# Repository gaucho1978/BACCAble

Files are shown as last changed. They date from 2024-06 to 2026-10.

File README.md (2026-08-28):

## BACCAble 

Website with full info: https://www.tr3ma.com/baccable

Direct contact: https://t.me/gaucholivido

Telegram group for BACCABLE: https://t.me/baccable 

Please donate, with Paypal or Crypto (Bitcoin)

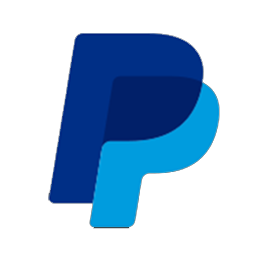
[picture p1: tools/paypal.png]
PayPal (https://www.paypal.me/tr3ma1)

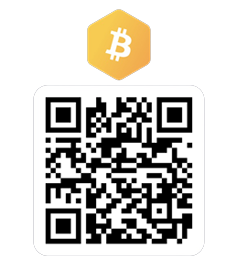
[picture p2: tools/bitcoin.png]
Bitcoin


## CREDITS

*"None of us got where we are solely by pulling ourselves up by our bootstraps. We got here because somebody — a parent, a teacher, an Ivy League crony or a few nuns — bent down and helped us pick up our boots"* Cit. Thurgood Marshall.

Thanks Sniz https://alfatuning.app/

Thanks Alexey, Alfaobd developer https://www.alfaobd.com/

Thanks normaldotcom https://github.com/normaldotcom/canable-fw

Thanks Danardi https://github.com/danardi78/Alfaromeo-Giulia-Stelvio-PIDs/

Thanks Alessandro https://github.com/anegrin

Thanks Ambrotek, Arfa, Tim, Gev, and all the Baccable Community

## DISCLAIMER

BACCABLE is a project developed exclusively for educational and research purposes. The use of this tool on vehicles operating on public roads or in any context that may cause harm to people, property, or violate applicable regulations is strictly prohibited.

The author of this project assumes no responsibility for any damages, malfunctions, or consequences resulting from the use of BACCABLE. The end user bears full civil, criminal, and legal responsibility for its use.

It is strongly recommended not to use this project in real-world vehicle applications.

## DISCLAIMER (ITALIAN VERSION)
BACCABLE è un progetto sviluppato esclusivamente a scopo didattico e di studio. È severamente vietato utilizzare questo strumento su veicoli in circolazione su strade pubbliche o in qualsiasi contesto che possa causare danni a persone, cose o violare normative vigenti.

L'autore del progetto non si assume alcuna responsabilità per eventuali danni, malfunzionamenti o conseguenze derivanti dall'uso di BACCABLE. L'utilizzo di questo strumento è interamente a rischio dell'utente finale, che si assume ogni responsabilità civile, penale e legale.

Si raccomanda di non impiegare questo progetto in applicazioni reali su veicoli.

## Scope
Baccable is able to communicate over can bus on Giulia and Stelvio veichles to implement many functions.
It is available with custom COMPACT board, or, just for partial testing, can be made with canable or ucan boards with some limits. The custom board integrates, on a single board, 3 ST chips, one for each CAN bus, along with efficient power consumption and optimized electromagnetic interference management for the vehicle. It includes additional expansions ports for valves remote control, or any other remote control (in example automatic driveway  gate), dedicated connector for external pedal booster (schizzaForte is the Baccable pedal booster, installed on the accelerator, allows automatic map set according to the selected drive style).
All functions and manuals are available on https://www.tr3ma.com/baccable 
Baccable can be supplied already programmed, ready to plug in diagnostic port.
If you want a ready made Baccable, required info are on https://www.tr3ma.com/baccable

Following info are only for those using canable or ucan boards

## Developers info
I started the development from the famous SLCAN firmware (https://github.com/normaldotcom/canable-fw), by porting it inside stm32Cube environment (I updated usb interface), then I added all the functions described in the manuals.

## Folders content
- Subfolder firmware contains the firmware
- Subfolder hardware/canable contains canable board layout and pcb wiring diagram. It comes from https://github.com/makerbase-mks/CANable-MKS. There are different designs of canable, but theay are all similar.
- Subfolder hardware/box contains the 3d model of the cases to accomodate required components.
- Subfolder hardware/system interconnection contains interconnection diagram to connect required components
- Subfolder tools contains the famous savvyCan sniffer tool for windows (portable) and excel sheet used to calculate pwm and clocks settings.
- Subfolder hardware/newBaccableDedicatedPcb contains the new pcb for Baccable
- Subfolder Manuals contains the manuals

## DASHBOARD MENU functionality Notes

For communication between ucan or canable, you will need to connect canable boards as shown in the following reference image:

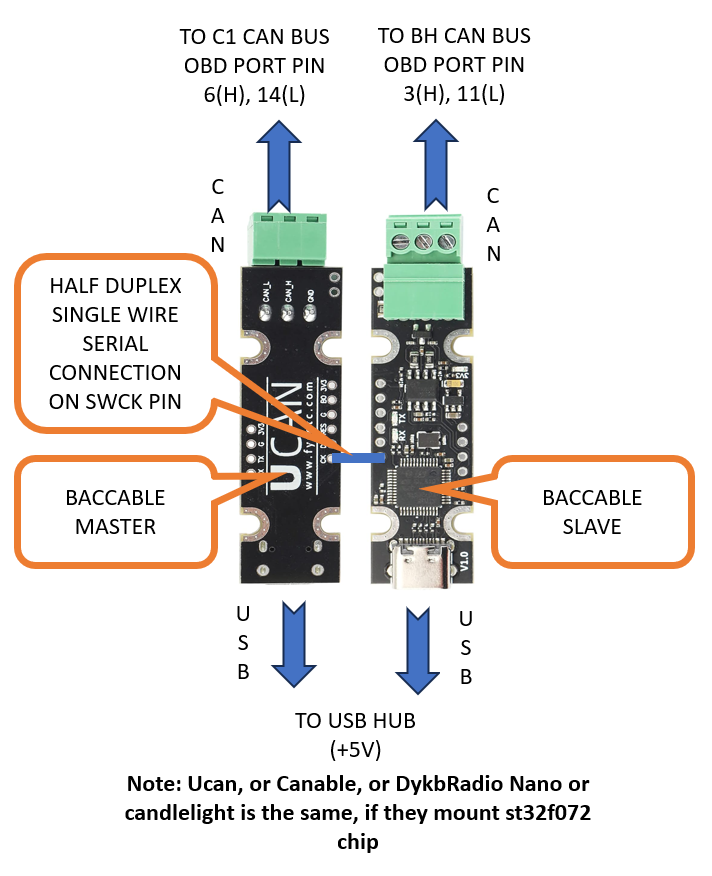
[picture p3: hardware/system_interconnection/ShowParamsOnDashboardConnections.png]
DashboardFunctionInterconnections


## Firmware notes

Note1: The parameters array is customizable

This is the structure of each element:
 
- name[15]:						It is the name of the parameter. shall be short otherwise the string will be cutted and not entirely shown in dashoard 
- reqId:						It is the msg id to request in UDS command. It Typically starts with 18DA....
- reqLen:						It is the total length of the can message to send
- reqData:						It is the entire can message to send. It follows the following UDS syntax:
								First byte is the length of the following bytes, 
								Second byte is the requested service (tipically 0x22, request parameter by ID),
								Third and fourth byte are the DID (the requested parameter).
- replyId:						It is the message ID of the received reply. Tipically if the reqID is 18DAAABB the replyID shall be 18DABBAA
- replyLen:						It is the number of bytes of the parameter that we want to extract from the received message
- replyOffset:					It defines where is located the parameter. 0 means that it is the first byte of the expected field of UDS message, 1 means that we shall start from second byte, and so on.
- replyValOffset: 				Once the parameter is decoded as unsigned integer, the first calculation on the value will be + replyValOffset 
- replyScale:					Once the parameter has been summed with replyValOffset, the result will be multiplied by replyScale
- replyScaleOffset:				Once the parameter has been multiplied by replyScale, the result will be summed to replyScaleOffset
- replyMeasurementUnit[7]:		It is a string appended at the end of the parameter string to define measurement unit. Too long strings will have measurement unit cutted and not shown on the dashboard.
- replyDecimalDigits:			The parameter, after previous calculations, will be converted to string, and rounded to the specified number of decimal digits. 

## BACCABLE Compile Instructions

We introduced automatic compilation on github. Stable releases are downloadable from "Releases" section:  

If you want to compile it on your PC, the easiest way is to use stm32CubeIde software.
Once the project has been opened, select the desired compile option, and the related elf file will be generated under firmware\ledsStripController, in a subfolder named according to the selected compile option. Inside that folder you will find generated elf file.

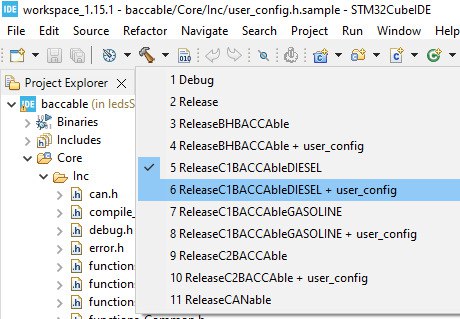
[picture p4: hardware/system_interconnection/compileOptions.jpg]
Compilation Options


select C1, C2, BH release options, depending on the board for which you are compiling it.

Default options are enough for anyone, but if any customization is required, it can be done following instructions contained in file firmware\ledsStripController\Core\Inc\user_config.h.sample

## BACCABLE Flash Instructions

See Manual, paragraph 1.11

## The hardware using CANABLE

I found these compatible devices (It is important that the chip is a stm32F072):

    - Original MKS Canable
    - Canable DykbRadio Nano
    - Fysect ucan
	- candlelight small board ( [https://github.com/linux-automation/candleLightFD](https://github.com/linux-automation/candleLight/) )
		
## Compatible leds strip

Leds Strip ws2811 ip65:  

https://www.ebay.it/itm/325563557492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

https://amzn.to/3W3TifJ

## Usage when configured to act as Canable (Sniffer)
The new function SNIFFER inside Main Setup Menu no more requires to flash dedicated firmware for flashing. See manual.
This section is left for reference.
Old method to flash requires to flash the baccable with another firmware named CANABLE or ACT_AS_CANABLE that you can find in the compiled files.

When flashed with CANABLE firmware, it acts as the classic SLCAN firmware. it means that you can use it with a pc equipped with savvycan tool, in order to sniff packets in the canbus. 
With such configuration the device is seen by the pc as a virtual serial port implementing the following serial commands:

- O - Open channel
- C - Close channel
- S0 - Set bitrate to 10k
- S1 - Set bitrate to 20k
- S2 - Set bitrate to 50k
- S3 - Set bitrate to 100k
- S4 - Set bitrate to 125k
- S5 - Set bitrate to 250k
- S6 - Set bitrate to 500k
- S7 - Set bitrate to 750k
- S8 - Set bitrate to 1M
- M0 - Set mode to normal mode (default)
- M1 - Set mode to silent mode
- A0 - Disable automatic retransmission
- A1 - Enable automatic retransmission (default)
- TIIIIIIIILDD... - Transmit data frame (Extended ID) [ID, length, data]
- tIIILDD... - Transmit data frame (Standard ID) [ID, length, data]
- RIIIIIIIIL - Transmit remote frame (Extended ID) [ID, length]
- rIIIL - Transmit remote frame (Standard ID) [ID, length]
- V - Returns firmware version and remote path as a string
Note: Channel configuration commands must be sent before opening the channel. The channel must be opened before transmitting frames.

This firmware currently does not provide any ACK/NACK feedback for serial commands.

## Understanding LED protocol

The approach used to control WS281x leds strip controller was derived from this: https://github.com/MaJerle/stm32-ws2811-ws2812-ws2812b-ws281x-tim-pwm-dma-timer where it is used a timer to start a pwm, then DMA allows a fast change of the duty cycle of the pwm.

Summarizing, the ws281x uses a control signal where each bit is transmitted as 1 or 0 with a pwm signal (with 2 different duty cycle for 0 and for 1 logic levels).
The ws281x protocol expects a 24 bits sequence (3x8) for each led, where each 8 bits defines a color (red, green and blue). 
First led will get the first 24 bits, then it sends the rest to the next led. each led does the same.
A pause in the transmission determines the end of the frame, then a new frame can be sent.
The protocol and the timings are described in the ws281x datasheet

WS2811 and WS2812 protocol is specific one and has defined values:

- Transfer rate is `800 kHz`, or `1.25us` pulse length for each bit
- Transfer length is `24` pulses for each led, that's `30us` for one LED
- Each logical bit (`1` or `0`) consists of high and low part, with different length
- Reset pulse is needed prior updating led strip, to synchronize sequence

WS2811 & WS2812 & WS2812B LED protocol

> Minimum reset pulse length depends on WS281x device. Check datasheet for your particular unit. WS2812B says `> 50us`, while WS2811 says `> 280us`.

## STM32 DMA

DMA controllers in STM32s support various operations, one of them being super handy for our WS LED driver, called *circular operation mode*.
*Circular mode* will continuously transmit data from memory to peripheral (or, in general, can also go opposite direction) and periodically send *transfer-complete* or *half-transfer-complete* interrupts to the application.

STM32 DMA circular mode

We will use *HT* and *TC* events extensively, as they will be use to *prepare data* for next operations to transfer all bits for all leds.

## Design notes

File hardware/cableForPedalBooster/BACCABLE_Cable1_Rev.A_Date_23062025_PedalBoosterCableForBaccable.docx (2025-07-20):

PEDAL BOOSTER CABLE FOR BACCABLE

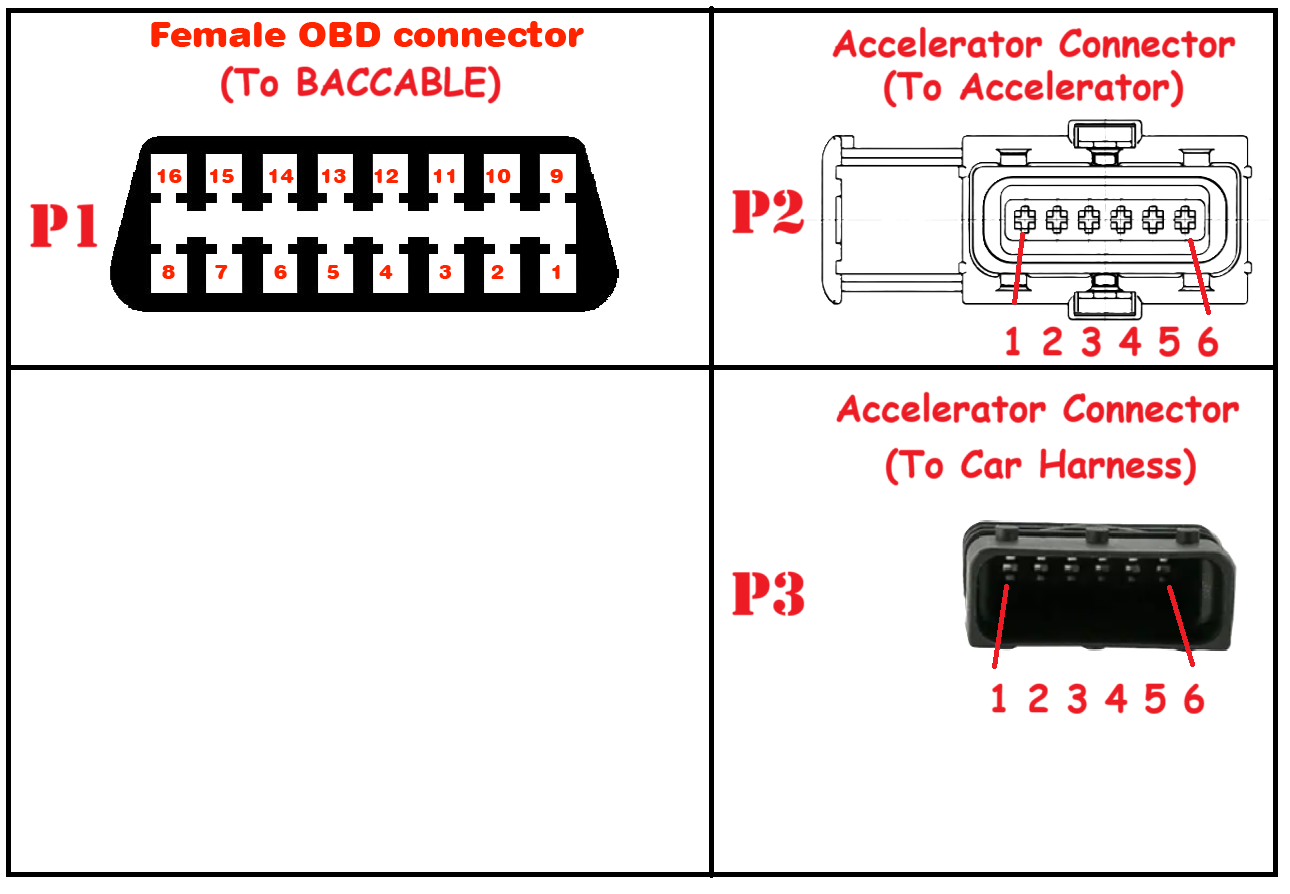
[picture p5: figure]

From Connector | | R101 (200k ohm) R102 (200k ohm) | To Connector
OBD (P1) | 16 (+12V) | | +12V | Car OBD or Car Harness before SGW
| 4 (GND) | | GND
| 6 (C1H) | | Can Bus C1 H
| 14 (C1L) | | Can Bus C1 L
| 12 (C2H) | | Can Bus C2 H
| 13 (C2L) | | Can Bus C2 L
| 3 (BH H) | | Can Bus BH H
| 11 (BH L) | | Can Bus BH L
| | | 1 (V2+) | Accelerator (P2)
| | | 2 (V1+)
| 10 (STS2) | | 3 (Acc1)
| | | 4 (V1-)
| | | 5 (V2-)
| 7 (STS3) | | 6(Acc2)
| | | 2 (V1+) | Accelerator Harness (P3)
| 15 (CMD2) | | 3 (Acc1)
| 4 (GND) | | 4 (V1-)
| 4 (GND) | | 5 (V2-)
| | | 1 (V2+)
| 2 (CMD3) | | 6(Acc2)

BACCABLE_Cable1 Rev.B – Date: 26/06/2025

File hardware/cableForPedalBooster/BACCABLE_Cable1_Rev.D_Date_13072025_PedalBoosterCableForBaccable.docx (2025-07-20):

PEDAL BOOSTER CABLE FOR BACCABLE


From Connector | | | To Connector
OBD (P1) | 16 (+12V) | | 16 (+12V) | Car OBD or Car Harness before SGW
| 4 (GND) | | 4 (GND)
| 6 (C1H) | | 6 (Can Bus C1 H)
| 14 (C1L) | | 14 (Can Bus C1 L)
| 12 (C2H) | | 12 (Can Bus C2 H)
| 13 (C2L) | | 13 (Can Bus C2 L)
| 3 (BH H) | | 3 (Can Bus BH H)
| 11 (BH L) | | 11 (Can Bus BH L)
| | | 1 (V2+) | Accelerator (P2)
| | | 2 (V1+)
| 10 (STS2) | | 3 (Acc1)
| | | 4 (V1-)
| | | 5 (V2-)
| 7 (STS3) | | 6(Acc2)
| 15 Vref2 | | 2 (V1+) | Accelerator Harness (P3)
| 1 (CMD2) | | 3 (Acc1)
| 4 (GND) | | 4 (V1-)
| | | 5 (V2-)
| 2 Vref3 | | 1 (V2+)
| 9 (CMD3) | | 6(Acc2)

BACCABLE_Cable1 Rev.D – Date: 13/07/2025

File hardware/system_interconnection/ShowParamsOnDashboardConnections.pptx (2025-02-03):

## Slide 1

BACCABLE MASTER

HALF DUPLEX SINGLE WIRE SERIAL CONNECTION ON SWCK PIN

USB

CAN

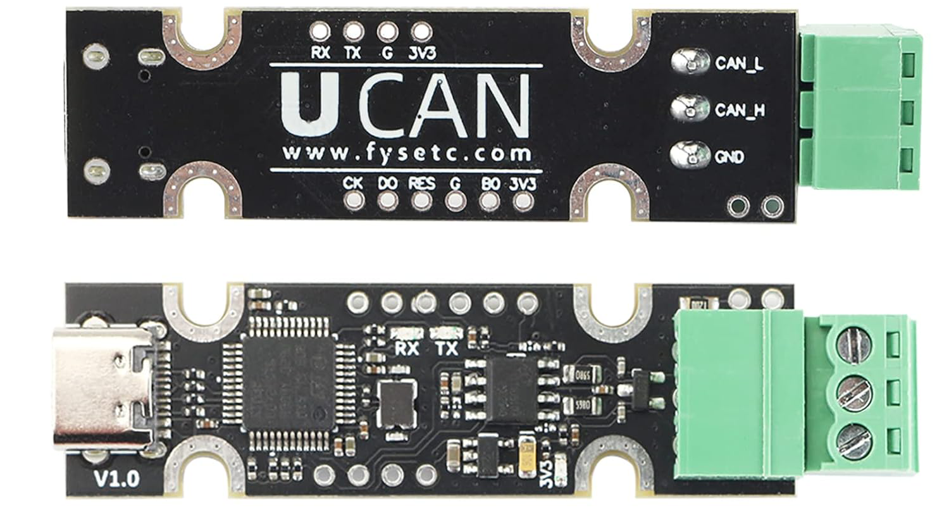
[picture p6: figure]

TO C1 CAN BUS
OBD PORT PIN 6(H), 14(L)

Note: Ucan, or Canable, or DykbRadio Nano or candlelight is the same, if they mount st32f072 chip

TO USB HUB (+5V)

USB

TO BH CAN BUS
OBD PORT PIN 3(H), 11(L)

CAN

BACCABLE SLAVE

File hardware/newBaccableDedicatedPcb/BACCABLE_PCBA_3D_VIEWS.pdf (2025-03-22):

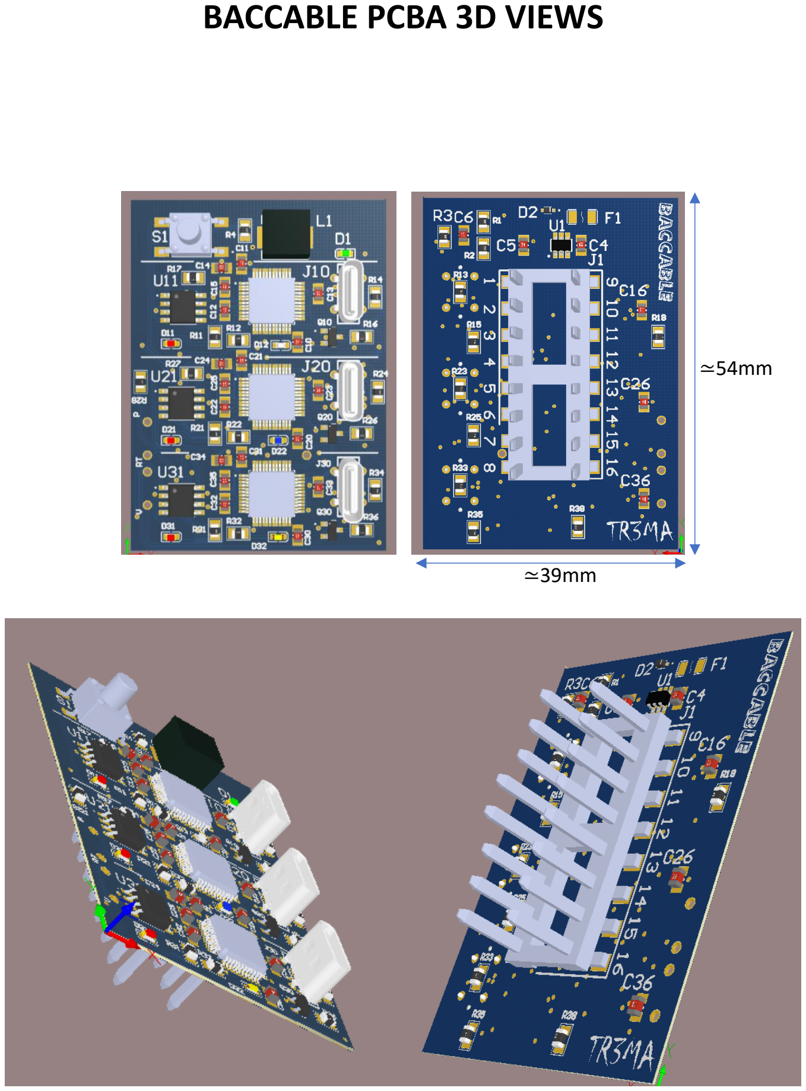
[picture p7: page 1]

BACCABLE PCBA 3D VIEWS

≃39mm

≃54mm

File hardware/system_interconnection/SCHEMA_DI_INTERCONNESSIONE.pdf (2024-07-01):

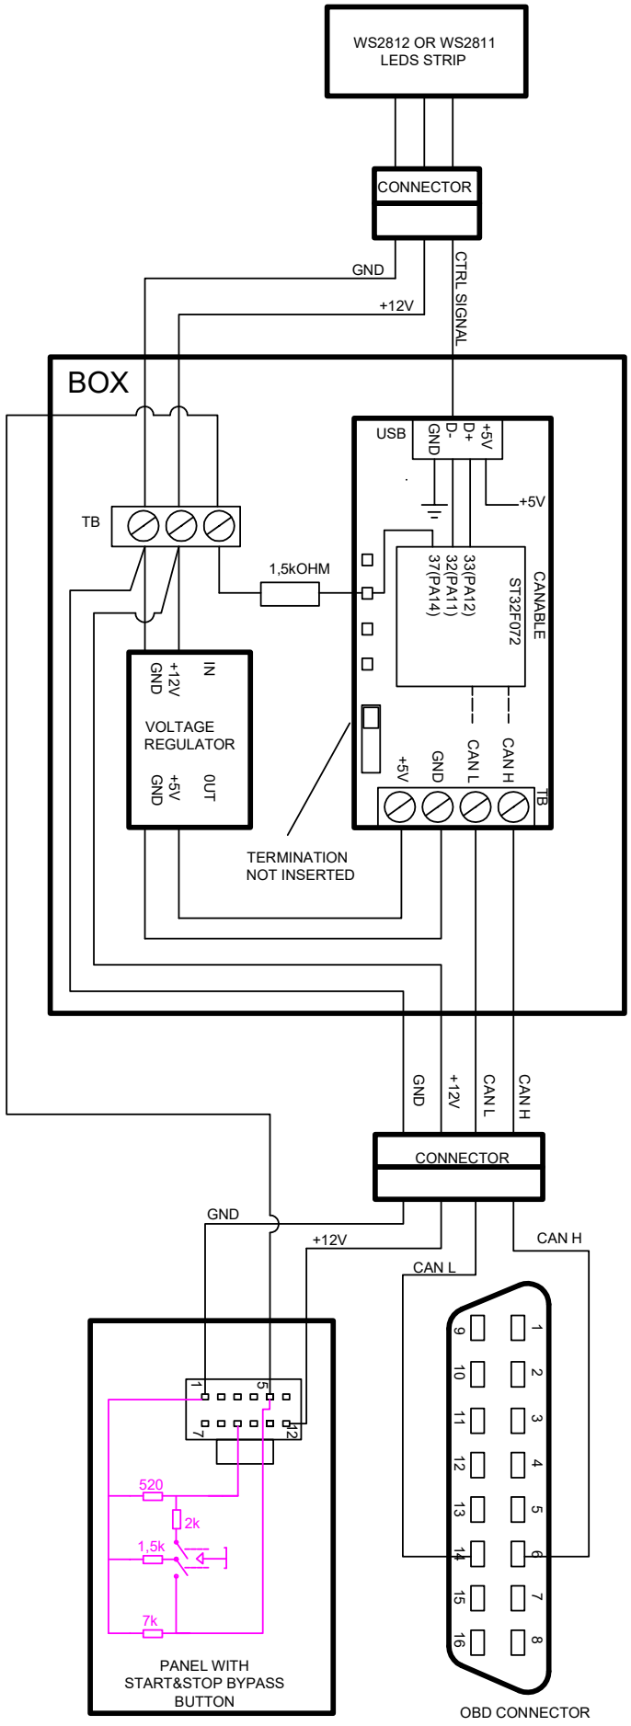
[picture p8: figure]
USB; GND D- D++5V; +5VTB; TERMINATION; NOT INSERTED; CAN L; CAN H GND ⁺⁵V; CANABLE; VOLTAGE; REGULATOR GND ⁺¹²V; IN GND ⁺⁵V; 1,5kOHM; BOX; CTRL SIGNAL +12V; GND; LEDS STRIP GND; CAN H; CONNECTOR; PANEL WITH START&STOP BYPASS BUTTON; CAN L 12; 5 OBD CONNECTOR

1 9 10 11 12 13 14 15 16 1 2 3 4 5 6 7 8

## Note: impedance inside ECU before pin 5= 910ohm impedance inside ECU before pin 9= 99ohm Note2: by using 470 ohm resistor in place of 1,5k you will disable parking acoustic signal (the other button on the panel)

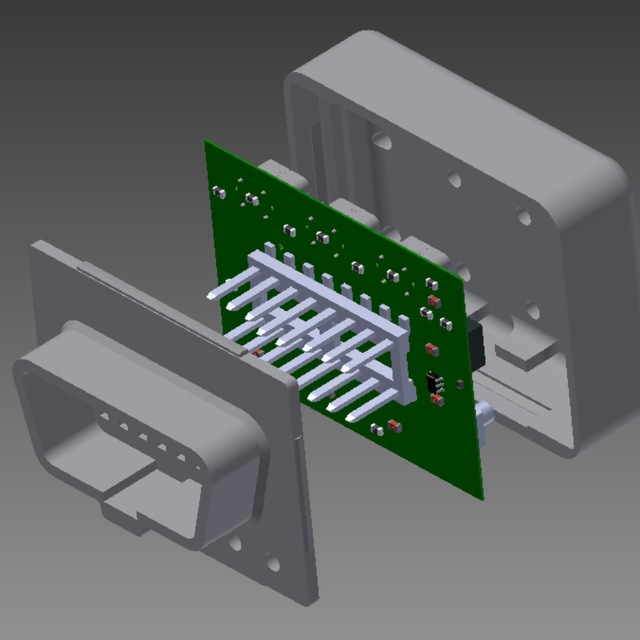
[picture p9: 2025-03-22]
hardware/box/baccable_lastest_case_for_new_PCB/preview.jpg

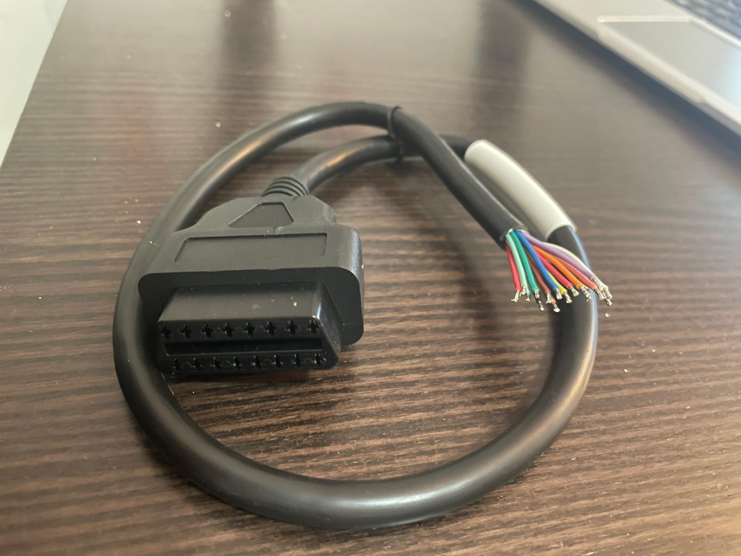
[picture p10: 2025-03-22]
hardware/newBaccableDedicatedPcb/cable.jpg

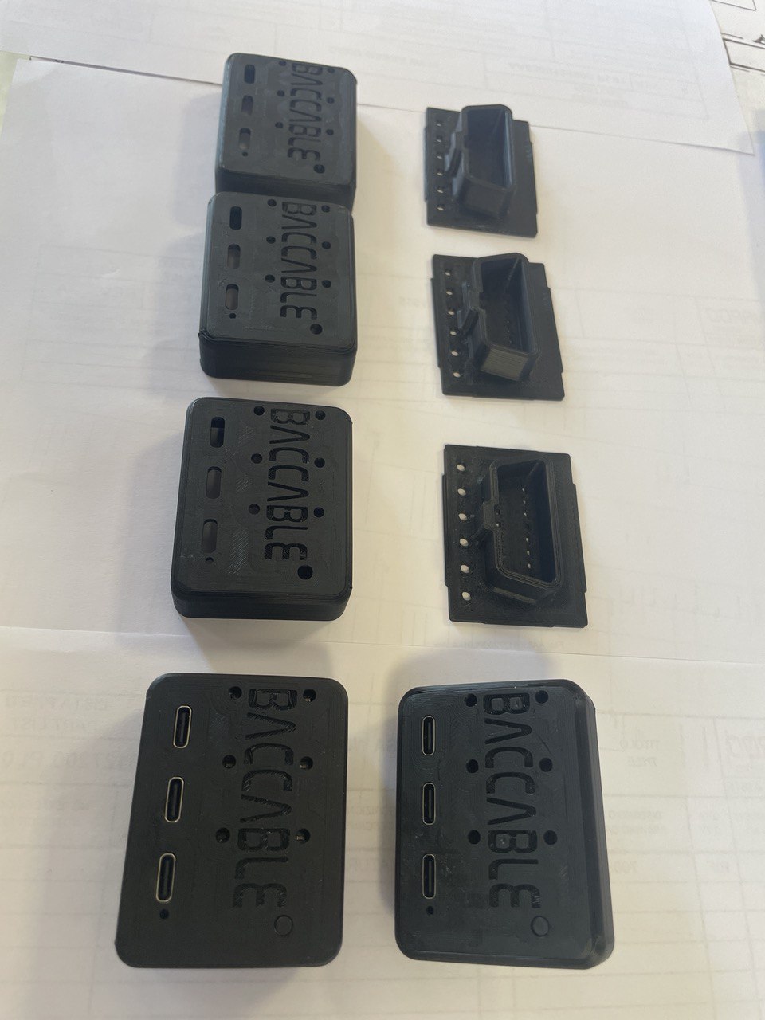
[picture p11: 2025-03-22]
hardware/box/baccable_lastest_case_for_new_PCB/preview4.jpg

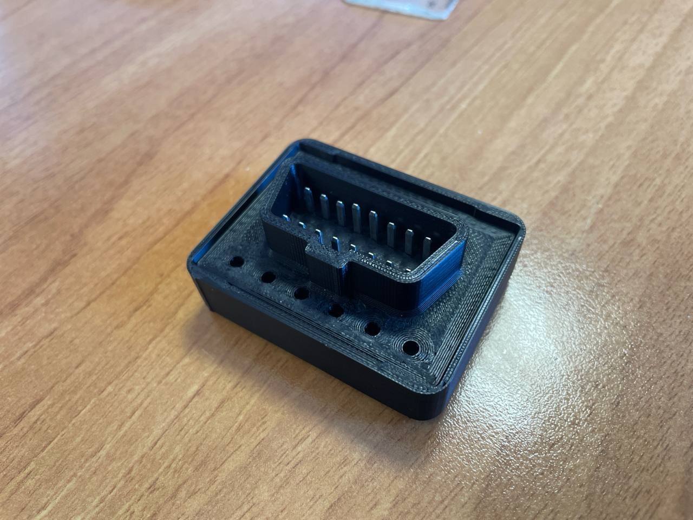
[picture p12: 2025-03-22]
hardware/box/baccable_lastest_case_for_new_PCB/preview3.jpg

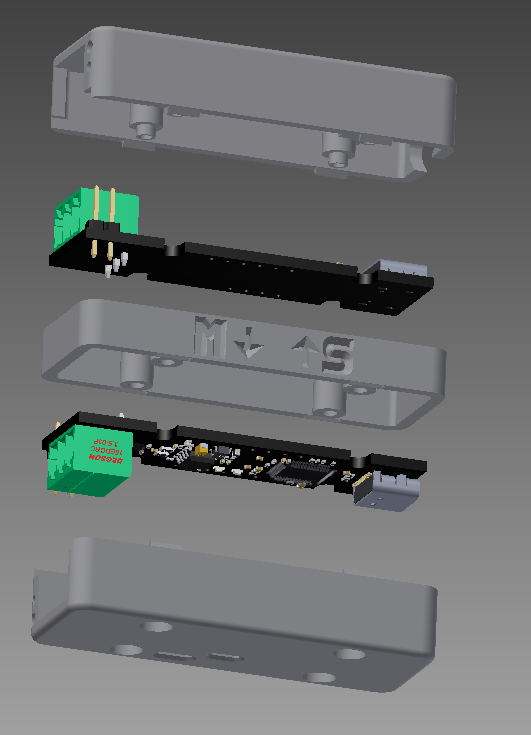
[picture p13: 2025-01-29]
hardware/box/dual_fysect_ucan/preview.png

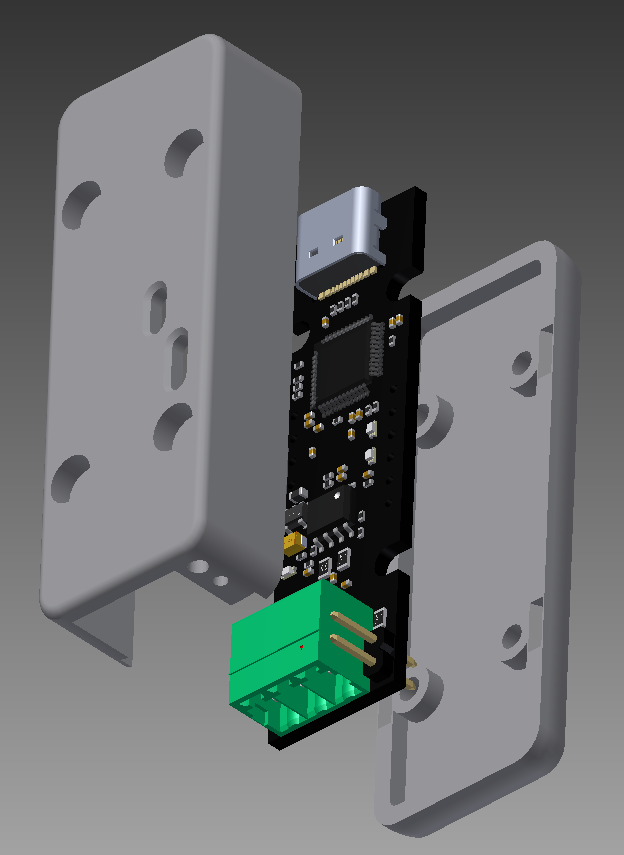
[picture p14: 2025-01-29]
hardware/box/single_fysect_ucan/preview.png

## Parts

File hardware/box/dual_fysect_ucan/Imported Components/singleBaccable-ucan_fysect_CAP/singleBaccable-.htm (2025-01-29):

Autodesk Inventor Translation Report | giovedì 23 gennaio 2025 (19:19)
Source File: | E:\Dati\Documenti_Emanuele\Linguaggi_di_Programmazione\ST MCU\baccable\canable\CANableAndLedsStripController\hardware\box\dual fysect ucan\singleBaccable-ucan_fysect_CAP.stl
Translator Type: | STL | Sending System:
Author: |  | Translation Time: | 00:00:00
Options
Import Type: | N/A
Entity Types to Import: | Meshes
Import into Repair Environment: | N/A
Import Assembly as Single Part: | N/A
Create Surfaces As: | N/A
Check Parts during Load: | N/A
Auto Stitch: | N/A
Enable Advanced Healing: | N/A
Color Red/Green/Blue Order: | RGB
+/- | Name | Inventor File | Status
[ ] | singleBaccable-.ipt | E:\Dati\Documenti_Emanuele\Linguaggi_di_Programmazione\ST MCU\baccable\canable\CANableAndLedsStripController\hardware\box\dual fysect ucan\Imported Components\singleBaccable-ucan_fysect_CAP\singleBaccable-.ipt | Successful

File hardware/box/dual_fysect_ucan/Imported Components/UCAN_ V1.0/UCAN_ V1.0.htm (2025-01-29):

Autodesk Inventor Translation Report | giovedì 23 gennaio 2025 (19:20)
Source File: | E:\Dati\Documenti_Emanuele\Linguaggi_di_Programmazione\ST MCU\baccable\canable\CANableAndLedsStripController\hardware\box\dual fysect ucan\UCAN_ V1.0.step
Translator Type: | STEP | Sending System: | Open CASCADE 7.5
Author: | Author | Translation Time: | 00:00:12
Options
Import Type: | N/A
Entity Types to Import: | Solids, Surfaces, Wires, Points
Import into Repair Environment: | Yes
Import Assembly as Single Part: | No
Create Surfaces As: | Single Composite Feature
Check Parts during Load: | No
Auto Stitch: | No
Enable Advanced Healing: | N/A
+/- | Name | Inventor File | Status
[ ] | UCAN_ V1.0.iam | E:\Dati\Documenti_Emanuele\Linguaggi_di_Programmazione\ST MCU\baccable\canable\CANableAndLedsStripController\hardware\box\dual fysect ucan\Imported Components\UCAN_ V1.0\UCAN_ V1.0.iam | Successful
[ ] | Open CASCADE STEP translator 7.5 1.ipt | E:\Dati\Documenti_Emanuele\Linguaggi_di_Programmazione\ST MCU\baccable\canable\CANableAndLedsStripController\hardware\box\dual fysect ucan\Imported Components\UCAN_ V1.0\Open CASCADE STEP translator 7.5 1.ipt | Successful
[ ] | Open CASCADE STEP translator 7.5 2.ipt | E:\Dati\Documenti_Emanuele\Linguaggi_di_Programmazione\ST MCU\baccable\canable\CANableAndLedsStripController\hardware\box\dual fysect ucan\Imported Components\UCAN_ V1.0\Open CASCADE STEP translator 7.5 2.ipt | Successful
[ ] | Open CASCADE STEP translator 7.5 3.ipt | E:\Dati\Documenti_Emanuele\Linguaggi_di_Programmazione\ST MCU\baccable\canable\CANableAndLedsStripController\hardware\box\dual fysect ucan\Imported Components\UCAN_ V1.0\Open CASCADE STEP translator 7.5 3.ipt | Successful
[ ] | Open CASCADE STEP translator 7.5 4.ipt | E:\Dati\Documenti_Emanuele\Linguaggi_di_Programmazione\ST MCU\baccable\canable\CANableAndLedsStripController\hardware\box\dual fysect ucan\Imported Components\UCAN_ V1.0\Open CASCADE STEP translator 7.5 4.ipt | Successful
[ ] | Open CASCADE STEP translator 7.5 5.ipt | E:\Dati\Documenti_Emanuele\Linguaggi_di_Programmazione\ST MCU\baccable\canable\CANableAndLedsStripController\hardware\box\dual fysect ucan\Imported Components\UCAN_ V1.0\Open CASCADE STEP translator 7.5 5.ipt | Successful
[ ] | Open CASCADE STEP translator 7.5 6.ipt | E:\Dati\Documenti_Emanuele\Linguaggi_di_Programmazione\ST MCU\baccable\canable\CANableAndLedsStripController\hardware\box\dual fysect ucan\Imported Components\UCAN_ V1.0\Open CASCADE STEP translator 7.5 6.ipt | Successful
[ ] | Open CASCADE STEP translator 7.5 7.ipt | E:\Dati\Documenti_Emanuele\Linguaggi_di_Programmazione\ST MCU\baccable\canable\CANableAndLedsStripController\hardware\box\dual fysect ucan\Imported Components\UCAN_ V1.0\Open CASCADE STEP translator 7.5 7.ipt | Successful
[ ] | Open CASCADE STEP translator 7.5 8.ipt | E:\Dati\Documenti_Emanuele\Linguaggi_di_Programmazione\ST MCU\baccable\canable\CANableAndLedsStripController\hardware\box\dual fysect ucan\Imported Components\UCAN_ V1.0\Open CASCADE STEP translator 7.5 8.ipt | Successful
[ ] | Open CASCADE STEP translator 7.5 9.ipt | E:\Dati\Documenti_Emanuele\Linguaggi_di_Programmazione\ST MCU\baccable\canable\CANableAndLedsStripController\hardware\box\dual fysect ucan\Imported Components\UCAN_ V1.0\Open CASCADE STEP translator 7.5 9.ipt | Successful
[ ] | Open CASCADE STEP translator 7.5 10.ipt | E:\Dati\Documenti_Emanuele\Linguaggi_di_Programmazione\ST MCU\baccable\canable\CANableAndLedsStripController\hardware\box\dual fysect ucan\Imported Components\UCAN_ V1.0\Open CASCADE STEP translator 7.5 10.ipt | Successful
[ ] | Open CASCADE STEP translator 7.5 11.ipt | E:\Dati\Documenti_Emanuele\Linguaggi_di_Programmazione\ST MCU\baccable\canable\CANableAndLedsStripController\hardware\box\dual fysect ucan\Imported Components\UCAN_ V1.0\Open CASCADE STEP translator 7.5 11.ipt | Successful
[ ] | Open CASCADE STEP translator 7.5 12.ipt | E:\Dati\Documenti_Emanuele\Linguaggi_di_Programmazione\ST MCU\baccable\canable\CANableAndLedsStripController\hardware\box\dual fysect ucan\Imported Components\UCAN_ V1.0\Open CASCADE STEP translator 7.5 12.ipt | Successful
[ ] | Open CASCADE STEP translator 7.5 13.ipt | E:\Dati\Documenti_Emanuele\Linguaggi_di_Programmazione\ST MCU\baccable\canable\CANableAndLedsStripController\hardware\box\dual fysect ucan\Imported Components\UCAN_ V1.0\Open CASCADE STEP translator 7.5 13.ipt | Successful
[ ] | Open CASCADE STEP translator 7.5 14.ipt | E:\Dati\Documenti_Emanuele\Linguaggi_di_Programmazione\ST MCU\baccable\canable\CANableAndLedsStripController\hardware\box\dual fysect ucan\Imported Components\UCAN_ V1.0\Open CASCADE STEP translator 7.5 14.ipt | Successful
[ ] | Open CASCADE STEP translator 7.5 15.ipt | E:\Dati\Documenti_Emanuele\Linguaggi_di_Programmazione\ST MCU\baccable\canable\CANableAndLedsStripController\hardware\box\dual fysect ucan\Imported Components\UCAN_ V1.0\Open CASCADE STEP translator 7.5 15.ipt | Successful
[ ] | Open CASCADE STEP translator 7.5 16.ipt | E:\Dati\Documenti_Emanuele\Linguaggi_di_Programmazione\ST MCU\baccable\canable\CANableAndLedsStripController\hardware\box\dual fysect ucan\Imported Components\UCAN_ V1.0\Open CASCADE STEP translator 7.5 16.ipt | Successful
[ ] | Open CASCADE STEP translator 7.5 17.ipt | E:\Dati\Documenti_Emanuele\Linguaggi_di_Programmazione\ST MCU\baccable\canable\CANableAndLedsStripController\hardware\box\dual fysect ucan\Imported Components\UCAN_ V1.0\Open CASCADE STEP translator 7.5 17.ipt | Successful
[ ] | Open CASCADE STEP translator 7.5 18.ipt | E:\Dati\Documenti_Emanuele\Linguaggi_di_Programmazione\ST MCU\baccable\canable\CANableAndLedsStripController\hardware\box\dual fysect ucan\Imported Components\UCAN_ V1.0\Open CASCADE STEP translator 7.5 18.ipt | Successful
[ ] | Open CASCADE STEP translator 7.5 19.ipt | E:\Dati\Documenti_Emanuele\Linguaggi_di_Programmazione\ST MCU\baccable\canable\CANableAndLedsStripController\hardware\box\dual fysect ucan\Imported Components\UCAN_ V1.0\Open CASCADE STEP translator 7.5 19.ipt | Successful
[ ] | Open CASCADE STEP translator 7.5 20.ipt | E:\Dati\Documenti_Emanuele\Linguaggi_di_Programmazione\ST MCU\baccable\canable\CANableAndLedsStripController\hardware\box\dual fysect ucan\Imported Components\UCAN_ V1.0\Open CASCADE STEP translator 7.5 20.ipt | Successful
[ ] | Open CASCADE STEP translator 7.5 21.ipt | E:\Dati\Documenti_Emanuele\Linguaggi_di_Programmazione\ST MCU\baccable\canable\CANableAndLedsStripController\hardware\box\dual fysect ucan\Imported Components\UCAN_ V1.0\Open CASCADE STEP translator 7.5 21.ipt | Successful
[ ] | Open CASCADE STEP translator 7.5 22.ipt | E:\Dati\Documenti_Emanuele\Linguaggi_di_Programmazione\ST MCU\baccable\canable\CANableAndLedsStripController\hardware\box\dual fysect ucan\Imported Components\UCAN_ V1.0\Open CASCADE STEP translator 7.5 22.ipt | Successful
[ ] | Open CASCADE STEP translator 7.5 23.ipt | E:\Dati\Documenti_Emanuele\Linguaggi_di_Programmazione\ST MCU\baccable\canable\CANableAndLedsStripController\hardware\box\dual fysect ucan\Imported Components\UCAN_ V1.0\Open CASCADE STEP translator 7.5 23.ipt | Successful
[ ] | Open CASCADE STEP translator 7.5 24.ipt | E:\Dati\Documenti_Emanuele\Linguaggi_di_Programmazione\ST MCU\baccable\canable\CANableAndLedsStripController\hardware\box\dual fysect ucan\Imported Components\UCAN_ V1.0\Open CASCADE STEP translator 7.5 24.ipt | Successful
[ ] | Open CASCADE STEP translator 7.5 25.ipt | E:\Dati\Documenti_Emanuele\Linguaggi_di_Programmazione\ST MCU\baccable\canable\CANableAndLedsStripController\hardware\box\dual fysect ucan\Imported Components\UCAN_ V1.0\Open CASCADE STEP translator 7.5 25.ipt | Successful
[ ] | Open CASCADE STEP translator 7.5 26.ipt | E:\Dati\Documenti_Emanuele\Linguaggi_di_Programmazione\ST MCU\baccable\canable\CANableAndLedsStripController\hardware\box\dual fysect ucan\Imported Components\UCAN_ V1.0\Open CASCADE STEP translator 7.5 26.ipt | Successful
[ ] | Open CASCADE STEP translator 7.5 27.ipt | E:\Dati\Documenti_Emanuele\Linguaggi_di_Programmazione\ST MCU\baccable\canable\CANableAndLedsStripController\hardware\box\dual fysect ucan\Imported Components\UCAN_ V1.0\Open CASCADE STEP translator 7.5 27.ipt | Successful
[ ] | Open CASCADE STEP translator 7.5 28.ipt | E:\Dati\Documenti_Emanuele\Linguaggi_di_Programmazione\ST MCU\baccable\canable\CANableAndLedsStripController\hardware\box\dual fysect ucan\Imported Components\UCAN_ V1.0\Open CASCADE STEP translator 7.5 28.ipt | Successful
[ ] | Open CASCADE STEP translator 7.5 29.ipt | E:\Dati\Documenti_Emanuele\Linguaggi_di_Programmazione\ST MCU\baccable\canable\CANableAndLedsStripController\hardware\box\dual fysect ucan\Imported Components\UCAN_ V1.0\Open CASCADE STEP translator 7.5 29.ipt | Successful
[ ] | Open CASCADE STEP translator 7.5 30.ipt | E:\Dati\Documenti_Emanuele\Linguaggi_di_Programmazione\ST MCU\baccable\canable\CANableAndLedsStripController\hardware\box\dual fysect ucan\Imported Components\UCAN_ V1.0\Open CASCADE STEP translator 7.5 30.ipt | Successful
[ ] | Open CASCADE STEP translator 7.5 31.ipt | E:\Dati\Documenti_Emanuele\Linguaggi_di_Programmazione\ST MCU\baccable\canable\CANableAndLedsStripController\hardware\box\dual fysect ucan\Imported Components\UCAN_ V1.0\Open CASCADE STEP translator 7.5 31.ipt | Successful
[ ] | Open CASCADE STEP translator 7.5 32.ipt | E:\Dati\Documenti_Emanuele\Linguaggi_di_Programmazione\ST MCU\baccable\canable\CANableAndLedsStripController\hardware\box\dual fysect ucan\Imported Components\UCAN_ V1.0\Open CASCADE STEP translator 7.5 32.ipt | Successful
[ ] | Open CASCADE STEP translator 7.5 33.ipt | E:\Dati\Documenti_Emanuele\Linguaggi_di_Programmazione\ST MCU\baccable\canable\CANableAndLedsStripController\hardware\box\dual fysect ucan\Imported Components\UCAN_ V1.0\Open CASCADE STEP translator 7.5 33.ipt | Successful
[ ] | Open CASCADE STEP translator 7.5 34.ipt | E:\Dati\Documenti_Emanuele\Linguaggi_di_Programmazione\ST MCU\baccable\canable\CANableAndLedsStripController\hardware\box\dual fysect ucan\Imported Components\UCAN_ V1.0\Open CASCADE STEP translator 7.5 34.ipt | Successful
[ ] | Open CASCADE STEP translator 7.5 35.ipt | E:\Dati\Documenti_Emanuele\Linguaggi_di_Programmazione\ST MCU\baccable\canable\CANableAndLedsStripController\hardware\box\dual fysect ucan\Imported Components\UCAN_ V1.0\Open CASCADE STEP translator 7.5 35.ipt | Successful
[ ] | Open CASCADE STEP translator 7.5 36.ipt | E:\Dati\Documenti_Emanuele\Linguaggi_di_Programmazione\ST MCU\baccable\canable\CANableAndLedsStripController\hardware\box\dual fysect ucan\Imported Components\UCAN_ V1.0\Open CASCADE STEP translator 7.5 36.ipt | Successful
[ ] | Open CASCADE STEP translator 7.5 37.ipt | E:\Dati\Documenti_Emanuele\Linguaggi_di_Programmazione\ST MCU\baccable\canable\CANableAndLedsStripController\hardware\box\dual fysect ucan\Imported Components\UCAN_ V1.0\Open CASCADE STEP translator 7.5 37.ipt | Successful
[ ] | Open CASCADE STEP translator 7.5 38.ipt | E:\Dati\Documenti_Emanuele\Linguaggi_di_Programmazione\ST MCU\baccable\canable\CANableAndLedsStripController\hardware\box\dual fysect ucan\Imported Components\UCAN_ V1.0\Open CASCADE STEP translator 7.5 38.ipt | Successful
[ ] | Open CASCADE STEP translator 7.5 39.ipt | E:\Dati\Documenti_Emanuele\Linguaggi_di_Programmazione\ST MCU\baccable\canable\CANableAndLedsStripController\hardware\box\dual fysect ucan\Imported Components\UCAN_ V1.0\Open CASCADE STEP translator 7.5 39.ipt | Successful
[ ] | Open CASCADE STEP translator 7.5 40.ipt | E:\Dati\Documenti_Emanuele\Linguaggi_di_Programmazione\ST MCU\baccable\canable\CANableAndLedsStripController\hardware\box\dual fysect ucan\Imported Components\UCAN_ V1.0\Open CASCADE STEP translator 7.5 40.ipt | Successful
[ ] | Open CASCADE STEP translator 7.5 41.ipt | E:\Dati\Documenti_Emanuele\Linguaggi_di_Programmazione\ST MCU\baccable\canable\CANableAndLedsStripController\hardware\box\dual fysect ucan\Imported Components\UCAN_ V1.0\Open CASCADE STEP translator 7.5 41.ipt | Successful
[ ] | Open CASCADE STEP translator 7.5 42.ipt | E:\Dati\Documenti_Emanuele\Linguaggi_di_Programmazione\ST MCU\baccable\canable\CANableAndLedsStripController\hardware\box\dual fysect ucan\Imported Components\UCAN_ V1.0\Open CASCADE STEP translator 7.5 42.ipt | Successful
[ ] | Open CASCADE STEP translator 7.5 43.ipt | E:\Dati\Documenti_Emanuele\Linguaggi_di_Programmazione\ST MCU\baccable\canable\CANableAndLedsStripController\hardware\box\dual fysect ucan\Imported Components\UCAN_ V1.0\Open CASCADE STEP translator 7.5 43.ipt | Successful
[ ] | Open CASCADE STEP translator 7.5 44.ipt | E:\Dati\Documenti_Emanuele\Linguaggi_di_Programmazione\ST MCU\baccable\canable\CANableAndLedsStripController\hardware\box\dual fysect ucan\Imported Components\UCAN_ V1.0\Open CASCADE STEP translator 7.5 44.ipt | Successful
[ ] | Open CASCADE STEP translator 7.5 45.ipt | E:\Dati\Documenti_Emanuele\Linguaggi_di_Programmazione\ST MCU\baccable\canable\CANableAndLedsStripController\hardware\box\dual fysect ucan\Imported Components\UCAN_ V1.0\Open CASCADE STEP translator 7.5 45.ipt | Successful
[ ] | Open CASCADE STEP translator 7.5 46.ipt | E:\Dati\Documenti_Emanuele\Linguaggi_di_Programmazione\ST MCU\baccable\canable\CANableAndLedsStripController\hardware\box\dual fysect ucan\Imported Components\UCAN_ V1.0\Open CASCADE STEP translator 7.5 46.ipt | Successful
[ ] | Open CASCADE STEP translator 7.5 47.ipt | E:\Dati\Documenti_Emanuele\Linguaggi_di_Programmazione\ST MCU\baccable\canable\CANableAndLedsStripController\hardware\box\dual fysect ucan\Imported Components\UCAN_ V1.0\Open CASCADE STEP translator 7.5 47.ipt | Successful
[ ] | Open CASCADE STEP translator 7.5 48.ipt | E:\Dati\Documenti_Emanuele\Linguaggi_di_Programmazione\ST MCU\baccable\canable\CANableAndLedsStripController\hardware\box\dual fysect ucan\Imported Components\UCAN_ V1.0\Open CASCADE STEP translator 7.5 48.ipt | Successful
[ ] | Open CASCADE STEP translator 7.5 49.ipt | E:\Dati\Documenti_Emanuele\Linguaggi_di_Programmazione\ST MCU\baccable\canable\CANableAndLedsStripController\hardware\box\dual fysect ucan\Imported Components\UCAN_ V1.0\Open CASCADE STEP translator 7.5 49.ipt | Successful
[ ] | Open CASCADE STEP translator 7.5 50.ipt | E:\Dati\Documenti_Emanuele\Linguaggi_di_Programmazione\ST MCU\baccable\canable\CANableAndLedsStripController\hardware\box\dual fysect ucan\Imported Components\UCAN_ V1.0\Open CASCADE STEP translator 7.5 50.ipt | Successful
[ ] | Open CASCADE STEP translator 7.5 51.ipt | E:\Dati\Documenti_Emanuele\Linguaggi_di_Programmazione\ST MCU\baccable\canable\CANableAndLedsStripController\hardware\box\dual fysect ucan\Imported Components\UCAN_ V1.0\Open CASCADE STEP translator 7.5 51.ipt | Successful
[ ] | Open CASCADE STEP translator 7.5 52.ipt | E:\Dati\Documenti_Emanuele\Linguaggi_di_Programmazione\ST MCU\baccable\canable\CANableAndLedsStripController\hardware\box\dual fysect ucan\Imported Components\UCAN_ V1.0\Open CASCADE STEP translator 7.5 52.ipt | Successful
[ ] | Open CASCADE STEP translator 7.5 53.ipt | E:\Dati\Documenti_Emanuele\Linguaggi_di_Programmazione\ST MCU\baccable\canable\CANableAndLedsStripController\hardware\box\dual fysect ucan\Imported Components\UCAN_ V1.0\Open CASCADE STEP translator 7.5 53.ipt | Successful
[ ] | Open CASCADE STEP translator 7.5 54.ipt | E:\Dati\Documenti_Emanuele\Linguaggi_di_Programmazione\ST MCU\baccable\canable\CANableAndLedsStripController\hardware\box\dual fysect ucan\Imported Components\UCAN_ V1.0\Open CASCADE STEP translator 7.5 54.ipt | Successful
[ ] | Open CASCADE STEP translator 7.5 55.ipt | E:\Dati\Documenti_Emanuele\Linguaggi_di_Programmazione\ST MCU\baccable\canable\CANableAndLedsStripController\hardware\box\dual fysect ucan\Imported Components\UCAN_ V1.0\Open CASCADE STEP translator 7.5 55.ipt | Successful
[ ] | Open CASCADE STEP translator 7.5 56.ipt | E:\Dati\Documenti_Emanuele\Linguaggi_di_Programmazione\ST MCU\baccable\canable\CANableAndLedsStripController\hardware\box\dual fysect ucan\Imported Components\UCAN_ V1.0\Open CASCADE STEP translator 7.5 56.ipt | Successful
[ ] | Open CASCADE STEP translator 7.5 57.ipt | E:\Dati\Documenti_Emanuele\Linguaggi_di_Programmazione\ST MCU\baccable\canable\CANableAndLedsStripController\hardware\box\dual fysect ucan\Imported Components\UCAN_ V1.0\Open CASCADE STEP translator 7.5 57.ipt | Successful
[ ] | Open CASCADE STEP translator 7.5 58.ipt | E:\Dati\Documenti_Emanuele\Linguaggi_di_Programmazione\ST MCU\baccable\canable\CANableAndLedsStripController\hardware\box\dual fysect ucan\Imported Components\UCAN_ V1.0\Open CASCADE STEP translator 7.5 58.ipt | Successful
[ ] | Open CASCADE STEP translator 7.5 59.ipt | E:\Dati\Documenti_Emanuele\Linguaggi_di_Programmazione\ST MCU\baccable\canable\CANableAndLedsStripController\hardware\box\dual fysect ucan\Imported Components\UCAN_ V1.0\Open CASCADE STEP translator 7.5 59.ipt | Successful
[ ] | Open CASCADE STEP translator 7.5 60.ipt | E:\Dati\Documenti_Emanuele\Linguaggi_di_Programmazione\ST MCU\baccable\canable\CANableAndLedsStripController\hardware\box\dual fysect ucan\Imported Components\UCAN_ V1.0\Open CASCADE STEP translator 7.5 60.ipt | Successful
[ ] | Open CASCADE STEP translator 7.5 61.ipt | E:\Dati\Documenti_Emanuele\Linguaggi_di_Programmazione\ST MCU\baccable\canable\CANableAndLedsStripController\hardware\box\dual fysect ucan\Imported Components\UCAN_ V1.0\Open CASCADE STEP translator 7.5 61.ipt | Successful
[ ] | Open CASCADE STEP translator 7.5 62.ipt | E:\Dati\Documenti_Emanuele\Linguaggi_di_Programmazione\ST MCU\baccable\canable\CANableAndLedsStripController\hardware\box\dual fysect ucan\Imported Components\UCAN_ V1.0\Open CASCADE STEP translator 7.5 62.ipt | Successful
[ ] | Open CASCADE STEP translator 7.5 63.ipt | E:\Dati\Documenti_Emanuele\Linguaggi_di_Programmazione\ST MCU\baccable\canable\CANableAndLedsStripController\hardware\box\dual fysect ucan\Imported Components\UCAN_ V1.0\Open CASCADE STEP translator 7.5 63.ipt | Successful
[ ] | Open CASCADE STEP translator 7.5 64.ipt | E:\Dati\Documenti_Emanuele\Linguaggi_di_Programmazione\ST MCU\baccable\canable\CANableAndLedsStripController\hardware\box\dual fysect ucan\Imported Components\UCAN_ V1.0\Open CASCADE STEP translator 7.5 64.ipt | Successful
[ ] | Open CASCADE STEP translator 7.5 65.ipt | E:\Dati\Documenti_Emanuele\Linguaggi_di_Programmazione\ST MCU\baccable\canable\CANableAndLedsStripController\hardware\box\dual fysect ucan\Imported Components\UCAN_ V1.0\Open CASCADE STEP translator 7.5 65.ipt | Successful
[ ] | Open CASCADE STEP translator 7.5 66.ipt | E:\Dati\Documenti_Emanuele\Linguaggi_di_Programmazione\ST MCU\baccable\canable\CANableAndLedsStripController\hardware\box\dual fysect ucan\Imported Components\UCAN_ V1.0\Open CASCADE STEP translator 7.5 66.ipt | Successful
[ ] | Open CASCADE STEP translator 7.5 67.ipt | E:\Dati\Documenti_Emanuele\Linguaggi_di_Programmazione\ST MCU\baccable\canable\CANableAndLedsStripController\hardware\box\dual fysect ucan\Imported Components\UCAN_ V1.0\Open CASCADE STEP translator 7.5 67.ipt | Successful
[ ] | Open CASCADE STEP translator 7.5 68.ipt | E:\Dati\Documenti_Emanuele\Linguaggi_di_Programmazione\ST MCU\baccable\canable\CANableAndLedsStripController\hardware\box\dual fysect ucan\Imported Components\UCAN_ V1.0\Open CASCADE STEP translator 7.5 68.ipt | Successful
[ ] | Open CASCADE STEP translator 7.5 69.ipt | E:\Dati\Documenti_Emanuele\Linguaggi_di_Programmazione\ST MCU\baccable\canable\CANableAndLedsStripController\hardware\box\dual fysect ucan\Imported Components\UCAN_ V1.0\Open CASCADE STEP translator 7.5 69.ipt | Successful
[ ] | Open CASCADE STEP translator 7.5 70.ipt | E:\Dati\Documenti_Emanuele\Linguaggi_di_Programmazione\ST MCU\baccable\canable\CANableAndLedsStripController\hardware\box\dual fysect ucan\Imported Components\UCAN_ V1.0\Open CASCADE STEP translator 7.5 70.ipt | Successful
[ ] | Open CASCADE STEP translator 7.5 71.ipt | E:\Dati\Documenti_Emanuele\Linguaggi_di_Programmazione\ST MCU\baccable\canable\CANableAndLedsStripController\hardware\box\dual fysect ucan\Imported Components\UCAN_ V1.0\Open CASCADE STEP translator 7.5 71.ipt | Successful
[ ] | Open CASCADE STEP translator 7.5 72.ipt | E:\Dati\Documenti_Emanuele\Linguaggi_di_Programmazione\ST MCU\baccable\canable\CANableAndLedsStripController\hardware\box\dual fysect ucan\Imported Components\UCAN_ V1.0\Open CASCADE STEP translator 7.5 72.ipt | Successful
[ ] | Open CASCADE STEP translator 7.5 73.ipt | E:\Dati\Documenti_Emanuele\Linguaggi_di_Programmazione\ST MCU\baccable\canable\CANableAndLedsStripController\hardware\box\dual fysect ucan\Imported Components\UCAN_ V1.0\Open CASCADE STEP translator 7.5 73.ipt | Successful
[ ] | Open CASCADE STEP translator 7.5 74.ipt | E:\Dati\Documenti_Emanuele\Linguaggi_di_Programmazione\ST MCU\baccable\canable\CANableAndLedsStripController\hardware\box\dual fysect ucan\Imported Components\UCAN_ V1.0\Open CASCADE STEP translator 7.5 74.ipt | Successful
[ ] | Open CASCADE STEP translator 7.5 75.ipt | E:\Dati\Documenti_Emanuele\Linguaggi_di_Programmazione\ST MCU\baccable\canable\CANableAndLedsStripController\hardware\box\dual fysect ucan\Imported Components\UCAN_ V1.0\Open CASCADE STEP translator 7.5 75.ipt | Successful
[ ] | Open CASCADE STEP translator 7.5 76.ipt | E:\Dati\Documenti_Emanuele\Linguaggi_di_Programmazione\ST MCU\baccable\canable\CANableAndLedsStripController\hardware\box\dual fysect ucan\Imported Components\UCAN_ V1.0\Open CASCADE STEP translator 7.5 76.ipt | Successful
[ ] | Open CASCADE STEP translator 7.5 77.ipt | E:\Dati\Documenti_Emanuele\Linguaggi_di_Programmazione\ST MCU\baccable\canable\CANableAndLedsStripController\hardware\box\dual fysect ucan\Imported Components\UCAN_ V1.0\Open CASCADE STEP translator 7.5 77.ipt | Successful
[ ] | Open CASCADE STEP translator 7.5 78.ipt | E:\Dati\Documenti_Emanuele\Linguaggi_di_Programmazione\ST MCU\baccable\canable\CANableAndLedsStripController\hardware\box\dual fysect ucan\Imported Components\UCAN_ V1.0\Open CASCADE STEP translator 7.5 78.ipt | Successful
[ ] | Open CASCADE STEP translator 7.5 79.ipt | E:\Dati\Documenti_Emanuele\Linguaggi_di_Programmazione\ST MCU\baccable\canable\CANableAndLedsStripController\hardware\box\dual fysect ucan\Imported Components\UCAN_ V1.0\Open CASCADE STEP translator 7.5 79.ipt | Successful
[ ] | Open CASCADE STEP translator 7.5 80.ipt | E:\Dati\Documenti_Emanuele\Linguaggi_di_Programmazione\ST MCU\baccable\canable\CANableAndLedsStripController\hardware\box\dual fysect ucan\Imported Components\UCAN_ V1.0\Open CASCADE STEP translator 7.5 80.ipt | Successful
[ ] | Open CASCADE STEP translator 7.5 81.ipt | E:\Dati\Documenti_Emanuele\Linguaggi_di_Programmazione\ST MCU\baccable\canable\CANableAndLedsStripController\hardware\box\dual fysect ucan\Imported Components\UCAN_ V1.0\Open CASCADE STEP translator 7.5 81.ipt | Successful
[ ] | Open CASCADE STEP translator 7.5 82.ipt | E:\Dati\Documenti_Emanuele\Linguaggi_di_Programmazione\ST MCU\baccable\canable\CANableAndLedsStripController\hardware\box\dual fysect ucan\Imported Components\UCAN_ V1.0\Open CASCADE STEP translator 7.5 82.ipt | Successful
[ ] | Open CASCADE STEP translator 7.5 83.ipt | E:\Dati\Documenti_Emanuele\Linguaggi_di_Programmazione\ST MCU\baccable\canable\CANableAndLedsStripController\hardware\box\dual fysect ucan\Imported Components\UCAN_ V1.0\Open CASCADE STEP translator 7.5 83.ipt | Successful
[ ] | Open CASCADE STEP translator 7.5 84.ipt | E:\Dati\Documenti_Emanuele\Linguaggi_di_Programmazione\ST MCU\baccable\canable\CANableAndLedsStripController\hardware\box\dual fysect ucan\Imported Components\UCAN_ V1.0\Open CASCADE STEP translator 7.5 84.ipt | Successful
[ ] | Open CASCADE STEP translator 7.5 85.ipt | E:\Dati\Documenti_Emanuele\Linguaggi_di_Programmazione\ST MCU\baccable\canable\CANableAndLedsStripController\hardware\box\dual fysect ucan\Imported Components\UCAN_ V1.0\Open CASCADE STEP translator 7.5 85.ipt | Successful
[ ] | Open CASCADE STEP translator 7.5 86.ipt | E:\Dati\Documenti_Emanuele\Linguaggi_di_Programmazione\ST MCU\baccable\canable\CANableAndLedsStripController\hardware\box\dual fysect ucan\Imported Components\UCAN_ V1.0\Open CASCADE STEP translator 7.5 86.ipt | Successful
[ ] | Open CASCADE STEP translator 7.5 87.ipt | E:\Dati\Documenti_Emanuele\Linguaggi_di_Programmazione\ST MCU\baccable\canable\CANableAndLedsStripController\hardware\box\dual fysect ucan\Imported Components\UCAN_ V1.0\Open CASCADE STEP translator 7.5 87.ipt | Successful
[ ] | Open CASCADE STEP translator 7.5 88.ipt | E:\Dati\Documenti_Emanuele\Linguaggi_di_Programmazione\ST MCU\baccable\canable\CANableAndLedsStripController\hardware\box\dual fysect ucan\Imported Components\UCAN_ V1.0\Open CASCADE STEP translator 7.5 88.ipt | Successful
[ ] | Open CASCADE STEP translator 7.5 89.ipt | E:\Dati\Documenti_Emanuele\Linguaggi_di_Programmazione\ST MCU\baccable\canable\CANableAndLedsStripController\hardware\box\dual fysect ucan\Imported Components\UCAN_ V1.0\Open CASCADE STEP translator 7.5 89.ipt | Successful
[ ] | Open CASCADE STEP translator 7.5 90.ipt | E:\Dati\Documenti_Emanuele\Linguaggi_di_Programmazione\ST MCU\baccable\canable\CANableAndLedsStripController\hardware\box\dual fysect ucan\Imported Components\UCAN_ V1.0\Open CASCADE STEP translator 7.5 90.ipt | Successful
[ ] | Open CASCADE STEP translator 7.5 91.ipt | E:\Dati\Documenti_Emanuele\Linguaggi_di_Programmazione\ST MCU\baccable\canable\CANableAndLedsStripController\hardware\box\dual fysect ucan\Imported Components\UCAN_ V1.0\Open CASCADE STEP translator 7.5 91.ipt | Successful
[ ] | Open CASCADE STEP translator 7.5 92.ipt | E:\Dati\Documenti_Emanuele\Linguaggi_di_Programmazione\ST MCU\baccable\canable\CANableAndLedsStripController\hardware\box\dual fysect ucan\Imported Components\UCAN_ V1.0\Open CASCADE STEP translator 7.5 92.ipt | Successful
[ ] | Open CASCADE STEP translator 7.5 93.ipt | E:\Dati\Documenti_Emanuele\Linguaggi_di_Programmazione\ST MCU\baccable\canable\CANableAndLedsStripController\hardware\box\dual fysect ucan\Imported Components\UCAN_ V1.0\Open CASCADE STEP translator 7.5 93.ipt | Successful
[ ] | Open CASCADE STEP translator 7.5 94.ipt | E:\Dati\Documenti_Emanuele\Linguaggi_di_Programmazione\ST MCU\baccable\canable\CANableAndLedsStripController\hardware\box\dual fysect ucan\Imported Components\UCAN_ V1.0\Open CASCADE STEP translator 7.5 94.ipt | Successful
[ ] | Open CASCADE STEP translator 7.5 95.ipt | E:\Dati\Documenti_Emanuele\Linguaggi_di_Programmazione\ST MCU\baccable\canable\CANableAndLedsStripController\hardware\box\dual fysect ucan\Imported Components\UCAN_ V1.0\Open CASCADE STEP translator 7.5 95.ipt | Successful
[ ] | Open CASCADE STEP translator 7.5 96.ipt | E:\Dati\Documenti_Emanuele\Linguaggi_di_Programmazione\ST MCU\baccable\canable\CANableAndLedsStripController\hardware\box\dual fysect ucan\Imported Components\UCAN_ V1.0\Open CASCADE STEP translator 7.5 96.ipt | Successful
[+] [-] | Open CASCADE STEP translator 7.5 97.ipt | E:\Dati\Documenti_Emanuele\Linguaggi_di_Programmazione\ST MCU\baccable\canable\CANableAndLedsStripController\hardware\box\dual fysect ucan\Imported Components\UCAN_ V1.0\Open CASCADE STEP translator 7.5 97.ipt | Warning
Severity | Entity Id | Message
Warning | 49430 | Some Surfaces have been simplified
[ ] | Open CASCADE STEP translator 7.5 98.ipt | E:\Dati\Documenti_Emanuele\Linguaggi_di_Programmazione\ST MCU\baccable\canable\CANableAndLedsStripController\hardware\box\dual fysect ucan\Imported Components\UCAN_ V1.0\Open CASCADE STEP translator 7.5 98.ipt | Successful
[ ] | Open CASCADE STEP translator 7.5 99.ipt | E:\Dati\Documenti_Emanuele\Linguaggi_di_Programmazione\ST MCU\baccable\canable\CANableAndLedsStripController\hardware\box\dual fysect ucan\Imported Components\UCAN_ V1.0\Open CASCADE STEP translator 7.5 99.ipt | Successful
[ ] | Open CASCADE STEP translator 7.5 100.ipt | E:\Dati\Documenti_Emanuele\Linguaggi_di_Programmazione\ST MCU\baccable\canable\CANableAndLedsStripController\hardware\box\dual fysect ucan\Imported Components\UCAN_ V1.0\Open CASCADE STEP translator 7.5 100.ipt | Successful
[ ] | Open CASCADE STEP translator 7.5 101.ipt | E:\Dati\Documenti_Emanuele\Linguaggi_di_Programmazione\ST MCU\baccable\canable\CANableAndLedsStripController\hardware\box\dual fysect ucan\Imported Components\UCAN_ V1.0\Open CASCADE STEP translator 7.5 101.ipt | Successful
[ ] | Open CASCADE STEP translator 7.5 102.ipt | E:\Dati\Documenti_Emanuele\Linguaggi_di_Programmazione\ST MCU\baccable\canable\CANableAndLedsStripController\hardware\box\dual fysect ucan\Imported Components\UCAN_ V1.0\Open CASCADE STEP translator 7.5 102.ipt | Successful
[ ] | Open CASCADE STEP translator 7.5 103.ipt | E:\Dati\Documenti_Emanuele\Linguaggi_di_Programmazione\ST MCU\baccable\canable\CANableAndLedsStripController\hardware\box\dual fysect ucan\Imported Components\UCAN_ V1.0\Open CASCADE STEP translator 7.5 103.ipt | Successful
[ ] | Open CASCADE STEP translator 7.5 104.ipt | E:\Dati\Documenti_Emanuele\Linguaggi_di_Programmazione\ST MCU\baccable\canable\CANableAndLedsStripController\hardware\box\dual fysect ucan\Imported Components\UCAN_ V1.0\Open CASCADE STEP translator 7.5 104.ipt | Successful
[ ] | Open CASCADE STEP translator 7.5 105.ipt | E:\Dati\Documenti_Emanuele\Linguaggi_di_Programmazione\ST MCU\baccable\canable\CANableAndLedsStripController\hardware\box\dual fysect ucan\Imported Components\UCAN_ V1.0\Open CASCADE STEP translator 7.5 105.ipt | Successful
[ ] | Open CASCADE STEP translator 7.5 106.ipt | E:\Dati\Documenti_Emanuele\Linguaggi_di_Programmazione\ST MCU\baccable\canable\CANableAndLedsStripController\hardware\box\dual fysect ucan\Imported Components\UCAN_ V1.0\Open CASCADE STEP translator 7.5 106.ipt | Successful
[ ] | Open CASCADE STEP translator 7.5 107.ipt | E:\Dati\Documenti_Emanuele\Linguaggi_di_Programmazione\ST MCU\baccable\canable\CANableAndLedsStripController\hardware\box\dual fysect ucan\Imported Components\UCAN_ V1.0\Open CASCADE STEP translator 7.5 107.ipt | Successful
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

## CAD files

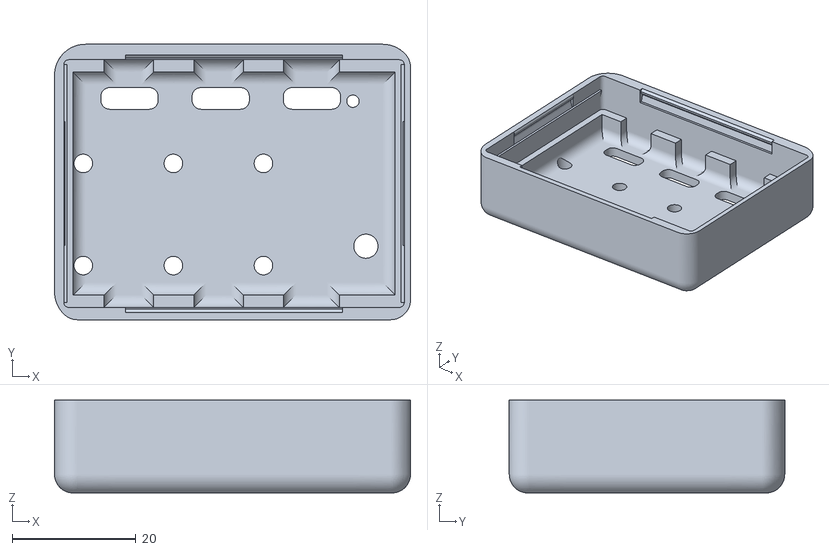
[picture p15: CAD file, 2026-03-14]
hardware/box/baccable_lastest_case_for_new_PCB/cover_withoutBaccableText.stl
57.5 x 44.5 x 15.0

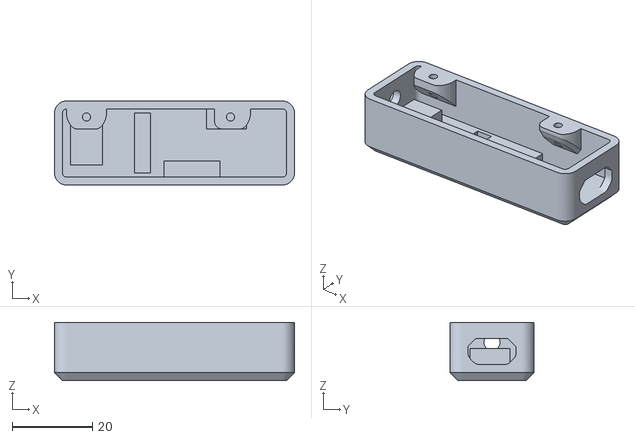
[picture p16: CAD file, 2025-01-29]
hardware/box/canableDykbRadioNanoOnly/canableDykbRadiooNanoBoxOnly3.stl
60.0 x 21.0 x 14.5

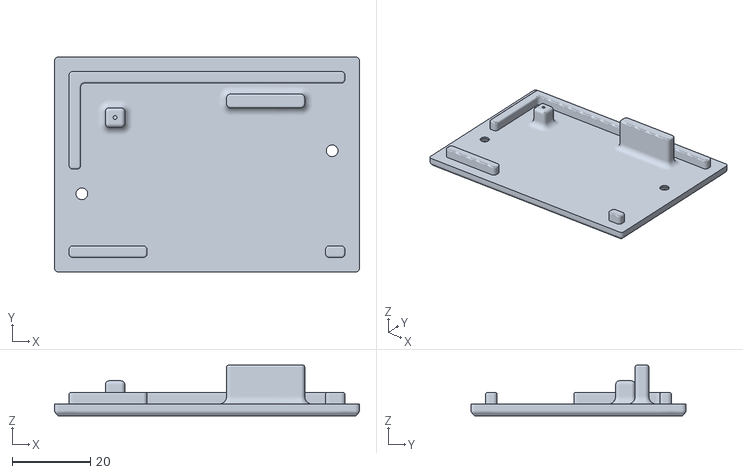
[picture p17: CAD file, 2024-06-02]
hardware/box/canableWithDcDcAndTB/cap.stl
78.0 x 55.0 x 13.0

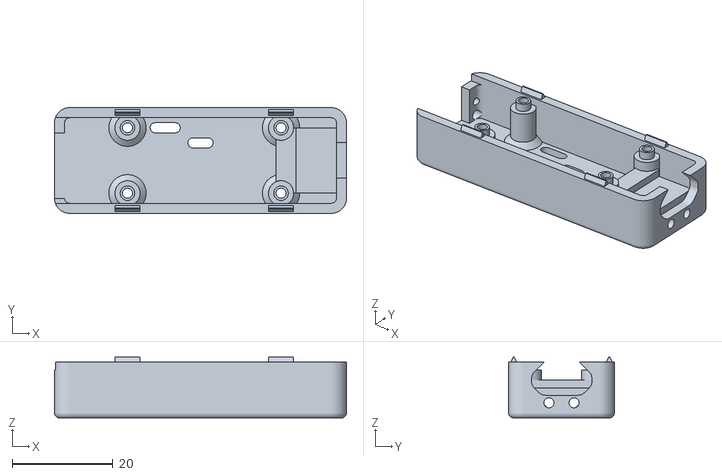
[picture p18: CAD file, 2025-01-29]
hardware/box/dual_fysect_ucan/dualBaccable-ucan_fysect.stl
58.0 x 21.0 x 12.1

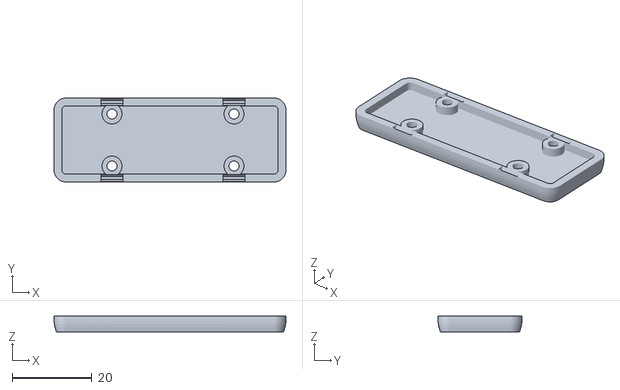
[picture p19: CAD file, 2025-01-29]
hardware/box/single_fysect_ucan/singleBaccable-ucan_fysect_CAP.stl
58.0 x 21.0 x 4.00

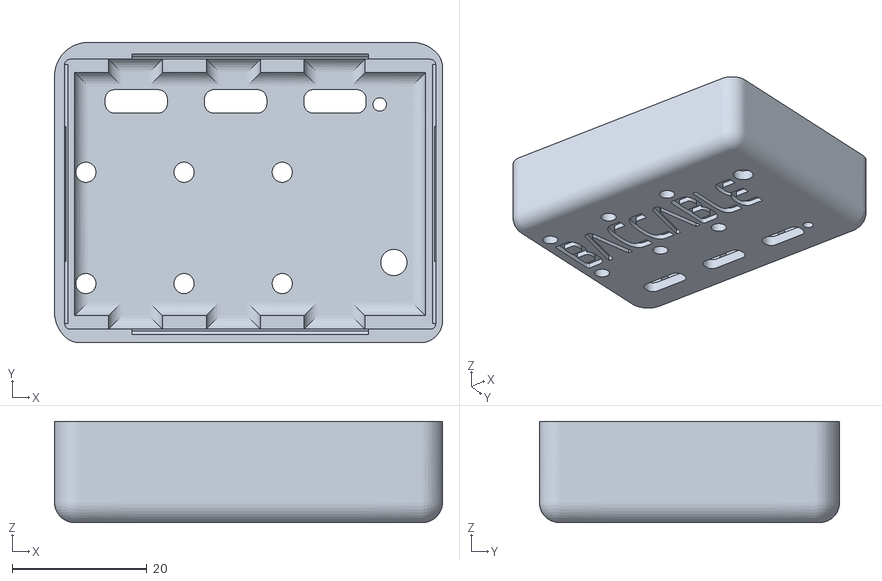
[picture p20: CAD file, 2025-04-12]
hardware/box/baccable_lastest_case_for_new_PCB/cover.stl
57.5 x 44.5 x 15.0

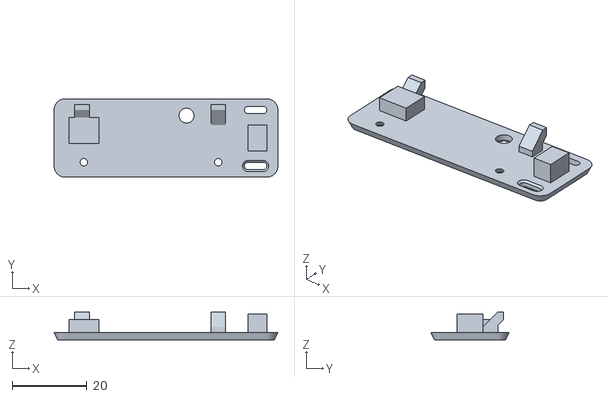
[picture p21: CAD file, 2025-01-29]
hardware/box/canableDykbRadioNanoOnly/canableDykbRadiooNanoCap3.stl
60.0 x 21.0 x 7.50

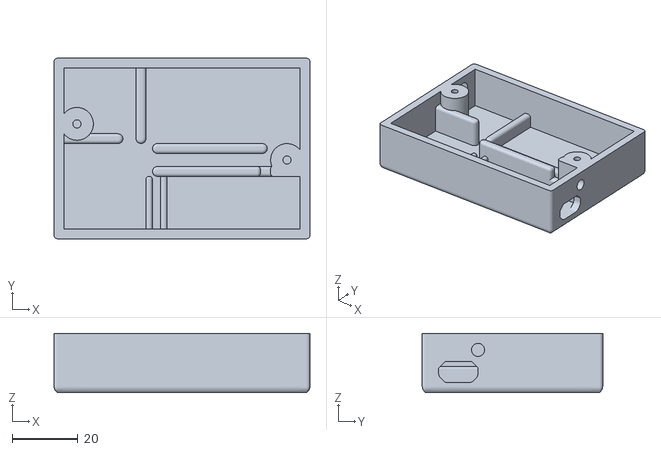
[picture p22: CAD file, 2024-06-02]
hardware/box/canableWithDcDcAndTB/box.stl
78.0 x 55.0 x 18.0

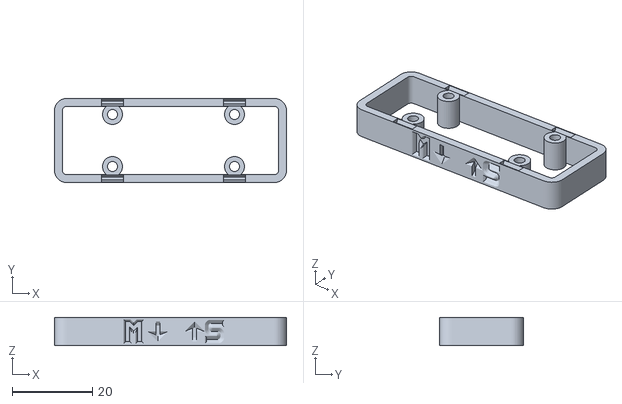
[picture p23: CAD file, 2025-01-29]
hardware/box/dual_fysect_ucan/dualBaccable-ucan_fysect_middle.stl
58.0 x 21.0 x 7.00

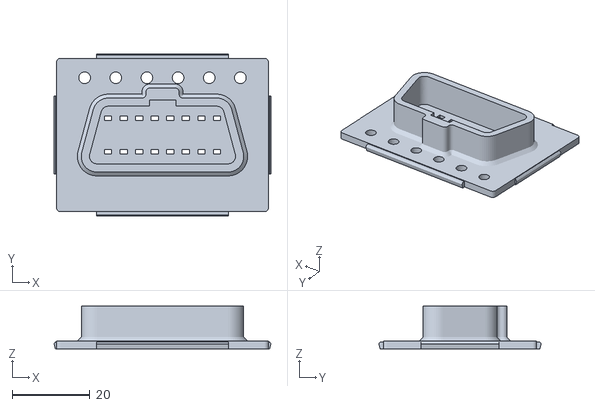
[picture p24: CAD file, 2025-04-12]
hardware/box/baccable_lastest_case_for_new_PCB/obdBase.stl
55.7 x 41.7 x 11.0

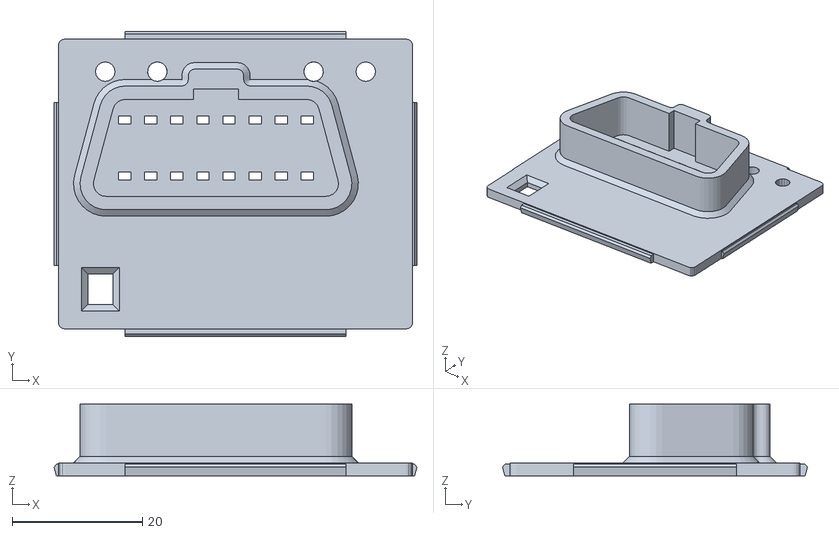
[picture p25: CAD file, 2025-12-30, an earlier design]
hardware/box/baccable_lastest_case_for_new_PCB_V2/obdBase.stl
55.7 x 46.8 x 11.0

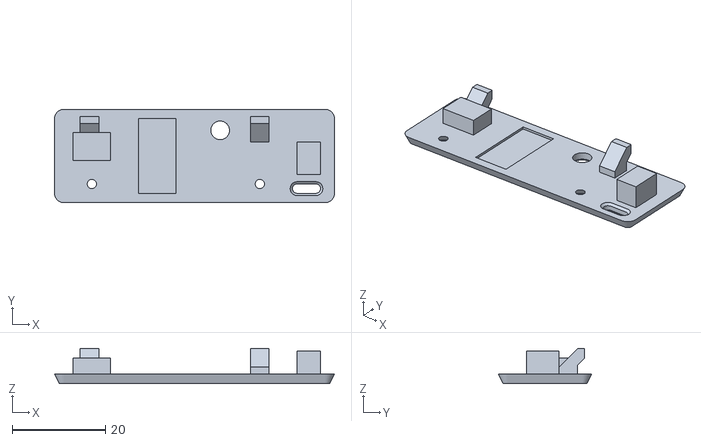
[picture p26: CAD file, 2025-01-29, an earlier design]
hardware/box/canableDykbRadioNanoOnly/old/canableDykbRadiooNanoCap2.stl
60.0 x 20.0 x 7.50

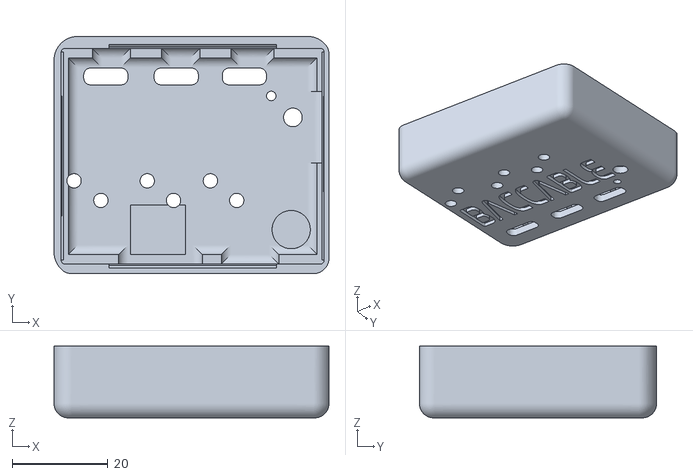
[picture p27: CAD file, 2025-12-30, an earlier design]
hardware/box/baccable_lastest_case_for_new_PCB_V2/cover.stl
57.5 x 49.6 x 15.0

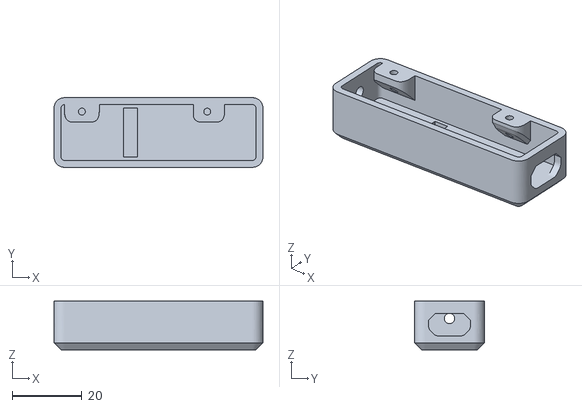
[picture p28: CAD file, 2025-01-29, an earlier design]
hardware/box/canableDykbRadioNanoOnly/old/old canableDykbRadiooNanoBoxOnly2.stl
60.0 x 20.0 x 14.0

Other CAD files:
hardware/system_interconnection/SCHEMA_DI_INTERCONNESSIONE.dwg
hardware/box/canableDykbRadioNanoOnly/old/canableDykbRadiooNanoBoxOnly3.stl
hardware/box/canableDykbRadioNanoOnly/old/canableDykbRadiooNanoCap3.stl
hardware/box/canableDykbRadioNanoOnly/old/old canableDykbRadiooNanoCap2.stl
hardware/box/baccable_lastest_case_for_new_PCB/FullCaseWithBaccable.iam
hardware/box/baccable_lastest_case_for_new_PCB/OldVersions/FullCaseWithBaccable.0015.iam
hardware/box/baccable_lastest_case_for_new_PCB/OldVersions/cover.0030.ipt
hardware/box/baccable_lastest_case_for_new_PCB/OldVersions/obdBase.0021.ipt
hardware/box/baccable_lastest_case_for_new_PCB/cover.ipt
hardware/box/baccable_lastest_case_for_new_PCB/cover_withoutBaccableText.ipt
hardware/box/baccable_lastest_case_for_new_PCB/obdBase.ipt
hardware/box/baccable_lastest_case_for_new_PCB_V2/0510210200.stp
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

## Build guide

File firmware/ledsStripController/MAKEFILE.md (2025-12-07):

# BACCAble Makefile

Base makefile to build and flash without STM32 IDE so you can use your favorite IDE

## Building

Firmware builds with GCC. Specifically, you will need gcc-arm-none-eabi, which
is packaged for Windows, OS X, and Linux on
[Launchpad](https://launchpad.net/gcc-arm-embedded/+download). Download for your
system and add the `bin` folder to your PATH.

Your Linux distribution may also have a prebuilt package for `arm-none-eabi-gcc`, check your distro's repositories to see if a build exists.

Just you can compile using `make`. If succesfull you'll get a summary of the build.

## Building default flavors

For BH bus
```
$ CFLAGS="-DRELEASE_FLAVOR=BH_FLAVOR -DBH_FLAVOR=1" make clean all
```

For C1 bus
```
$ CFLAGS="-DRELEASE_FLAVOR=C1_FLAVOR -DC1_FLAVOR=1" make clean all
```

For C2 bus
```
$ CFLAGS="-DRELEASE_FLAVOR=C2_FLAVOR -DC2_FLAVOR=1" make clean all
```

```
$ CFLAGS="-DRELEASE_FLAVOR=CAN_FLAVOR -DCAN_FLAVOR=1" make clean all
```

## Flashing with the Bootloader

Simply plug in your CANable with the BOOT jumper enabled (or depress the boot button on the CANable Pro while plugging in). Next, type `make flash` and your CANable will be updated to the latest firwmare. Unplug/replug the device after moving the boot jumper back, and your CANable will be up and running.

Please note that the flashed binary will be `./build/baccable-$(GIT_VERSION).bin`

## Contributors

- [Ethan Zonca](https://github.com/normaldotcom) - This makefile is just an adaption of the one crafted by Ethan for his SLCAN firmware (https://github.com/normaldotcom/canable-fw)

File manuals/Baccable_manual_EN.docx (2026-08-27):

OBD BACCABLE

MANUAL

DISCLAIMER: BACCABLE is a project developed exclusively for educational and research purposes. The use of this tool on vehicles operating on public roads or in any context that may cause harm to people, property, or violate applicable regulations is strictly prohibited.

The author of this project assumes no responsibility for any damages, malfunctions, or consequences resulting from the use of BACCABLE. The end user bears full civil, criminal, and legal responsibility for its use.

It is strongly recommended not to use this project in real-world vehicle applications.

The installation in hidden location, requires specific technical skills in automotive electrical and electronic systems to avoid errors that could expose to safety risks.

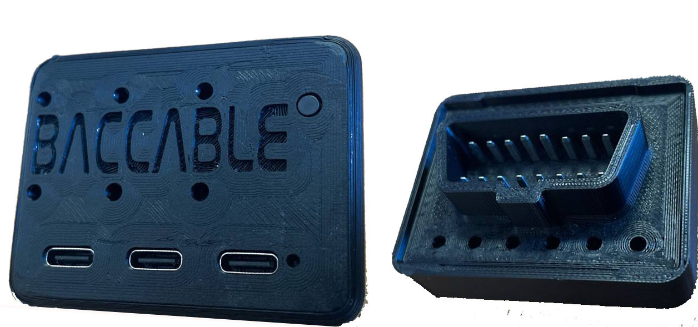
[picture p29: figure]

INDEX

# 1. INSTALL

## 1.1 Composition

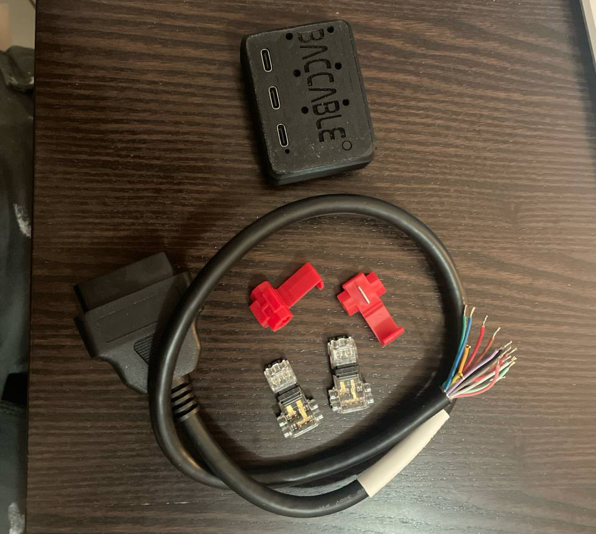
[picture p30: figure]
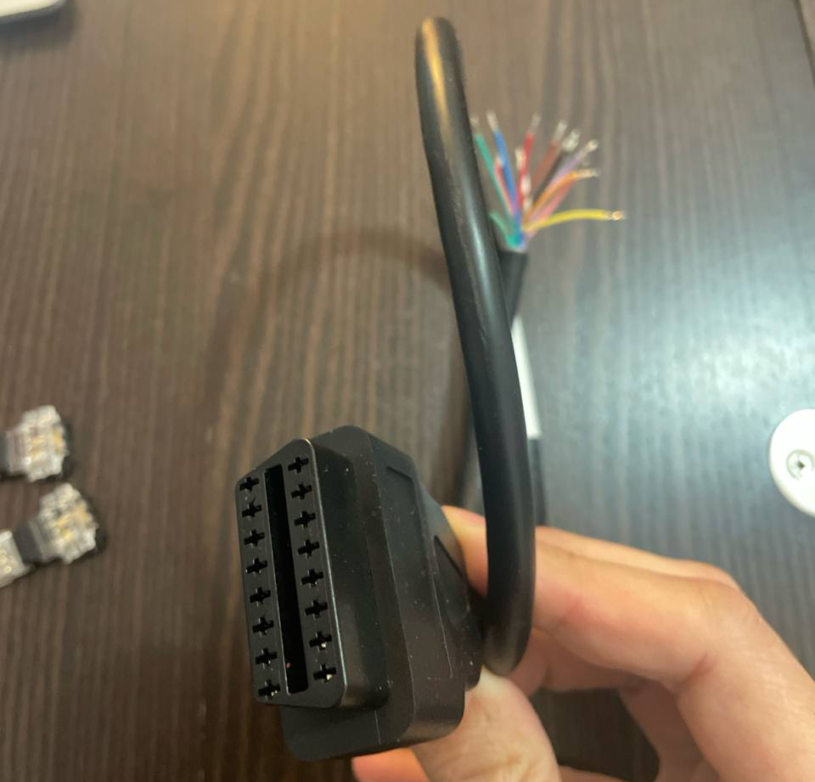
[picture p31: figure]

Composition

The cable and the "wire taps" (quick connectors or IDC) shown in the previous photo are optionals. The Baccable can be used by connecting it directly to the OBD if the vehicle is not equipped with an SGW or if it has an SGW bypass (SGW = Secure Gateway). Therefore, using the included cable and quick connectors is not mandatory.

## 1.2 Pinout

The Baccable OBD V.3 is equipped with an OBD connector with the following pinout:

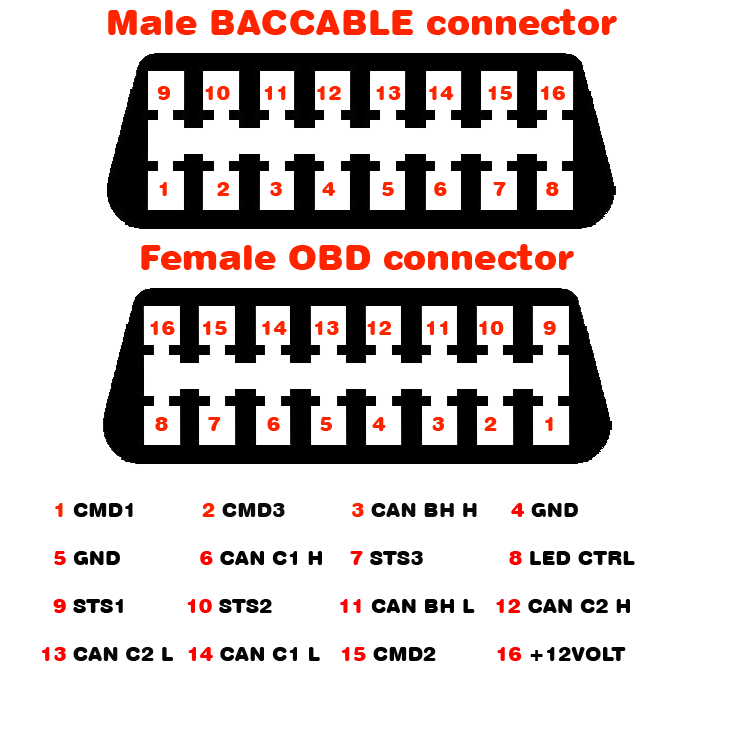
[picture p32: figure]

BACCABLE Pinout and OBD cable pinout

Pin 16 corresponds to the 12V power supply of the vehicle's OBD port but can also be connected to a 5V supply if needed, as the BACCABLE supports a wide range of input voltages.

## 1.3 Install instructions (to OBD port)

1) When inserting the BACCABLE into the vehicle's OBD port, be careful not to press the PROGRAMMING button. If this happens, remove the BACCABLE and reinsert it.

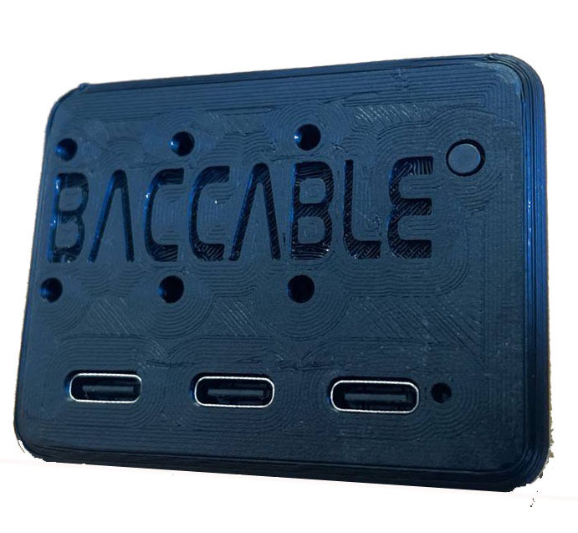
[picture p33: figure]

PROGRAMMING

PROGRAMMING button

2) When removing the BACCABLE from the vehicle's OBD port, do not pull on the casing. Instead, push by inserting your fingertips on the OBD connector side towards yourself to avoid stressing the latch that holds together the case (the part with the "BACCABLE" label) and the part where the OBD connector is located.

If the joint is accidentally disengaged, proceed by completely removing the parts (PCB and case) from the OBD connector. Then, reinsert the PCB (printed circuit board) into the case with the "BACCABLE" label, aligning the parts as shown in the previous image. Next, insert the side with the OBD connector until it touches the case.

WARNING: The OBD connector must have the two longer pins aligned with the long side. If inserted incorrectly, remove the OBD connector side, rotate it, and reinsert it.

Once the OBD connector side is in contact with the case, hold the BACCABLE firmly and press firmly on all four corners, ensuring that the cover gradually snaps into place from all sides until fully secured.

## 1.4 OBD Cable install instructions (optional)

1) In addition to the cable, IDCs (also known as "current taps") are provided. These are quick connectors that allow you to tap the desired signal without interrupting the vehicle's wiring. The dual quick connectors are designed for the H and L pins, while the single ones can be used for power supply or H and L pins.
2) The quick connector is capable of crimping a wide range of wire sizes; however, this versatility makes the dual quick connector more complex to use. To secure the wires of the double quick connector on the CAN bus, it is not enough to insert the wires into the slot and close the cover. First, it is necessary, using a small flat-head screwdriver, to push the wire into the guillotine to make it penetrate properly. If this preliminary operation is performed correctly, closing the connector cover firmly should engage the locking clips, ensuring the connector is tightly closed with no gaps between the transparent cover and the black base. The red single quick connector, on the other hand, can be tightened with pliers, so it does not require any preliminary steps. Always check the solidity of the connection after tightening.

The following image shows pins on the OBD diagnostic connector (the connector in the image is viewed from the external pin side, not the wire side). Pins 4 and 5 are the ground (GND), and pin 16 is the 12 Volt.

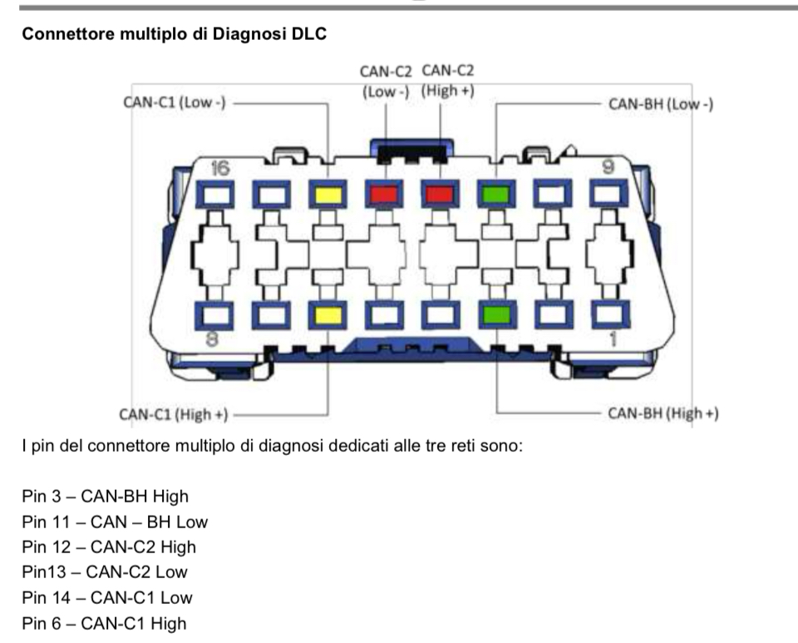
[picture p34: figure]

## 1.5 First Startup (with additional wiring)

During the first startup, perform the following preliminary checks:

1. Verify that all connections have been made according to the diagram and the requirements defined in this document.
2. With the ignition on, check that the green LED inside the BACCABLE enclosure is illuminated, confirming correct power supply reception.
3. If the dashboard does not turn on or random errors appear, check that the H and L pins have not been reversed or that neither has been mistakenly connected to another wire.
4. Check that the internal blue LED flashes twice at startup, indicating correct activation of the default-enabled Immobilizer function (note: without perfect alignment between the eye and the LED, it may not be visible—multiple startups may be needed for this check).
5. As soon as the BACCABLE is inserted, if the vehicle dashboard is already on, the instrument cluster should flash once to indicate that the immobilizer is active (enabled by default). If this does not happen, check the connections to the CAN bus.

## 1.6 First Startup (insertion into standard OBD port)

At first use, you must define which functions you wish to use on your vehicle by accessing the SETUP menu.

Instructions for accessing the SETUP menu, scrolling through the list of available functions, enabling/disabling features, and permanently saving the settings are provided in paragraph 2.1.

## 1.7 Notes on Connections to 5V (optional)

If the BACCABLE is powered by the 5V supply, you can connect to, for example, the USB HUB located in the glove compartment of the center console, next to the handbrake. This voltage is active as soon as you enter the vehicle, but also when connecting to the RF HUB as a thief. To access this voltage, follow these instructions:

1. Remove and disconnect the USB HUB from the vehicle.
2. Widen the 4 tabs on the back cover using small screwdrivers and tweezers, then remove the printed circuit board.
3. Drill a hole in the back plastic in the area not occupied by connectors to allow the wire, as shown in the figure, to pass through (make sure to drill a precise hole to prevent the wire from sliding too loosely; if needed, apply a drop of silicone inside at the end to provide resistance in case the wire is pulled).
4. Solder the wire to the USB HUB printed circuit board, at the +5V pin of the USB connector. You can use the reference images below to identify the correct pin to use.

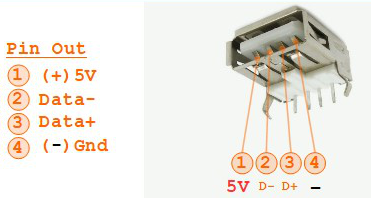
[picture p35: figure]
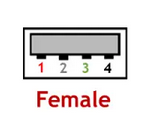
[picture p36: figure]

## 1.8 Notes about connections toward can bus

If the vehicle is equipped with an SGW (Secure Gateway), the pins on the OBD port cannot be used to connect the BACCABLE. Instead, it will be necessary to use an SGW bypass wiring that can be purchased online, which will provide an OBD port for the BACCABLE connection. Alternatively, you can intercept the wires of the desired CAN bus at other points in the vehicle, upstream of the SGW.

## 1.9 Connection Examples

Example 1 of a point upstream of the SGW where the C1 bus can be detected:

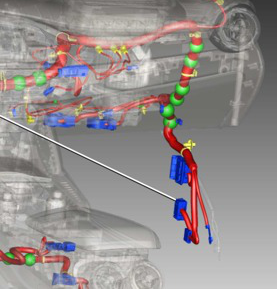
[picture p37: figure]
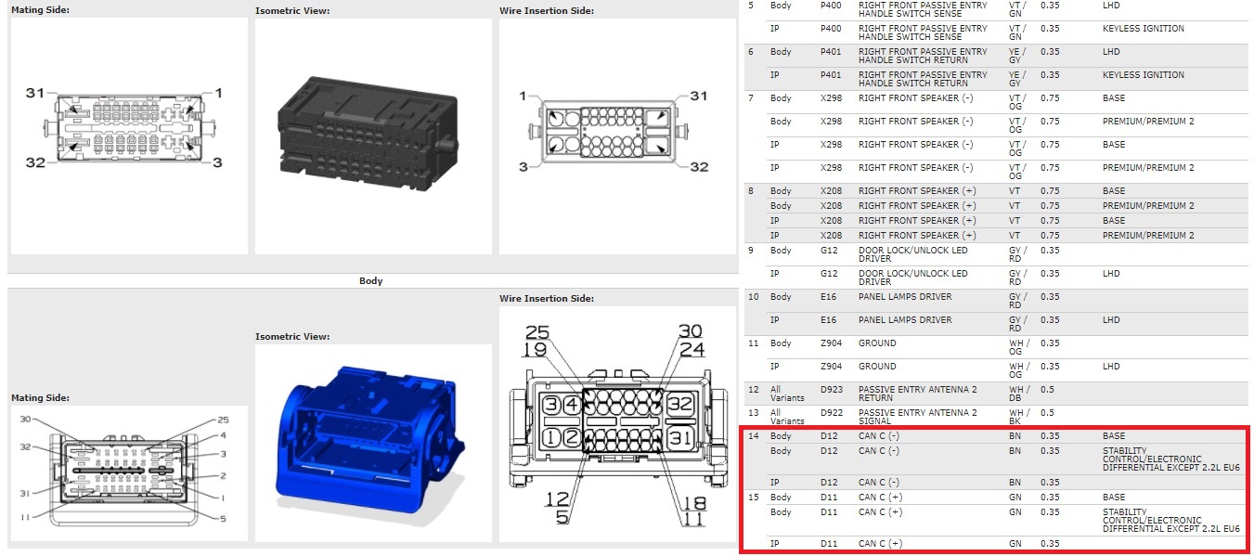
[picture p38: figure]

Example 2 of a point upstream of the SGW where the C1 bus can be detected:

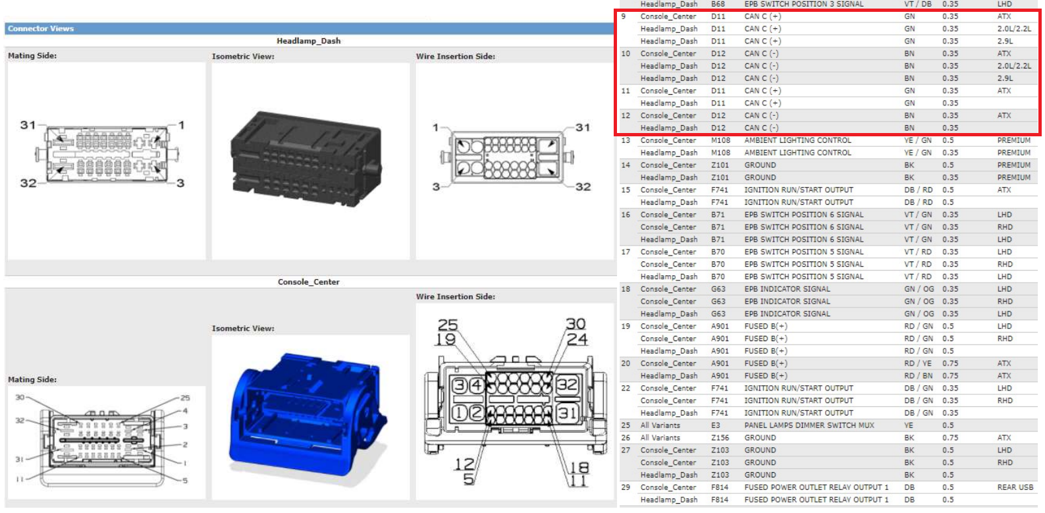
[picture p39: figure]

Example 3 of a point upstream of the SGW:

In the case of an automatic transmission, the following excerpt from the manual can be used, along with the pinout of the transmission connector:

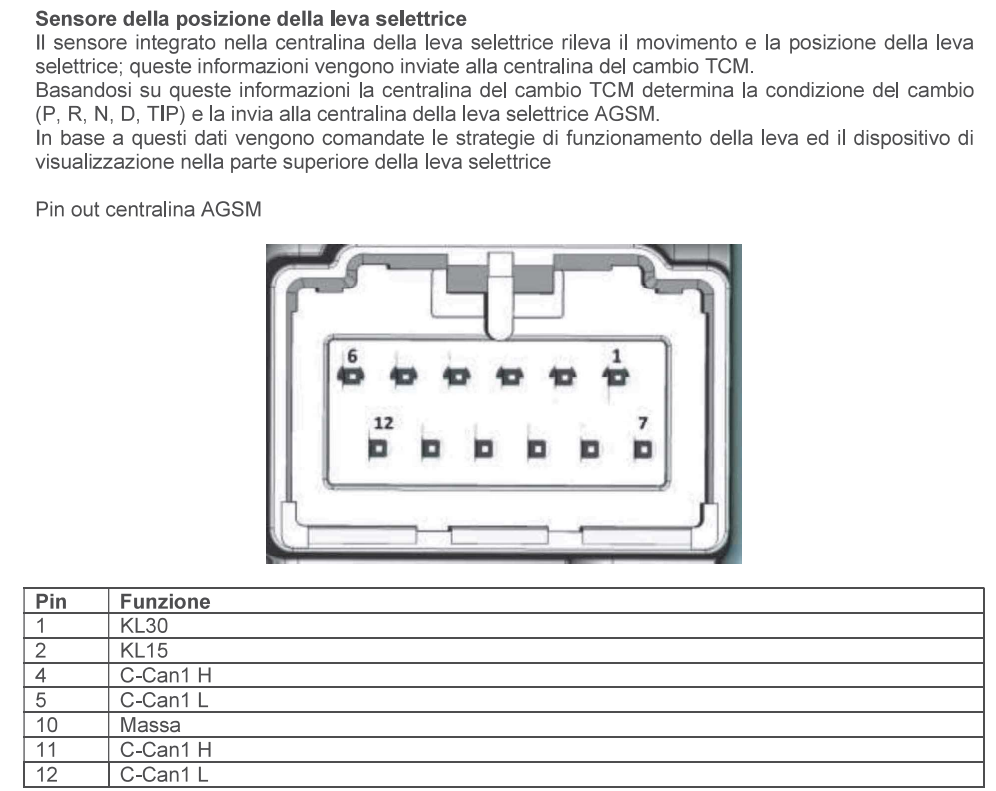
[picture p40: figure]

Example 4 of a point upstream of the SGW:

On the Body, located at the passenger footwell, there are all the bus lines and the power supply.

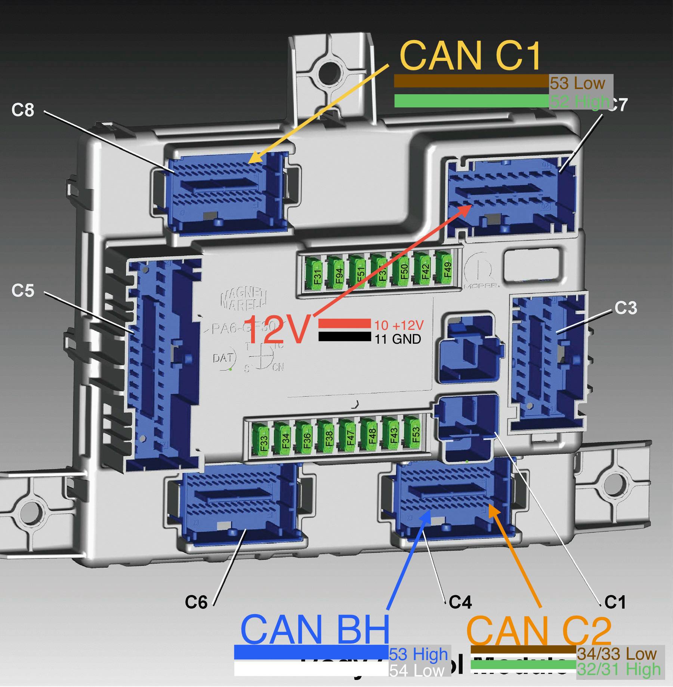
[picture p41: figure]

Can Bus and power supply on the Body Computer

The following image shows the Body Connectors Layout:

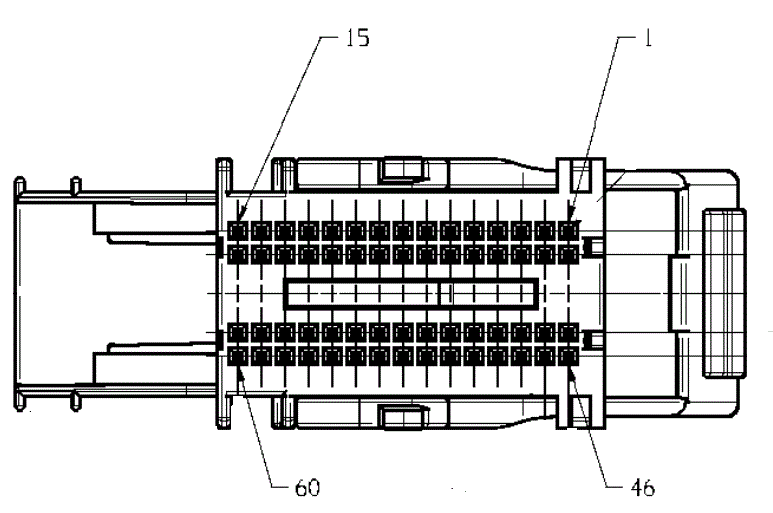
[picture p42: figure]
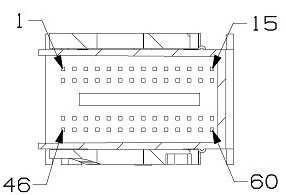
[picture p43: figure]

Body C4 connector Body C8 connector

## 1.10 TECHNICAL CHARACTERISTICS

Dimensions: 57.5mm (width) x 44.5mm (height) x 22mm (depth)

Weight: less than 50 grams

Power supply voltage: 4.5V - 35V (DC)

Current consumption @12V: approximately 11mA with vehicle off in sleep mode. Less than 30mA during operation with vehicle on.

## 1.11 FIRMWARE UPGRADE

The BACCABLE is delivered pre-programmed with the latest available firmware release; however, it is possible to benefit from future firmware updates via the Firmware Update procedure.

To get started, visit the BACCAble GitHub releases page, from a PC or from an Android smartphone: https://github.com/gaucho1978/BACCAble/releases/ and download the latest STABLE version available for the BACCABLE.

Programming Button

USB Bus C1 Connector

USB Bus C2 Connector

USB Bus BH Connector

Programming connectors and button, used during programming phase

The files to use are:

- baccableBH_stable.elf (to upload connected to USB BH connector)
- baccableC1diesel_stable.elf (to upload connected to USB C1 connector)
- baccableC2_stable.elf (to upload connected to USB C2 connector)

Perform the firmware loading procedure on all three USB connectors by uploading the corresponding firmware to each USB port as follows:

- baccableC1diesel_stable.elf to USB C1

- baccableC2_stable.elf to USB C2

- baccableBH_stable.elf to USB BH

Two procedures are described below: one for uploading the firmware via a Windows PC, and the other for uploading the firmware via an Android smartphone.

## 1.11.1 Procedure for firmware programming trough PC

To carry out this procedure you will need:

- a PC running Microsoft Windows with a USB port
- the STM Cube Programmer software for Windows PC, which can be downloaded from the ST website after free registration, using the following link: https://www.st.com/en/development-tools/stm32cubeprog.html
- a USB cable to connect the PC to the BACCABLE
1) Press and hold the programming button on the board
2) Connect the USB port (C1, C2, BH) to the PC - The board will be recognized by the PC as a serial device named "STM32 Bootloader"
3) Only when the green LED is lit, the programming button can be released

Note1: If the green LED on the BACCABLE flickers or emits a weak light, use a shorter USB cable, or replace the USB cable

Note2: If the board is not detected by the PC, make sure the programming button was pressed correctly before connecting the USB cable, and keep it pressed until the USB connector is fully inserted on both sides. If the problem persists, rotate the USB-C connector on the BACCABLE side by 180 degrees and try again

4) Open the STM32CubeProgrammer software, select USB from the dropdown menu (on the right side of the window), then press the CONNECT button

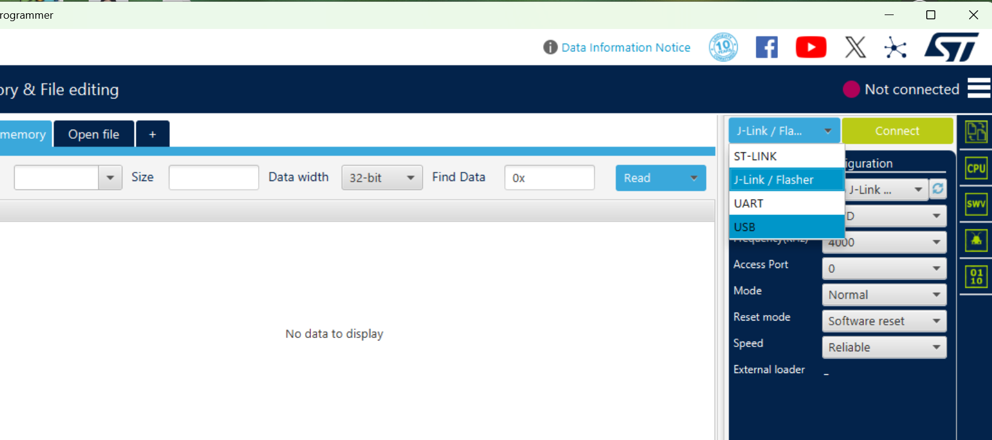
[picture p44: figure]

5) If the PORT field shows NO DFU as in the figure below, it means the device was not detected, and you need to restart this procedure or press the UPDATE button shown in the following figure.

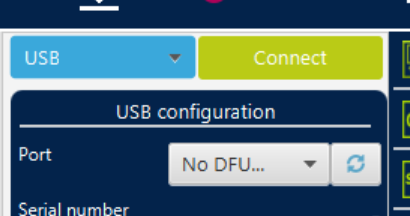
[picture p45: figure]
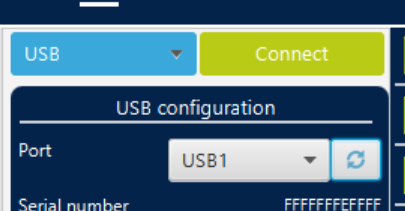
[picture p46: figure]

Device not detected Device correctly detected

6) If, upon pressing the CONNECT button, the error “device is under read out protection” appears—as shown in the figure below—it’s likely due to an incompatibility between the USB port chipset of the PC and the chip used in the Baccable. To overcome this error, you can try the procedure again using other USB ports on the PC, use a different PC, or connect a USB hub (preferably a slow one, not a new-generation model) between the Baccable and the PC. The latter method is ideal for newer PCs.

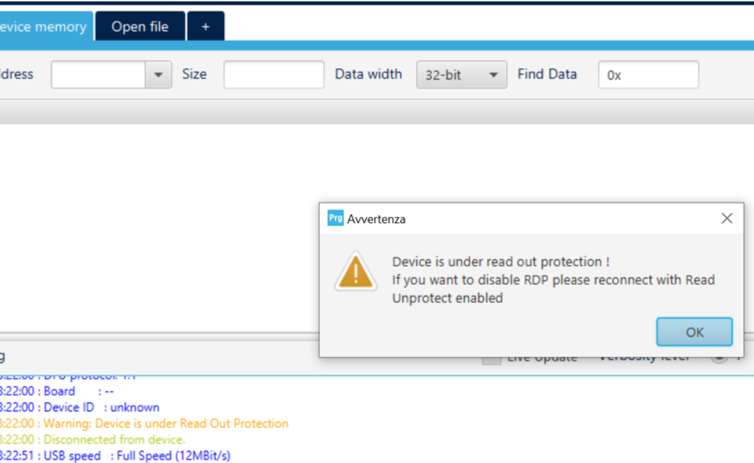
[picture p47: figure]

7) If the connection was successful, navigate to the "Erasing and Programming" section, then press the BROWSE button.

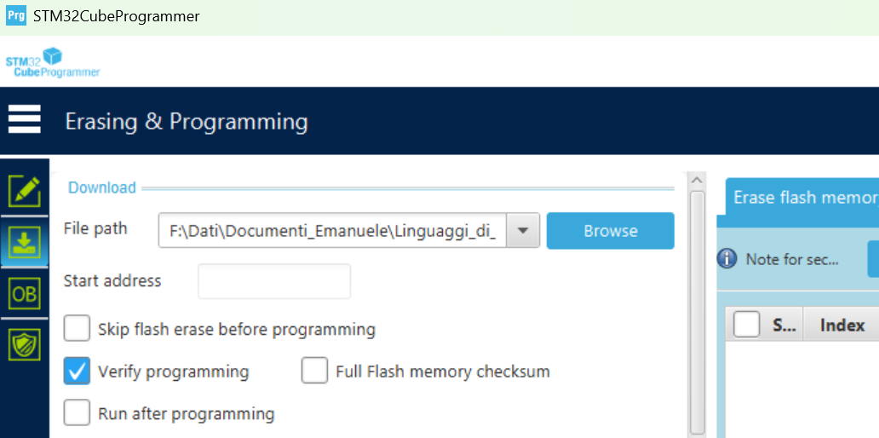
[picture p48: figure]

8) Select the .elf file you want to upload, based on the connector to which you are connected (as indicated in paragraph 1.11).
9) Select the "Verify Programming" option and press the START PROGRAMMING button.

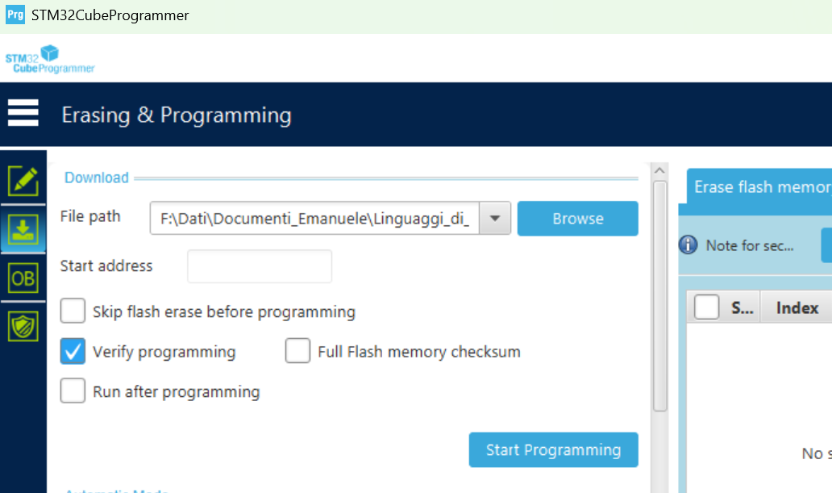
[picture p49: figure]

10) At the end of the programming process, press OK on the two confirmation popups regarding successful programming, then press DISCONNECT.

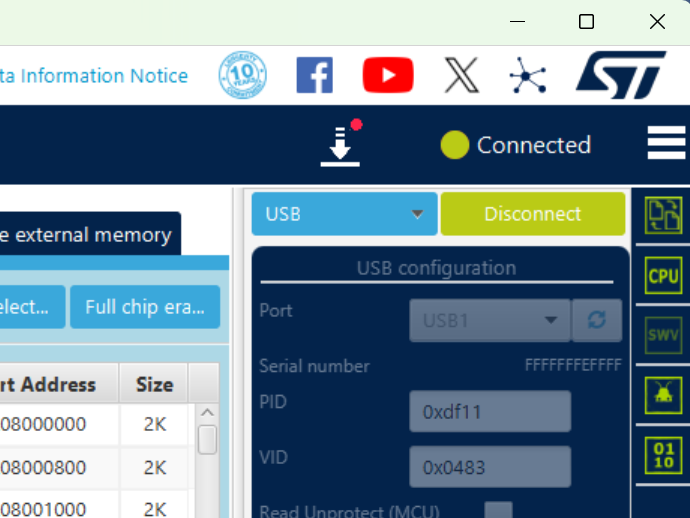
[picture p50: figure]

## 1.11.2 Procedure for firmware programming through smartphone

To carry out this procedure you will need:

- an Android smartphone
- the stmdfuusb app, downloadable from the following link or from the Play Store: https://play.google.com/store/apps/details?id=com.yatrim.stmdfuusb&pcampaignid=web_share or an equivalent one (once the 25-write limit is reached, simply clear the app data to continue using it)
- a USB cable between the smartphone and the BACCABLE
1) Press and hold the programming button on the board.
2) Connect the USB OTG cable to the smartphone, then connect the BACCABLE USB port (C1, C2 or BH) to the OTG cable.
3) Only when the green LED on the BACCABLE is lit, the programming button can be released.
4) Open the app on the smartphone: on first connection, Android will request permission to access the USB device, which must be granted to continue.
5) Select, within the app, the .elf file you want to upload, based on the USB port you are connected to (as indicated in paragraph 1.11).
6) Start the firmware write from the app.
7) Wait for the confirmation message that the write has completed, then disconnect the USB OTG cable.

Note1: the procedure is also shown in the following video: https://www.youtube.com/watch?v=NHiYqMTKCWE

Note2: as soon as the BACCABLE is connected to the smartphone, the app will show a green CONNECTED indication, confirming that the BACCABLE has been detected in programming mode. If this does not happen, disconnect the cable and restart the procedure.

# 2. USAGE

## 2.1 First Startup

When using the BACCABLE for the first time, you need to set up the functions you wish to activate on your vehicle, from among those available, by following the instructions below:

1. Insert the BACCABLE into the OBD connector.
2. Start the engine.
3. With cruise control disabled, press the RES button (or the DISTANCE button) on the steering wheel for about 2 seconds. The display where the radio station name is usually shown will display the text BACCABLE along with the installed version identifier.
4. Navigate the circular scrolling menu using the up and down buttons until you reach the item SETUP MENU.
5. Press and immediately release the RES button (or the DISTANCE button) to enter the SETUP menu. The text SAVE & EXIT will be displayed.
6. Navigate through the circular scrolling menu using the up and down buttons to scroll through the list of available functions. The symbol O to the left indicates that the function is deselected, while the symbol Ø indicates that the function is selected. The functions are described in this chapter and its subchapters.

Note 1: An exception is the engine RPM threshold for the shift function, which is detailed in paragraph 2.6, and the DIESEL/GASOLINE selection, which is detailed in paragraph 2.7.

7. Press and immediately release the RES button (or the DISTANCE button) to select or deselect the displayed function.
8. After scrolling through the entire list of functions and enabling all desired features, you will return to the SAVE & EXIT item. Press and immediately release the RES button (or the DISTANCE button) on the steering wheel to permanently save the selected settings and return to the main menu.

Note 2: The items shown in the main menu depend on the settings made within the SETUP MENU, which you can access at any time.

9. About 40 seconds after turning off the engine, the menu will automatically be disabled. To display it again, press the RES button (or the DISTANCE button) for about 2 seconds.
10. In case the vehicle is restarted, the menu will be shown again on the last displayed page before shutdown.

WARNING: The SETUP menu includes two features currently under development which should not be enabled: REMOTE START, READ FAULTS and PEDAL BOOSTER

## 2.2 Sniffer

Brief description: Act as a sniffer, connected to a Personal Computer or an Android smartphone, i.e. it allows you to record the CAN bus messages.

The baccable can be used to sniff in two different ways:

- with a dedicated firmware that lets you use it with SavvyCan on a Windows PC
- by enabling the SNIFFER function from the BACCABLE MAIN SETUP MENU, to sniff using the BACCABLE LOGGER app from a smartphone (or from a Windows PC), with a quick button to share the sniffed log online (in this case, once the USB cable is disconnected, the baccable goes back to doing its normal job)

## 2.2.1 Sniffer with dedicated SLCAN Firmware

Brief description: Act as a sniffer, connected to a Personal Computer, i.e. it allows you to record the CAN bus messages.

Note: The use of this function requires reprogramming the BACCABLE. It is not a function that can be enabled or disabled from the SETUP MENU.

1. Each USB corresponds to a specific can Bus. Reading the BACCABLE name on the case, from left to right you have BH, C2 and C1 bus.
2. Plug usb cable from desired USB bus to the PC (with windows operative System).
3. Open SavvyCan (link to the Savvycan opensource project is available in Baccable Repository in Github)
4. From top menu “Connection”, select “Open Connection Window”
5. From window “Connection Settings” press button “Add new Device Connection”
6. From “New connection” window, select option “LAWICEL/SLCAN”
7. From “New connection” window, select from drop down menu serial the com port where the Baccable was found (you can check device manager to see which virtual COM serial port is associated to BACCABLE , revealed as ST device)
8. From “New connection” window, Leave Serial port speed as default (115000bps)
9. From “New connection” window, Set Can bus speed according to the speed of the desired bus (500000bps for C1 and C2, or 125000bps for BH bus)
10. From “New connection” window, press button “create new connection”
11. Close “connection settings” window
12. If ECUs vehicle are communicating, you will see related messages in the main window of Savvycan.
13. On the right side of the window it is possible to stop and clear capture, on the bottom right side of the window it is possible to filter shown messages
14. From top menu file, you can select Save Log File or Load Log File to save current recording or to open previously recorded messages.
15. From bottom central part of the main window you can send messages to the can bus (detailed instrucions in Savvycan repository
16. From menu RE TOOLS you can select sniffer to reach a window where you can analyze changing bytes upon specific events.

## 2.2.2 Sniffer with original Firmware and proprietary app

Brief description: Act as a sniffer, connected to a Personal Computer or an Android smartphone, i.e. it is possible to record the messages present on the CAN bus

To sniff, it is necessary to:

1) connect a USB cable between the baccable and the PC, or to an Android smartphone (the USB connector to connect to must be chosen based on the bus you want to sniff from: C1 right connector, C2 central connector, BH left connector).
2) access the BACCABLE MAIN SETUP MENU, with the vehicle on, and select the SNIFFER function
3) select SAVE&EXIT to save the setting

Right away the baccable will turn into a sniffer, sending packets to the PC (or smartphone).

On the smartphone or PC, the BACCABLE LOGGER application must be installed, downloaded from the website www.tr3ma.com/baccable

Note1: 10 seconds after disconnecting the USB cable, the baccable will go back to being just a baccable. If you want to sniff again, you will need to disconnect the baccable from the OBD port and then reconnect the USB cable followed by the OBD connector.

Note2: if you are not using the sniffer, remember to disable it from the main setup menu, in order to reduce the effect of possible interference between the sniffer function and the immobilizer function during the first few seconds of operation.

The "BACCABLE LOGGER" application is very intuitive to use:

- When connected, the app will open automatically (grant the requested permissions)
- a connection button is also present at the top, although it is typically not needed.
- a button is present at the top to apply a filter to the packets
- a button is present at the top to view the event log (connection errors or packet loss)
- a button is present to share, via Telegram, WhatsApp, email, etc., the just-recorded file (CSV format) and the log file (TXT format). In the Windows version, this button gives access to the folder where all the files are recorded.

In case of packet loss, a red indication at the top of the window will show PACKET LOSS.

Every time the connection button is pressed, a new recording.CSV file and log.TXT file will be created.

## 2.3 Start&Stop disabler

Brief description: Disable start&stop, if engine rotates and if start & stop is not disabled. This is a function that can be enabled and disabled from the SETUP MENU described in paragraph 2.1.

No additional instruction is required

## 2.4 Immobilizer

Brief description: Act as immobilizer. If a connection to the RFHUB is detected, it resets the connection, preventing the addition of a key, disables the ignition, and triggers the panic alarm (if activated on the proxy). The immobilizer can be permanently deactivated and reactivated by pressing the cruise control button upwards for 30 seconds with the engine running and the cruise control deactivated. The dashboard will flash 5-6 times if the immobilizer was successfully deactivated, and 3 times if it was successfully reactivated.

The functionality IMMOBILIZER performs the following:

1. Detects if the thief is trying to connect to to RFHUB (they do it to add a key to the car)
2. Starts the Panic Alarm after one second
3. Continuously Resets the RFHUB in order to reset the thief connection, with this message for 10 seconds
4. after 10 seconds stops to send messages and stops alarm, and return listening for thief messages

Panic alarm will start only if you previously enabled panic alarm in your ECU, with the MES proxy alignment procedure.

The Immobilizer functionality will not detect the thief if you power the BACCAble with a voltage available only when the panel is switched on. Therefore, if you use immobilizer function, plug it to OBD port 12V, or directly plug the canable to the 5V usb voltage taken from the connector of the USB interface in the central area, close to cigarette lighter socket. In fact, usb voltage is switched on as soon as the thief wakes up the rfhub.

Once we start to send the rfhub reset message, neither the injition button will work. the car will appear as dead.

Immobilizer at the beginning is enabled by default. To permanently toggle the status you shall be with motor on, cruise control disabled, neutral gear, press cruise control gentle speed up for around 30 seconds. If the immo becomes disabled, it will be blink the dashboard brightness for 5-6 times. If immo becomes activates, the dashboard will blink 3 times. The change is persistent after a power loss. The current status of the Immobilizer is also displayed in the main menu of the BACCABLE with the text “IMMOBILIZER ON” or “IMMOBILIZER OFF”.

When you plug the power to BACCABLE (or if you plug baccable), if immobilizer is enabled, the blue led on BACCABLE will blink twice and the dashboard will blink once. This is useful to understand how the immobilizer is set.

To verify the correct functionality of the immobilizer, it is possible to simulate a theft attempt by connecting to the RF HUB using an ELM327 and the AlfaOBD smartphone app or the Multiecuscan application on a PC. Upon attempting to connect to the RF HUB, the ignition will no longer be possible, and the PANIC ALARM will activate, producing a periodic sound from the horn.

DON’T PANIC: simply disconnect the ELM327, wait 30 seconds, and BACCABLE will stop the panic alarm. In general, remember that by starting the vehicle, engaging gear, and driving, even at very low speeds, the panic alarm is automatically stopped by the vehicle's ECU.

## 2.5 Led Strip Controller

Brief description: Controls a WS281x LED strip according to the accelerator pedal position (requires connecting pin 8 to the LED strip (optional), while the power supply for the LED strip must be sourced from a voltage that is absent when the vehicle is off). Each gear is associated with a specific color pattern of the strip. Leds are lighted like a vumeter according to accelerator pedal press. With accelerator released, only central leds are lighted. The strip led is controlled assuming that central tunnel of the car is rounded by leds. Therefore central part of the leds strip is on the rear part of the central tunnel.

Note: This is a function that can be enabled and disabled from the SETUP MENU described in paragraph 2.1.

1. Connect pin 8 to control pin of the leds strip
2. Connect the + and – of the led strip to the desired voltage (5V or 12V of the car) ensuring it is a voltage cutted when the car goes to sleep in order to avoid battery drain. The number of leds in the strip shall correspond to the configured leds number in the firmware.

Example of voltage available only when car is on, therefore suitable for leds strip, is pin 12 (+12V) and 1 (GND) of the connector related to Start&Stop and lights panel.

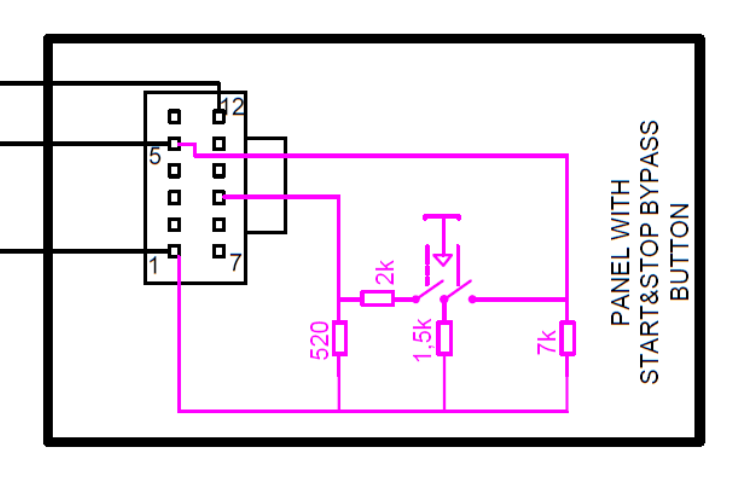
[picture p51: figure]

Connector related to Start&Stop and lights panel

## 2.6 Shift

Brief description: Shows, in race mode, the shift indicator in the dashboard (request to switch gear), when the defined engine RPM speed threshold is overcomed. The threshold is stored in the BACCABLE firmware.

Note: This is a function that can be enabled and disabled via the SETUP MENU described in paragraph 2.1. The engine RPM threshold can be modified by accessing the SETUP menu as indicated in paragraph 2.1, SHIFT RPM menu item. Each time the RES button (or DISTANCE button) is pressed, the threshold changes in a rotating menu.

No further instructions are required.

See also the following paragraph (in case of my23 or newer) and paragraph 2.10 and its connections (related to race enabling).

## 2.7 My23 IPC

Brief description: Allows, on MY23 dashboards and later versions, the correct display of the SHIFT function described in the previous paragraph.

Note: This is a function that can be enabled and disabled via the SETUP MENU described in paragraph 2.1

## 2.8 Params On Dashboard

Brief description: Shows additional parameters on the dashboard. It can be enabled with the Cruise Control RES button (or DISTANCE button), if the engine is on and the cruise control is deactivated. Navigate through the menu using the Cruise Control UP and Cruise Control DOWN buttons, and disable the controls when cruise control is activated

Note: From the SETUP MENU described in paragraph 2.1, it is possible to choose whether to set the parameters for a GASOLINE or DIESEL engine.

Usage procedure:

1. By default, the dashboard menu is disabled.
2. To enable it, the engine must be running and cruise control must be deactivated. Press the RES button (or DISTANCE button) on the steering wheel for about 2 seconds, and the menu will display the BACCABLE version on the dashboard screen where the radio station name is usually shown.
3. To navigate the rotating menu, use the cruise control up and down buttons. When you reach the SHOW PARAMS item, press and immediately release the RES button (or DISTANCE button) on the steering wheel to access the SHOW PARAMS menu, where the parameters will be displayed.
4. To scroll through the menu, use the cruise control up and down buttons (press lightly to move by 1 parameter, press firmly to move by 10 parameters) in a circular menu.
5. When cruise control is enabled, the menu controls are disabled, but the last selected parameter remains on screen and continues to update.
6. Parameters are updated every 500 milliseconds.
7. To return to the main menu, press and immediately release the RES button (or DISTANCE button) on the steering wheel. The SHOW PARAMS item of the main menu will be displayed.
8. To disable the menu, with cruise control deactivated, press the RES button (or DISTANCE button) for about 2 seconds.
9. Upon restarting the vehicle, the last parameter displayed before shutdown will automatically appear.

Known issues: It may rarely occur that the radio or Bluetooth devices send text to the dashboard in a way that temporarily freezes the string populated by BACCABLE. In such cases, try disabling and re-enabling the menu using the RES (or DISTANCE) button, or switch the dashboard screen using the right stalk button (TRIP), or perform a vehicle power cycle.

Next pages show available parameters for gasoline engines (first table) and diesel engines (second table):

GASOLINE PARAMETERS
PARAMETER | Unit | Description
PWR&TORQUE | CV & Nm | Power And Torque
Oil Press.%Water T | Bar & °C | Oil pressure and Water temperature
Oil & Water Temp. | °C & °C | Oil and water temperature
Bat SoC & Current | % & A | Battery State of charge and Current in ampere (positive values indcates charge, while negative values indicates discharge)
POWER | CV | Power calculated from torque and engine RPM
TORQUE | Nm | Torque
IC AIR OUT | °C | Intercooler output air temperature
IC AIR IN | °C | Intercooler input air temperature
BOOST ABS | BAR | Absolute Pressure
BOOST | BAR | Turbo pressure, obtained from absolute pressure
TURBO | V | Turbo Sensor Voltage
ODOMETER LAST | km | km since last odometer reset
OIL | L | Oil Quantity
OIL | BAR | Oil Pressure
OIL | °C | Oil Temperature
OIL QUALITY | % | Oil Quality
OIL UN. AIR | °C | Multiair module Oil temperature
GEARBOX | °C | Gearbox temperature
BATTERY | % | Battery charge percentage
BATTERY | A | Battery charging current (positive values mean charge, negative values mean discharge)
BATTERY | V | Battery voltage
AIR COND. | BAR | Air conditioner pressure
CUR. GEAR | - | Current gear
T-ON | m | Time since engine On
OVER RPM | s | Time in which engine was in overrun
EXAUST GAS | °C | Exaust gas temperature
CATAL. | °C | Catalytic Converter Probe Temperature
WATER | °C | Engine Coolant Temperature
KNOCK | mV | Engine Knocking
KEY IGN. | - | Ignition key ID
OVER RPM | - | Number of engine over-rev occurrences
SPARKL.1 | ° | Cylinder 1 correction
SPARKL.2 | ° | Cylinder 2 correction
SPARKL.3 | ° | Cylinder 3 correction
SPARKL.4 | ° | Cylinder 4 correction
R-DNA | - | R-DNA/DNA selector position
SPEED | km/h | speed
Seat Belt Alarm | - | It Indicates whether the acoustic warning system for the seat belts is enabled (ON) or not (OFF)
0-100km/h | Sec | Time taken to accelerate from 0 to 100 km/h. Once the vehicle exceeds 0 km/h, the status changes to GO. After a timeout, if the required speed is not reached, MISS is displayed. Once the vehicle exceeds 100 km/h, the elapsed time is shown in seconds.
100-200km/h | Sec | Time taken to accelerate from 100 to 200 km/h. Once the vehicle exceeds 100 km/h, the status changes to GO. After a timeout, if the required speed is not reached, MISS is displayed. Once the vehicle exceeds 200 km/h, the elapsed time is shown in seconds..
Best 0-100km/h | Sec | Best time in seconds from 0 to 100 km/h permanently stored in baccable
Best 100-200km/h | Sec | Best time in seconds from 100 to 200 km/h permanently stored in baccable

DIESEL PARAMETERS
PARAMETER | Unit | Description
PWR&TORQUE | CV & Nm | Power And Torque
Oil Press.%Water T | Bar & °C | Oil pressure and Water temperature
Oil & Water Temp. | °C & °C | Oil and water temperature
Bat SoC & Current | % & A | Battery State of charge and Current in ampere (positive values indcates charge, while negative values indicates discharge)
POWER | CV | Power calculated from torque and engine RPM
TORQUE | Nm | Torque
DPF | % | DPF occlusion percentage
DPF | °C | DPF temperature
DPF REGEN. | % | DPF regeneration process percentage
LAST REGEN. | km | km since last regeneration
TOT REGEN. | - | Total number of regenerations
MEAN REGEN. | km | Mean distance of regenerations
MEAN REGEN. | min | Mean time of regenerations
REGEN. | - | Type of regeneration in progress
BATT. | V | Battery voltage
BATT. | % | Battery recharge percentage
BATT. | A | Battery charge current (positive values mean in charge, negative values mean discharge)
OIL QUALITY | % | Oil quality
OIL | °C | Oil Temperature
OIL | BAR | Oil Pressure
OIL | mm | Oil level in the oil pan in mm (from 50 to 70 mm)
ADBLUE | L | ADBLUE level in Liters
ADBLUE | % | ADBLUE level in percentage
GEARBOX | °C | Gearbox temperature
EXAUST GAS | °C | Exhaust gas temperature (turbo input)
CUR. GEAR | - | Current gear
WATER | °C | Water temperature
EGR CMD | % | EGR valve command
EGR | % | EGR valve status
TURBO REQ. | BAR | Turbo pressure request
TURBO REQ. | % | Turbo request percentage
TURBO | °C | Turbo temperature
TURBO | BAR | Turbo Pressure
TURBO | % | Turbo Percentage
BOOST REQ. | BAR | Boost request pressure
BOOST | V | Boost sensor voltage
RAIL | BAR | Rail pressure
DIESEL | °C | Diesel temperature
ODOM. LAST | km | km since last odometer reset
AIR COND. | BAR | Air conditioner pressure
FUEL CONS. | L./h | Diesel consume
DEBIMETER | °C | Debimeter temperature
SPEED | km/h | Speed
Seat Belt Alarm | - | It Indicates whether the acoustic warning system for the seat belts is enabled (ON) or not (OFF)
0-100km/h | Sec | Time taken to accelerate from 0 to 100 km/h. Once the vehicle exceeds 0 km/h, the status changes to GO. After a timeout, if the required speed is not reached, MISS is displayed. Once the vehicle exceeds 100 km/h, the elapsed time is shown in seconds.
100-200km/h | Sec | Time taken to accelerate from 100 to 200 km/h. Once the vehicle exceeds 100 km/h, the status changes to GO. After a timeout, if the required speed is not reached, MISS is displayed. Once the vehicle exceeds 200 km/h, the elapsed time is shown in seconds..
Best 0-100km/h | Sec | Best time in seconds from 0 to 100 km/h permanently stored in baccable
Best 100-200km/h | Sec | Best time in seconds from 100 to 200 km/h permanently stored in baccable

Note: Each param can be hidden or shown from the PARAMS SETUP MENU.

## 2.9 Route

Brief description: Redirect the internal CAN bus messages to OBD peripherals that asks for a specific parameter. This allows displaying parameters on a smartphone that are normally not accessible using just the ELM327.

Note: This is a function that can be enabled and disabled via the SETUP MENU described in paragraph 2.1

You can route native messages encapsulating them in uds parameter response, in order to make them available to diagnostic requests performed with OBD (you can get parameters commonly not available in OBD apps). This functionality performs the following: Upon receive of UDS request with message id 0x18DABAF1 having message data 0622xzyyyyyyyy, Baccable will understand the following:

- 0x18DABAF1 identifies that the message is a Route request (request to route a native message to the diagnostic)
- The route is done just one time (one packet) to avoid bus flood, and it routes only 5 bytes of the requested message
- x (first nibble of third byte of the can message) can be 0 (std Id) or 1 (Ext Id).
- z (second nibble of third byte of the can message) is the offset of the message to route. the number of bytes routed will be only 5. offset will set the part of the message to route
- yyyyyyyy is the requested msg id right aligned.

Example1:

Diagnostic sends msgID 0x18DABAF1 with data 062201000004B2

BACCABLE replies msgID 0x18DAF1BA with data 076201AABBCCDDEE where AA is the second byte of the original 0x4b2 message

Example2:

Diagnostic sends msgID 0x18DABAF1 with data 062210E10204B2

BACCABLE replies msgID 0x18DAF1BA with data 076210AABBCCDDEE where AA is the first byte of the original 0xE10204B2 message

The following image summarizes the route functionality:

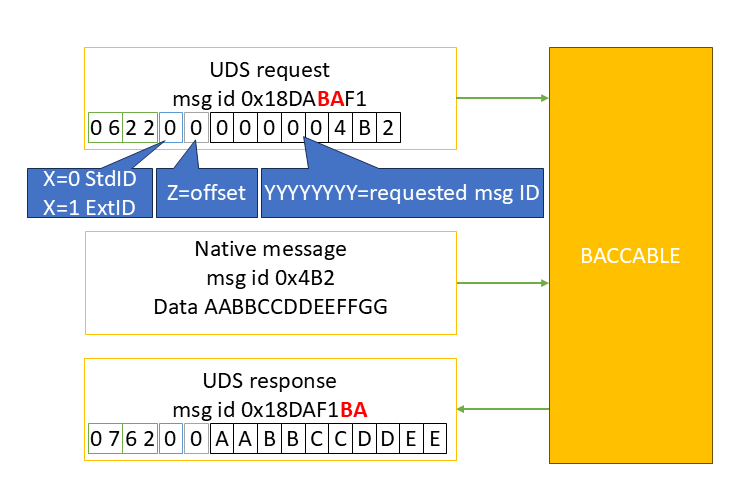
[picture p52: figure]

Route messages handshake sequence

## 2.10 ESC+TC Selector

Brief description: Enables and disables, if the race mode was previously enabled with a proxy alignment procedure (see para.2.19), the ESC (Electronic Stability Control) and TC (Traction Control). It is activated by pressing the button on the left lever (Lane) for at least 3 seconds. When activated, the “ESC OFF” indicator and the collision avoidance disabled icon will be shown on the dashboard, together with standard race masks.

Alternatively, this function can be enabled or disabled from the main menu of the BACCABLE by scrolling through the list and pressing RES (or the DISTANCE button) on the “TOGGLE ESC/TC” item, if it has been previously enabled in the SETUP MENU as described in section 2.1.

Note: This is a function that can be enabled or disabled from the SETUP MENU as detailed in section 2.1.

No further instructions are required.

## 2.11 DYNO

Brief description: Disables all controls (included ABS, ESC, TC…). This works on stock Giulia/Stelvio too.

Note: This is a function that can be enabled or disabled from the SETUP MENU as detailed in section 2.1.

1. The function is activated and deactivated by pressing the PARK button for a few seconds.
2. Alternatively, this function can be enabled or disabled from the main menu of the BACCABLE by scrolling through the list and pressing RES (or the DISTANCE button) on the “TOGGLE DYNO” item, if it has been previously enabled in the SETUP MENU as described in section 2.1.
3. Once activated, a sequence of alerts will be displayed on the dashboard, indicating that the function is active.
4. Pressing the PARK button again, turning off the vehicle, or selecting “TOGGLE DYNO” from the menu will deactivate the function, and the alerts will disappear from the dashboard.

Warning: This function should only be activated or deactivated when the vehicle is stationary.

Known issues: On some Giulia/Stelvio models, it may occasionally happen that some faults remain displayed on the dashboard after deactivating the function. In such cases, perform a vehicle ignition cycle, or select the CLEAR FAULT function as described in section 2.13.

Note: You can quickly scroll through the dashboard alerts by pressing the TRIP button on the right-hand stalk.

## 2.12 ACC Virtual Pad

Brief description: Detects the button presses on the Cruise Control keypad, replacing them with those of the Adaptive Cruise Control (ACC) keypad. This eliminates the need to purchase the ACC keypad on the steering wheel. It is dependent on performing a proxy alignment to enable ACC and disable CC

Note: This is a function that can be enabled or disabled from the SETUP MENU, as described in section 2.1.

Pressing the Cruise Control button will activate or deactivate the Adaptive Cruise Control.

Pressing the RES button while Adaptive Cruise Control is active will change the distance from the vehicle ahead.

Warning: A proxy alignment must first be performed to enable Adaptive Cruise Control and disable standard Cruise Control, in the same way as required when replacing the standard Cruise Control button panel with the ACC version. The vehicle must, of course, be properly equipped (presence of a front radar with compatible ECU firmware and automatic transmission).

## 2.13 CLEAR FAULTS

Brief description: Clears all error codes, if present, from all the vehicle's ECUs (across all 3 CAN buses).

Note: This is a function that can be enabled or disabled from the SETUP MENU, as described in section 2.1.

Once this function is enabled, the CLEAR FAULTS option will appear in the BACCABLE main menu. Pressing and immediately releasing the RES button (or DISTANCE button) will display the message WAIT for a few seconds. After the command is executed, the message CLEAR FAULTS will reappear.

## 2.14 REGENERATION ALERT

Brief description: Triggers a visual and audible alert whenever a DPF regeneration occurs (DIESEL vehicles). By default, only certain types of regeneration are shown to the user. This function allows for a notification to be received every time, starting from the post-injection phase, which is part of the regeneration process.

Note: This is a function that can be enabled or disabled from the SETUP MENU, as described in section 2.1.

## 2.15 4WD DISABLER

Brief description: Disables all-wheel drive. To be enabled only on vehicles equipped with this feature.

Note 1: This is a function that can be enabled or disabled from the SETUP MENU, as described in section 2.1.

Once the function has been enabled through the SETUP menu, a new option “4WD ENABLED” will appear in the BACCABLE main menu, indicating the default condition for AWD vehicles. Pressing and immediately releasing the RES button (or DISTANCE button) on the steering wheel will change the menu to display “4WD DISABLED.”

Note 2: This function can only be activated while the vehicle is stationary.

## 2.16 BRAKES OVERRIDE

Brief description: Activates and deactivates the front brakes via the RES button (or DISTANCE button) on the steering wheel.. This function implements the commonly called “launch assist” and “burn out”.

Note1: This is a function that can be enabled or disabled from the SETUP MENU, as described in section 2.1.

Once this function has been enabled via the SETUP menu, an additional option “Front Brake Normal” will appear in the BACCABLE main menu, indicating the default condition.

Note2: before using this function, it is necessary to enable the DYNO in order to ensure maximum power delivery to the wheels.

## 2.16.1 Launch Assist

By Moving to the Baccable ‘s main menu, on the “Front Brake Normal” item, with the engine running, without engaged handbrake, and the brake pedal released, by p ressing and immediately releasing the RES button (or DISTANCE button) on the steering wheel will change the menu to display “Front Brake ASSIST” and the brake will engage. Only front brakes will be engaged.

In this mode, the brakes will be automatically released upon exceeding the torque value in Nm previously set in the setup menu under the item LAUNCH TORQUE.

As soon as acceleration begins to apply torque to the wheels, the screen will display the current torque and the threshold torque in a string (example: 15Nm/150Nm where 15Nm is the current torque and 150Nm is the threshold torque set in the setup menu).

Once the set torque threshold is exceeded, the brakes are automatically released and the dashboard shows the parameter “Best Time 0-100km/h” (best time in seconds taken to reach 100km/h) from the SHOW PARAMS section. For details on how the “Best Time 0-100km/h” parameter works, refer to paragraph 2.8.

## 2.16.2 Burn Out

By moving to the Baccable’s main menu, on the “Front Brake Normal” item, with the engine running, the car without the handbrake engaged, and the brake pedal released, pressing and immediately releasing the RES button (or DISTANCE button) on the steering wheel, the menu will display “Front Brake Assist” and the brake engagement will be perceptible. Only the calipers of the front wheels will be activated. Pressing the RES button again, the dashboard will display the message “Front Brake FORCED”.

In this mode, the brake will be released only by pressing the RES button again.

Pressing and immediately releasing the RES button (or DISTANCE button) again will release the brake and the menu will show “Front Brake Normal” again.

Note 3: For a proper burnout on 2WD vehicles, it is mandatory to first disable stability controls by activating the DYNO function. Then activate the front brakes using the function described in this section. After a few seconds of throttle application and once smoke appears from the rear tires, press the button again to release the front brakes.

Note 4: This function can only be activated while the vehicle is stationary.

WARNING: It is strongly recommended to deactivate the BRAKES OVERRIDE function via the SETUP menu when not in use.

WARNING: This function causes significant stress on all mechanical components involved, including suspension, half-shafts, clutch, and flywheel. Apply throttle decisively to quickly overcome the tires’ initial friction, which is the point of highest mechanical stress.

## 2.17 REMOTE START

Under development. Do not activate this function.

## 2.18 READ FAULTS

Brief description: Allows you to read fault codes from the vehicle’s control units (for now, only from the Body Computer)

The READ FAULTS function must first be activated by accessing the MAIN SETUP MENU, selecting the READ FAULTS function, and then selecting SAVE&EXIT to permanently save the setting. A new item, READ FAULTS, will now appear in the main menu. Pressing the RES or DISTANCE button (on the steering wheel) after navigating to the READ FAULTS item in the BACCABLE main menu will show a WAIT indication, signalling that you need to wait while the faults are read from the vehicle’s control unit. Once reading is complete, a submenu will automatically open showing the detected faults, identified by their error code and the name of the control unit they belong to. You can then scroll through the list using the up-down buttons on the Cruise Control keypad. To return to the main menu, simply press the RES or DISTANCE button on the steering wheel again.

## 2.19 ODOMETER BLINK

2.19 ODOMETER BLINK

Brief description: Hides the odometer blinking on the dashboard.

Note: This is a function that can be enabled and disabled from the SETUP MENU described in para.2.1.

Typically, the odometer blinks to indicate an unsuccessful proxy alignment. Once this function is enabled, the odometer blinking will be stopped.

One of the applications of this function is summarized below:

Premise: Proxy alignment is a procedure to be performed with Multiecuscan, an elm327 and suitable cables, which synchronizes the electronic control units (ECUs) with each other so that all modules recognize the current vehicle configuration. Among these configurations is the activation of race mode, which allows the ESC/TC function of the BACCABLE to be used without installing the RDNA selector. The activation of race mode via alignment procedure is well described at the following link: https://giuliatech.com/t/how-to-enable-race-mode-on-non-qv-giulia-2017-2024/21

The above procedure describes the necessary steps for hardware modification of the vehicle and those for proxy alignment. The part relevant to use with the Baccable is only the proxy alignment section.

Activating Race via Proxy alignment causes the loss of pedal maps, meaning all DNA driving styles adopt the N mode map, which has a linear curve, while Dynamic should have a very sensitive tip-in curve. To solve this issue, it is possible to disable race via proxy alignment on the engine ECU only. This way, the pedal maps return to their correct curve, and race remains available. To achieve this result, after successfully completing the race activation procedure as per the link in the Premise, simply set, in proxy setup, the selector type 1 (meaning: disable race), disconnect the elm327 from the vehicle and start the proxy alignment procedure. The first ECU that MES will try to write is the body, then failing to do so (since the elm327 will be disconnected), it will report an error. At that moment, we must reconnect the elm327 because the second ECU to be written will be the engine ECU. As soon as successful writing of the engine ECU is reported, we must again remove the elm327, or disconnect the USB cable if using a USB elm327, to prevent Multiecuscan from writing the other ECUs. At this point, by turning the vehicle off and on again, after a while, the odometer will start blinking to indicate an incomplete proxy alignment, the pedal maps will work as originally intended, and the ESC/TC function of the BACCABLE will operate normally. To eliminate the annoying odometer blinking, we will select the ODOMETER BLINK function in the BACCABLE setup menu.

## 2.20 SEAT BELT ALARM

Brief description: Disables the acoustic warning indicating unfastened seat belts.

Note: This is a function that can be enabled and disabled from the SETUP MENU described in para.2.1.

By deselecting this function in the setup menu, the acoustic warning indicating unfastened seat belts is disabled. The setting is permanent even after removing the BACCABLE and may require a restart to take effect

## 2.21 PEDAL BOOSTER

Under development. Do not activate this function.

Brief description: Pedal booster with customized maps based on the selected driving style.

Premise: A pedal booster is an electronic device that connects between the accelerator pedal and the Body (vehicle ECU) to improve vehicle response. It does not increase engine power but makes acceleration more prompt and smooth.

Note: To use this function, a specific connection cable between Baccable and Pedal Booster is required, available separately.

In the setup menu, the function can be set as follows (rotary menu activated by pressing the RES and DISTANCE buttons):

1) Pedal Booster Deselected: the function does not control the analog signals from the pedal to the body.
2) Pedal Booster Auto: the function assigns different pedal maps to different driving styles, appropriately amplifying and attenuating the analog signals from the accelerator pedal.
3) Pedal Booster Bypass: the function does not alter the analog signals from the accelerator pedal but simply repeats them.
4) Pedal Booster A Map: the function forces the use of the pedal map associated with driving style A (All weather), appropriately amplifying and attenuating the analog signals from the accelerator pedal.
5) Pedal Booster N Map: the function forces the use of the pedal map associated with driving style N (Natural), appropriately amplifying and attenuating the analog signals from the accelerator pedal.
6) Pedal Booster D Map: the function forces the use of the pedal map associated with driving style D (Dynamic), appropriately amplifying and attenuating the analog signals from the accelerator pedal.
7) Pedal Booster R Map: the function forces the use of the pedal map associated with driving style R (Race), appropriately amplifying and attenuating the analog signals from the accelerator pedal.

## 2.22 MAIN SETUP MENU

It is accessible from the main menu and allows you to enable and disable each individual function of the baccable. See para. 2.1

## 2.23 PARAMS SETUP MENU

It is accessible from the main menu and allows you to hide or show each individual parameter of the SHOW PARAMS menu. See para. 2.8

## 2.24 SHOW RACE MASK

Brief Description: shows race screens on the dashboard and infotainment system when the ESC/TC function is active. See para. 2.10.

WARNING: If flickering of the race display masks occurs on the dashboard or infotainment system of your vehicle, it is recommended to disable and avoid using the SHOW RACE MASK function.

## 2.25 PARK MIRROR

Brief Description: It moves the side mirrors to display the rear wheels when reverse gear and either the left or right turn signal are activated, in order to assist with parking near curbs.

Note: This function only works on vehicles equipped with mirror encoders. To check compatibility with your vehicle, simply test the feature.

Usage Procedure:

1) Position both side mirrors so that the rear wheel area is clearly visible.
2) Access the MAIN SETUP MENU and enable the PARK MIRROR function. If it is already selected, deselect it and then reselect it. At this stage, the current mirror positions will be stored.
3) Select SAVE & EXIT to permanently save the settings and exit the MAIN SETUP MENU. These steps will not need to be repeated.
4) Reposition the side mirrors to their normal operating position.
5) From now on, whenever reverse gear and the left turn signal are activated, the left mirror will automatically move to the previously stored position set during the function activation. Once reverse gear is disengaged, the mirror will return to its normal position. The same logic applies to the right mirror when the right turn signal and reverse gear are activated.

## 2.26 ACC AUTOSTART

Brief Description: On vehicles equipped with ACC, when the vehicle with ACC engaged comes to a stop behind the preceding vehicle, this function allows ACC to remain engaged—whereas normally, ACC would automatically disengage approximately 5 seconds after stopping.

This function can be set, in SETUP MENU, as “ACC AUTOSTART R” or “ACC AUTOSTART +”, depending on whether the vehicle in use allows restarting by pressing the RES button or the button to increase the Cruise Control speed. Once the function is activated, the Baccable will ensure the automatic restart of the vehicle after a stop occurred with ACC engaged.

## 2.27 CLOSE WINDOWS

Brief Description: Allows the activation of the power windows when locking the vehicle, with multiple configuration options.

The CLOSE WINDOWS function supports various options, which can be selected using the RES or DISTANCE button after navigating to the CLOSE WINDOWS item in the MAIN SETUP MENU:

OPZIONE | DESCRIZIONE
O CLOSE WINDOWS 1 | Close windows deselected, the vehicle will act normally
Ø CLOSE WINDOWS 1 | Close windows 1 selected. With a single activation of the vehicle lock via remote control, the vehicle doors are locked and the windows are closed. With two consecutive activations of the vehicle lock via remote control, the windows are first closed and then slightly reopened to allow air circulation.
Ø CLOSE WINDOWS 2 | Close windows 2 selected. With two consecutive activations of the vehicle lock via remote control, the windows are closed. With three consecutive activations of the vehicle lock via remote control, the windows are closed and then slightly reopened to allow air circulation.

## 2.28 OPEN WINDOWS

Brief Description: Allows the activation of the power windows when unlocking the vehicle, with multiple configuration options.

The OPEN WINDOWS function supports various options, which can be selected using the RES or DISTANCE button after navigating to the OEPN WINDOWS item in the MAIN SETUP MENU:

OPZIONE | DESCRIZIONE
O OPEN WINDOWS 1 | OPEN windows deselected, the veichle will act normally
Ø OPEN WINDOWS 1 | OPEN windows 1 selected. With a single activation of the vehicle unlock via remote control, in addition to unlocking the vehicle doors, the windows are fully opened.
Ø OPEN WINDOWS 2 | OPEN windows 2 selected. With a double activation of the vehicle unlock via remote control, in addition to unlocking the vehicle doors, the windows are fully opened.

## 2.29 HAS VIRTUAL PAD

Brief Description: Simulates the press of the HAS (Highway Assist System) button.

The HAS VIRTUAL PAD function allows the HAS button press to be simulated by double-clicking the LANE button (located on the stalk to the left of the steering wheel). This eliminates the need to purchase the dedicated keypad.

Note: The HAS function requires activation via proxy alignment (Byte 166, bit 2 — i.e., binary format xxxxx1xx to enable it), along with the following prerequisites. Vehicle must be MY20 or later, equipped with a camera with compatible firmware, Steering wheel with touch sensors or a bypass for those sensors, Motorized steering wheel with compatible A420 firmware, Navigation system enabled via proxy and available, Adaptive Cruise Control (ACC).

## 2.30 QV EXHAUST FLAP

Brief Description: This function opens Giulia Quadrifoglio exhaust valve, by twice pressing RELEASE button located on the gear lever (or by selecting TOGGLE QV VALVE on main menu).

## 2.31 FRONT PARK MUTE

Brief description: Temporarily mutes the acoustic warning if a frontal obstacle is detected and the vehicle is stationary.

## 2.32 ELM327

Brief description: Turns the baccable into an ELM327 capable of automatically connecting to the vehicle’s 3 BUSes, without the need for special cables and without moving the USB connector from the C1 port.

To use the ELM327 function, you need to:

1) connect a USB cable between the baccable and the PC, or to an Android smartphone, using the right-hand connector of the baccable (C1)
2) access the BACCABLE MAIN SETUP MENU, with the vehicle on, and select the ELM327 function
3) select SAVE&EXIT to save the setting

Right away the baccable will turn into an ELM327.

On the smartphone or PC, install the desired application (e.g. Multiecuscan, alfaobd, etc.)

Note1: 10 seconds after disconnecting the USB cable, the baccable will go back to being just a baccable. If you want to use it as an ELM327 again, you will need to disconnect the baccable from the OBD port and then reconnect the USB cable followed by the OBD connector.

Note2: if you are not using the ELM327 function, remember to disable it from the main setup menu, in order to reduce the effect of possible interference between the ELM327 function and the immobilizer function during the first few seconds of operation.

BACCABLE OBD V.4.6 MANUAL Date: 27/08/2026

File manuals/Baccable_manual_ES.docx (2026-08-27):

OBD BACCABLE

MANUAL

AVISO LEGAL: BACCABLE es un proyecto desarrollado exclusivamente con fines educativos y de investigación. Está estrictamente prohibido el uso de esta herramienta en vehículos que circulen por vías públicas o en cualquier contexto que pueda causar daños a personas, bienes, o infringir la normativa vigente.

El autor de este proyecto no asume ninguna responsabilidad por daños, fallos o consecuencias derivadas del uso de BACCABLE. El usuario final asume toda la responsabilidad civil, penal y legal por su uso.

Se recomienda encarecidamente no utilizar este proyecto en aplicaciones reales sobre vehículos.

La instalación en una ubicación oculta requiere conocimientos técnicos específicos en sistemas eléctricos y electrónicos del automóvil para evitar errores que puedan suponer riesgos para la seguridad.


ÍNDICE

# 1. INSTALACIÓN

## 1.1 Composición


Composición

El cable y las “tomas de derivación” (conectores rápidos o IDC) que se muestran en la foto anterior son opcionales. El Baccable puede utilizarse conectándolo directamente al OBD si el vehículo no está equipado con un SGW o si dispone de un bypass del SGW (SGW = Secure Gateway, puerta de enlace segura). Por lo tanto, el uso del cable incluido y de los conectores rápidos no es obligatorio.

## 1.2 Distribución de pines

El Baccable OBD V.3 está equipado con un conector OBD con la siguiente distribución de pines:


Distribución de pines de BACCABLE y del cable OBD

El pin 16 corresponde a la alimentación de 12V del puerto OBD del vehículo, pero también puede conectarse a una alimentación de 5V si es necesario, ya que el BACCABLE admite un amplio rango de tensiones de entrada.

## 1.3 Instrucciones de instalación (en el puerto OBD)

1) Al insertar el BACCABLE en el puerto OBD del vehículo, tenga cuidado de no pulsar el botón PROGRAMMING. Si esto ocurre, retire el BACCABLE y vuelva a insertarlo.


PROGRAMMING

Botón PROGRAMMING

2) Al retirar el BACCABLE del puerto OBD del vehículo, no tire de la carcasa. En su lugar, empuje colocando la punta de los dedos en el lado del conector OBD hacia usted, para evitar forzar el enganche que mantiene unidas la carcasa (la parte con la etiqueta “BACCABLE”) y la parte donde se encuentra el conector OBD.

Si el ensamblaje se desengancha accidentalmente, retire por completo las partes (placa PCB y carcasa) del conector OBD. A continuación, vuelva a insertar la PCB (placa de circuito impreso) en la carcasa con la etiqueta “BACCABLE”, alineando las partes como se muestra en la imagen anterior. Después, inserte el lado con el conector OBD hasta que toque la carcasa.

ADVERTENCIA: El conector OBD debe tener los dos pines más largos alineados con el lado largo. Si se inserta incorrectamente, retire el lado del conector OBD, gírelo y vuelva a insertarlo.

Una vez que el lado del conector OBD esté en contacto con la carcasa, sujete firmemente el BACCABLE y presione con firmeza las cuatro esquinas, asegurándose de que la tapa encaje gradualmente por todos los lados hasta quedar completamente asegurada.

## 1.4 Instrucciones de instalación del cable OBD (opcional)

1) Además del cable, se incluyen IDC (también conocidos como “tomas de corriente”). Son conectores rápidos que permiten derivar la señal deseada sin interrumpir el cableado del vehículo. Los conectores rápidos dobles están diseñados para los pines H y L, mientras que los individuales pueden usarse para la alimentación o para los pines H y L.
2) El conector rápido puede engarzar una amplia gama de calibres de cable; sin embargo, esta versatilidad hace que el conector rápido doble sea más complejo de usar. Para fijar los cables del conector rápido doble en el bus CAN, no basta con insertar los cables en la ranura y cerrar la tapa. Primero es necesario, con un destornillador plano pequeño, empujar el cable dentro de la guillotina para que penetre correctamente. Si esta operación previa se realiza correctamente, al cerrar firmemente la tapa del conector se activarán los clips de bloqueo, garantizando que el conector quede bien cerrado sin huecos entre la tapa transparente y la base negra. El conector rápido individual rojo, en cambio, puede apretarse con alicates, por lo que no requiere pasos previos. Compruebe siempre la solidez de la conexión después de apretar.

La siguiente imagen muestra los pines del conector de diagnóstico OBD (el conector de la imagen se observa desde el lado de los pines externos, no desde el lado de los cables). Los pines 4 y 5 son la masa (GND), y el pin 16 es el de 12 voltios.


## 1.5 Primer arranque (con cableado adicional)

Durante el primer arranque, realice las siguientes comprobaciones preliminares:

1. Verifique que todas las conexiones se hayan realizado según el diagrama y los requisitos definidos en este documento.
2. Con el contacto puesto, compruebe que el LED verde del interior de la carcasa del BACCABLE esté encendido, confirmando la correcta recepción de alimentación.
3. Si el cuadro de instrumentos no se enciende o aparecen errores aleatorios, compruebe que los pines H y L no se hayan invertido o que ninguno de ellos se haya conectado por error a otro cable.
4. Compruebe que el LED azul interno parpadee dos veces al arrancar, lo que indica la correcta activación de la función Inmovilizador, habilitada por defecto (nota: sin una alineación perfecta entre el ojo y el LED, puede que no sea visible; puede que sean necesarios varios arranques para realizar esta comprobación).
5. En cuanto se inserta el BACCABLE, si el cuadro de instrumentos del vehículo ya está encendido, este debería parpadear una vez para indicar que el inmovilizador está activo (habilitado por defecto). Si esto no ocurre, compruebe las conexiones al bus CAN.

## 1.6 Primer arranque (inserción en el puerto OBD estándar)

En el primer uso, debe definir qué funciones desea utilizar en su vehículo accediendo al menú SETUP.

Las instrucciones para acceder al menú SETUP, desplazarse por la lista de funciones disponibles, activar/desactivar funciones y guardar los ajustes de forma permanente se indican en el apartado 2.1.

## 1.7 Notas sobre las conexiones a 5V (opcional)

Si el BACCABLE se alimenta con la fuente de 5V, puede conectarlo, por ejemplo, al USB HUB situado en la guantera de la consola central, junto al freno de mano. Esta tensión está activa en cuanto se accede al vehículo, pero también al conectarse al RF HUB como ladrón. Para acceder a esta tensión, siga estas instrucciones:

1. Retire y desconecte el USB HUB del vehículo.
2. Separe las 4 lengüetas de la tapa trasera con destornilladores pequeños y pinzas, y luego extraiga la placa de circuito impreso.
3. Perfore un agujero en el plástico trasero en la zona no ocupada por conectores para permitir el paso del cable, como se muestra en la figura (asegúrese de perforar un orificio preciso para evitar que el cable quede demasiado suelto; si es necesario, aplique una gota de silicona en el interior al final para dar resistencia en caso de que se tire del cable).
4. Suelde el cable a la placa de circuito impreso del USB HUB, en el pin +5V del conector USB. Puede usar las imágenes de referencia siguientes para identificar el pin correcto.


## 1.8 Notas sobre las conexiones al bus CAN

Si el vehículo está equipado con un SGW (Secure Gateway), los pines del puerto OBD no podrán utilizarse para conectar el BACCABLE. En su lugar, será necesario utilizar un cableado de bypass del SGW, disponible para comprar en línea, que proporcionará un puerto OBD para la conexión del BACCABLE. Alternativamente, puede interceptar los cables del bus CAN deseado en otros puntos del vehículo, aguas arriba del SGW.

## 1.9 Ejemplos de conexión

Ejemplo 1 de un punto aguas arriba del SGW donde se puede detectar el bus C1:


Ejemplo 2 de un punto aguas arriba del SGW donde se puede detectar el bus C1:

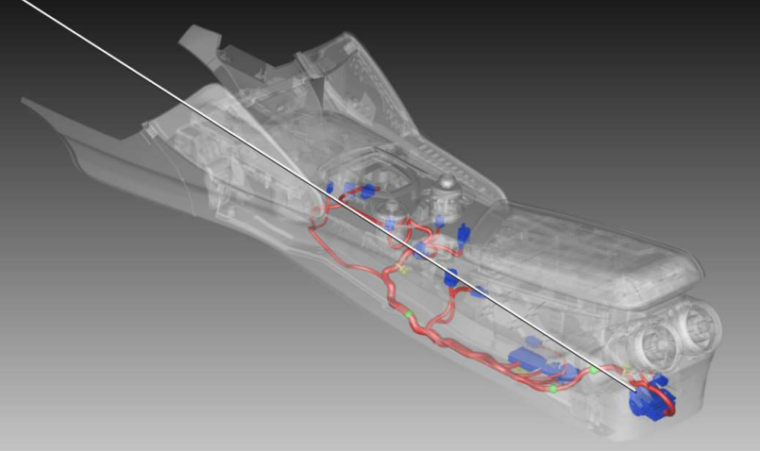
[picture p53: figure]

Ejemplo 3 de un punto aguas arriba del SGW:

En el caso de una transmisión automática, se puede utilizar el siguiente extracto del manual, junto con la distribución de pines del conector de la transmisión:

Ejemplo 4 de un punto aguas arriba del SGW:

En la Body, situada en la zona de los pies del acompañante, se encuentran todas las líneas de bus y la alimentación.


Bus CAN y alimentación en la Body Computer

La siguiente imagen muestra la disposición de los conectores de la Body:


Conector C4 de la Body Conector C8 de la Body

## 1.10 CARACTERÍSTICAS TÉCNICAS

Dimensiones: 57,5mm (ancho) x 44,5mm (alto) x 22mm (profundidad)

Peso: menos de 50 gramos

Tensión de alimentación: 4,5V - 35V (DC)

Consumo de corriente a 12V: aproximadamente 11mA con el vehículo apagado en modo de reposo. Menos de 30mA durante el funcionamiento con el vehículo encendido.

## 1.11 ACTUALIZACIÓN DE FIRMWARE

El BACCABLE se entrega preprogramado con la última versión de firmware disponible; sin embargo, es posible beneficiarse de futuras actualizaciones de firmware mediante el procedimiento de actualización de firmware.

Para empezar, visite la página de releases de BACCAble en GitHub, desde un PC o desde un smartphone Android: https://github.com/gaucho1978/BACCAble/releases/ y descargue la última versión STABLE disponible para el BACCABLE.

Botón de programación

Conector USB Bus C1

Conector USB Bus C2

Conector USB Bus BH

Conectores y botón de programación, utilizados durante la fase de programación

Los archivos que hay que usar son:

- baccableBH_stable.elf (para cargar conectado al conector USB BH)
- baccableC1diesel_stable.elf (para cargar conectado al conector USB C1)
- baccableC2_stable.elf (para cargar conectado al conector USB C2)

Realice el procedimiento de carga del firmware en los tres conectores USB, cargando el firmware correspondiente en cada puerto USB de la siguiente manera:

- baccableC1diesel_stable.elf en USB C1

- baccableC2_stable.elf en USB C2

- baccableBH_stable.elf en USB BH

A continuación se describen 2 procedimientos: uno para cargar el firmware mediante un PC con Windows, y el otro para cargar el firmware mediante un smartphone Android.

## 1.11.1 Procedimiento para la programación del firmware mediante PC

Para llevar a cabo este procedimiento necesitará:

- un PC con sistema operativo Microsoft Windows y puerto USB
- el software STM Cube Programmer para PC Windows, que puede descargarse desde el sitio web de ST tras un registro gratuito, mediante el siguiente enlace: https://www.st.com/en/development-tools/stm32cubeprog.html
- un cable USB para conectar el PC al BACCABLE
1) Mantenga pulsado el botón de programación de la placa
2) Conecte el puerto USB (C1, C2, BH) al PC. La placa será reconocida por el PC como un dispositivo serie llamado “STM32 Bootloader”
3) Solo cuando el LED verde esté encendido, se puede soltar el botón de programación

Nota1: Si el LED verde del BACCABLE parpadea o emite una luz débil, use un cable USB más corto o sustituya el cable USB

Nota2: Si el PC no detecta la placa, asegúrese de haber pulsado correctamente el botón de programación antes de conectar el cable USB, y manténgalo pulsado hasta que el conector USB esté completamente insertado por ambos lados. Si el problema persiste, gire 180 grados el conector USB-C en el lado del BACCABLE y vuelva a intentarlo

4) Abra el software STM32CubeProgrammer, seleccione USB en el menú desplegable (en el lado derecho de la ventana) y pulse el botón CONNECT


5) Si el campo PORT muestra NO DFU como en la figura siguiente, significa que el dispositivo no fue detectado, y deberá reiniciar este procedimiento o pulsar el botón UPDATE que se muestra en la siguiente figura.


Dispositivo no detectado Dispositivo detectado correctamente

6) Si, al pulsar el botón CONNECT, aparece el error “device is under read out protection” como se muestra en la figura siguiente, probablemente se deba a una incompatibilidad entre el chipset del puerto USB del PC y el chip utilizado en el Baccable. Para superar este error, puede intentar de nuevo el procedimiento usando otros puertos USB del PC, usar otro PC, o conectar un hub USB (preferiblemente uno antiguo, no de última generación) entre el Baccable y el PC. Este último método es ideal para PCs más recientes.


7) Si la conexión se ha realizado correctamente, vaya a la sección “Erasing and Programming” y pulse el botón BROWSE.


8) Seleccione el archivo .elf que desea cargar, según el conector al que esté conectado (como se indica en el apartado 1.11).
9) Seleccione la opción “Verify Programming” y pulse el botón START PROGRAMMING.


10) Al finalizar el proceso de programación, pulse OK en las dos ventanas emergentes de confirmación de programación correcta y, a continuación, pulse DISCONNECT.


## 1.11.2 Procedimiento para la programación del firmware mediante smartphone

Para llevar a cabo este procedimiento necesitará:

- un smartphone Android
- la aplicación stmdfuusb, descargable desde el siguiente enlace o desde la Play Store: https://play.google.com/store/apps/details?id=com.yatrim.stmdfuusb&pcampaignid=web_share o una equivalente (al alcanzar el límite de 25 escrituras, bastará con borrar los datos de la aplicación para seguir usándola)
- un cable USB entre el smartphone y el BACCABLE
1) Mantenga pulsado el botón de programación de la placa.
2) Conecte el cable USB OTG al smartphone y, a continuación, conecte el puerto USB del BACCABLE (C1, C2 o BH) al cable OTG.
3) Solo cuando el LED verde del Baccable esté encendido podrá soltar el botón de programación.
4) Abra la aplicación en el smartphone: en la primera conexión, Android solicitará permiso para acceder al dispositivo USB, que debe concederse para continuar.
5) Seleccione, dentro de la aplicación, el archivo .elf que desea cargar, según el puerto USB al que esté conectado (según se indica en el apartado 1.11).
6) Inicie la escritura del firmware desde la aplicación.
7) Espere el mensaje de confirmación de que la escritura ha finalizado y, a continuación, desconecte el cable USB OTG.

Nota1: el procedimiento también se muestra en el siguiente vídeo: https://www.youtube.com/watch?v=NHiYqMTKCWE

Nota2: en cuanto se conecte el baccable al smartphone, la aplicación mostrará una indicación CONNECTED en verde, confirmando que el baccable ha sido detectado en modo de programación. Si esto no ocurre, desconecte el cable y reinicie el procedimiento.

# 2. USO

## 2.1 Primer arranque

Al utilizar el BACCABLE por primera vez, es necesario configurar las funciones que desea activar en su vehículo, de entre las disponibles, siguiendo las instrucciones a continuación:

1. Inserte el BACCABLE en el conector OBD.
2. Arranque el motor.
3. Con el control de crucero desactivado, pulse el botón RES (o el botón DISTANCE) del volante durante unos 2 segundos. La pantalla donde normalmente se muestra el nombre de la emisora de radio mostrará el texto BACCABLE junto con el identificador de la versión instalada.
4. Navegue por el menú circular con los botones de subir y bajar hasta llegar al elemento SETUP MENU.
5. Pulse y suelte inmediatamente el botón RES (o el botón DISTANCE) para entrar en el menú SETUP. Se mostrará el texto SAVE & EXIT.
6. Navegue por el menú circular con los botones de subir y bajar para recorrer la lista de funciones disponibles. El símbolo O a la izquierda indica que la función está desmarcada, mientras que el símbolo Ø indica que la función está seleccionada. Las funciones se describen en este capítulo y sus subcapítulos.

Nota 1: Una excepción es el umbral de RPM del motor para la función shift, detallado en el apartado 2.6, y la selección DIESEL/GASOLINA, detallada en el apartado 2.7.

7. Pulse y suelte inmediatamente el botón RES (o el botón DISTANCE) para seleccionar o deseleccionar la función mostrada.
8. Después de recorrer toda la lista de funciones y activar todas las que desee, volverá al elemento SAVE & EXIT. Pulse y suelte inmediatamente el botón RES (o el botón DISTANCE) del volante para guardar de forma permanente los ajustes seleccionados y volver al menú principal.

Nota 2: Los elementos mostrados en el menú principal dependen de los ajustes realizados dentro del SETUP MENU, al que puede acceder en cualquier momento.

9. Unos 40 segundos después de apagar el motor, el menú se desactivará automáticamente. Para volver a mostrarlo, pulse el botón RES (o el botón DISTANCE) durante unos 2 segundos.
10. En caso de que el vehículo se reinicie, el menú se mostrará de nuevo en la última página visualizada antes del apagado.

ADVERTENCIA: El menú SETUP incluye dos funciones actualmente en desarrollo que no deben activarse: REMOTE START, READ FAULTS y PEDAL BOOSTER

## 2.2 Sniffer

Descripción breve: Actúa como sniffer, conectado a un ordenador personal o a un smartphone Android, es decir, permite registrar los mensajes del bus CAN.

El baccable puede usarse para hacer de sniffer de dos formas diferentes:

- con un firmware dedicado que permite usarlo con SavvyCan en un PC Windows
- activando la función SNIFFER desde el MAIN SETUP MENU del BACCABLE, para hacer sniffer con la aplicación BACCABLE LOGGER desde un smartphone (o desde un PC Windows), con un botón rápido para compartir en línea el registro capturado (en este caso, al desconectar el USB, el baccable vuelve a realizar su función habitual)

## 2.2.1 Sniffer con firmware dedicado SLCAN

Descripción breve: Actúa como sniffer, conectado a un ordenador personal, es decir, permite registrar los mensajes del bus CAN.

Nota: El uso de esta función requiere reprogramar el BACCABLE. No es una función que pueda activarse o desactivarse desde el SETUP MENU.

1. Cada USB corresponde a un bus CAN específico. Leyendo el nombre del BACCABLE en la carcasa, de izquierda a derecha se encuentran los buses BH, C2 y C1.
2. Conecte el cable USB del bus USB deseado al PC (con sistema operativo Windows).
3. Abra SavvyCan (el enlace al proyecto de código abierto Savvycan está disponible en el repositorio de Baccable en GitHub)
4. Desde el menú superior “Connection”, seleccione “Open Connection Window”
5. Desde la ventana “Connection Settings”, pulse el botón “Add new Device Connection”
6. Desde la ventana “New connection”, seleccione la opción “LAWICEL/SLCAN”
7. Desde la ventana “New connection”, seleccione en el menú desplegable serial el puerto COM donde se encontró el Baccable (puede consultar el Administrador de dispositivos para ver qué puerto serie COM virtual está asociado al BACCABLE, identificado como dispositivo ST)
8. Desde la ventana “New connection”, deje la velocidad del puerto serie por defecto (115000bps)
9. Desde la ventana “New connection”, configure la velocidad del bus CAN según la velocidad del bus deseado (500000bps para C1 y C2, o 125000bps para el bus BH)
10. Desde la ventana “New connection”, pulse el botón “create new connection”
11. Cierre la ventana “connection settings”
12. Si las ECU del vehículo se están comunicando, verá los mensajes correspondientes en la ventana principal de Savvycan.
13. En el lado derecho de la ventana es posible detener y borrar la captura; en la parte inferior derecha de la ventana es posible filtrar los mensajes mostrados
14. Desde el menú superior file, puede seleccionar Save Log File o Load Log File para guardar la grabación actual o abrir mensajes grabados previamente.
15. Desde la parte central inferior de la ventana principal puede enviar mensajes al bus CAN (instrucciones detalladas en el repositorio de Savvycan)
16. Desde el menú RE TOOLS puede seleccionar sniffer para acceder a una ventana donde puede analizar los bytes que cambian ante eventos específicos.

## 2.2.2 Sniffer con firmware original y aplicación propia

Descripción breve: Actúa como sniffer, conectado a un ordenador personal o a un smartphone Android, es decir, es posible registrar los mensajes presentes en los buses CAN

Para hacer de sniffer es necesario:

1) conectar un cable USB entre el baccable y el PC, o a un smartphone Android (deberá elegirse el conector USB al que conectarse, según el bus del que se desee obtener datos: C1 conector derecho, C2 conector central, BH conector izquierdo).
2) acceder al MAIN SETUP MENU del BACCABLE, con el vehículo encendido, y seleccionar la función SNIFFER
3) seleccionar SAVE&EXIT para guardar el ajuste

Desde ese momento, el baccable se convertirá en un sniffer, enviando los paquetes al PC (o al smartphone).

En el smartphone o el PC deberá instalarse la aplicación BACCABLE LOGGER, descargada del sitio web www.tr3ma.com/baccable

Nota1: transcurridos 10 segundos desde la desconexión del cable USB, el baccable volverá a ser solo un baccable. Si desea volver a usar la función sniffer, deberá desconectar el baccable del OBD y luego volver a conectar el cable USB y, a continuación, el conector OBD.

Nota2: si no está utilizando el sniffer, recuerde desactivarlo entrando en el main setup menu, para reducir el efecto de posibles interferencias entre la función sniffer y la función inmovilizador durante los primeros segundos de funcionamiento.

El funcionamiento de la aplicación "BACCABLE LOGGER" es muy intuitivo:

- Al conectar, la aplicación se abrirá automáticamente (conceda los permisos solicitados)
- también hay un botón de conexión en la parte superior, aunque normalmente no es necesario usarlo.
- hay un botón en la parte superior para aplicar un filtro a los paquetes
- hay un botón en la parte superior para ver el registro de eventos (errores de conexión o pérdida de paquetes)
- hay un botón para compartir, por Telegram, WhatsApp, correo electrónico, etc., el archivo recién grabado (formato CSV) y el archivo de registro (formato TXT). En la versión para Windows, este botón da acceso a la carpeta donde se guardan todos los archivos.

En caso de pérdida de paquetes, en la parte superior de la ventana aparecerá una indicación roja PACKET LOSS.

Cada vez que se pulsa el botón de conexión, se creará un nuevo archivo recording.CSV y log.TXT.

## 2.3 Desactivador de Start&Stop

Descripción breve: Desactiva el Start&Stop, si el motor está girando y si el Start&Stop no está ya desactivado. Es una función que puede activarse y desactivarse desde el SETUP MENU descrito en el apartado 2.1.

No se requiere ninguna instrucción adicional

## 2.4 Inmovilizador

Descripción breve: Actúa como inmovilizador. Si se detecta una conexión al RFHUB, reinicia la conexión, impidiendo la incorporación de una llave, desactiva el encendido y activa la alarma de pánico (si está activada en el proxy). El inmovilizador puede desactivarse y reactivarse de forma permanente pulsando el botón del control de crucero hacia arriba durante 30 segundos con el motor en marcha y el control de crucero desactivado. El cuadro de instrumentos parpadeará 5-6 veces si el inmovilizador se desactivó correctamente, y 3 veces si se reactivó correctamente.

La función INMOVILIZADOR realiza lo siguiente:

1. Detecta si el ladrón intenta conectarse al RFHUB (lo hacen para añadir una llave al coche)
2. Inicia la alarma de pánico después de un segundo
3. Reinicia continuamente el RFHUB para restablecer la conexión del ladrón, con este mensaje durante 10 segundos
4. tras 10 segundos deja de enviar mensajes y detiene la alarma, y vuelve a la escucha de mensajes del ladrón

La alarma de pánico se activará solo si previamente ha activado la alarma de pánico en su ECU, mediante el procedimiento de alineación del proxy MES.

La función Inmovilizador no detectará al ladrón si alimenta el BACCAble con una tensión disponible solo cuando el panel está encendido. Por lo tanto, si utiliza la función inmovilizador, conéctelo al puerto OBD de 12V, o conecte directamente el canable a la tensión USB de 5V tomada del conector de la interfaz USB en la zona central, cerca del encendedor de cigarrillos. De hecho, la tensión USB se activa en cuanto el ladrón despierta el rfhub.

En cuanto empezamos a enviar el mensaje de reinicio del rfhub, tampoco funcionará el botón de encendido. El coche parecerá muerto.

El inmovilizador está activado por defecto al principio. Para alternar permanentemente el estado, debe estar con el motor en marcha, control de crucero desactivado, punto muerto, y pulsar suavemente el botón de aumento de velocidad del control de crucero durante unos 30 segundos. Si el inmo se desactiva, el brillo del cuadro de instrumentos parpadeará 5-6 veces. Si el inmo se activa, el cuadro parpadeará 3 veces. El cambio persiste después de una pérdida de alimentación. El estado actual del Inmovilizador también se muestra en el menú principal del BACCABLE con el texto “IMMOBILIZER ON” o “IMMOBILIZER OFF”.

Al conectar la alimentación al BACCABLE (o al enchufar el baccable), si el inmovilizador está activado, el LED azul del BACCABLE parpadeará dos veces y el cuadro de instrumentos parpadeará una vez. Esto es útil para saber cómo está configurado el inmovilizador.

Para verificar el correcto funcionamiento del inmovilizador, es posible simular un intento de robo conectándose al RF HUB mediante un ELM327 y la aplicación para smartphone AlfaOBD o la aplicación Multiecuscan en un PC. Al intentar conectarse al RF HUB, ya no será posible el encendido y se activará la ALARMA DE PÁNICO, produciendo un sonido periódico del claxon.

NO SE ALARME: simplemente desconecte el ELM327, espere 30 segundos, y el BACCABLE detendrá la alarma de pánico. En general, recuerde que al arrancar el vehículo, meter una marcha y circular, incluso a velocidades muy bajas, la alarma de pánico se detiene automáticamente por la ECU del vehículo.

## 2.5 Controlador de tira de LEDs

Descripción breve: Controla una tira de LEDs WS281x según la posición del pedal del acelerador (requiere conectar el pin 8 a la tira de LEDs (opcional), mientras que la alimentación de la tira de LEDs debe proceder de una tensión ausente cuando el vehículo está apagado). Cada marcha está asociada a un patrón de color específico de la tira. Los LEDs se iluminan como un vúmetro según la presión del pedal del acelerador. Con el acelerador soltado, solo se iluminan los LEDs centrales. La tira de LEDs se controla asumiendo que el túnel central del coche está rodeado de LEDs. Por lo tanto, la parte central de la tira de LEDs se encuentra en la parte trasera del túnel central.

Nota: Esta es una función que puede activarse y desactivarse desde el SETUP MENU descrito en el apartado 2.1.

1. Conecte el pin 8 al pin de control de la tira de LEDs
2. Conecte el + y el – de la tira de LEDs a la tensión deseada (5V o 12V del coche), asegurándose de que sea una tensión que se corta cuando el coche entra en reposo, para evitar el drenaje de la batería. El número de LEDs de la tira debe corresponder con el número de LEDs configurado en el firmware.

Un ejemplo de tensión disponible solo cuando el coche está encendido, por lo tanto adecuada para la tira de LEDs, es el pin 12 (+12V) y el 1 (GND) del conector relacionado con el Start&Stop y el panel de luces.


Conector relacionado con el Start&Stop y el panel de luces

## 2.6 Shift

Descripción breve: Muestra, en modo race, el indicador de cambio de marcha en el cuadro de instrumentos (solicitud de cambio de marcha) cuando se supera el umbral de RPM del motor definido. El umbral se almacena en el firmware del BACCABLE.

Nota: Esta es una función que puede activarse y desactivarse mediante el SETUP MENU descrito en el apartado 2.1. El umbral de RPM del motor puede modificarse accediendo al menú SETUP como se indica en el apartado 2.1, elemento de menú SHIFT RPM. Cada vez que se pulsa el botón RES (o el botón DISTANCE), el umbral cambia en un menú rotativo.

No se requieren más instrucciones.

Véase también el siguiente apartado (en caso de my23 o posterior) y el apartado 2.10 y sus conexiones (relacionadas con la activación del modo race).

## 2.7 My23 IPC

Descripción breve: Permite, en los cuadros de instrumentos MY23 y versiones posteriores, la correcta visualización de la función SHIFT descrita en el apartado anterior.

Nota: Esta es una función que puede activarse y desactivarse mediante el SETUP MENU descrito en el apartado 2.1

## 2.8 Parámetros en el cuadro

Descripción breve: Muestra parámetros adicionales en el cuadro de instrumentos. Puede activarse con el botón RES del control de crucero (o el botón DISTANCE), si el motor está en marcha y el control de crucero está desactivado. Navegue por el menú con los botones de subida y bajada del control de crucero, y los controles se desactivan cuando el control de crucero está activado

Nota: Desde el SETUP MENU descrito en el apartado 2.1, es posible elegir si configurar los parámetros para un motor de GASOLINA o DIÉSEL.

Procedimiento de uso:

1. Por defecto, el menú del cuadro de instrumentos está desactivado.
2. Para activarlo, el motor debe estar en marcha y el control de crucero debe estar desactivado. Pulse el botón RES (o el botón DISTANCE) del volante durante unos 2 segundos, y el menú mostrará la versión de BACCABLE en la pantalla del cuadro donde normalmente se muestra el nombre de la emisora de radio.
3. Para navegar por el menú rotativo, use los botones de subida y bajada del control de crucero. Al llegar al elemento SHOW PARAMS, pulse y suelte inmediatamente el botón RES (o el botón DISTANCE) del volante para acceder al menú SHOW PARAMS, donde se mostrarán los parámetros.
4. Para recorrer el menú, use los botones de subida y bajada del control de crucero (pulse suavemente para avanzar 1 parámetro, pulse con firmeza para avanzar 10 parámetros) en un menú circular.
5. Cuando el control de crucero está activado, los controles del menú se desactivan, pero el último parámetro seleccionado permanece en pantalla y sigue actualizándose.
6. Los parámetros se actualizan cada 500 milisegundos.
7. Para volver al menú principal, pulse y suelte inmediatamente el botón RES (o el botón DISTANCE) del volante. Se mostrará el elemento SHOW PARAMS del menú principal.
8. Para desactivar el menú, con el control de crucero desactivado, pulse el botón RES (o el botón DISTANCE) durante unos 2 segundos.
9. Al reiniciar el vehículo, aparecerá automáticamente el último parámetro mostrado antes del apagado.

Problemas conocidos: Puede ocurrir raramente que la radio o los dispositivos Bluetooth envíen texto al cuadro de instrumentos de forma que bloqueen temporalmente la cadena de texto generada por BACCABLE. En estos casos, intente desactivar y reactivar el menú con el botón RES (o DISTANCE), o cambie la pantalla del cuadro con el botón de la palanca derecha (TRIP), o realice un ciclo de encendido del vehículo.

Las páginas siguientes muestran los parámetros disponibles para motores de gasolina (primera tabla) y motores diésel (segunda tabla):

PARÁMETROS GASOLINA
PARÁMETRO | Unidad | Descripción
PWR&TORQUE | CV y Nm | Potencia y par motor
Oil Press.%Water T | Bar y °C | Presión de aceite y temperatura del agua
Oil & Water Temp. | °C y °C | Temperatura del aceite y del agua
Bat SoC & Current | % y A | Estado de carga de la batería y corriente en amperios (los valores positivos indican carga, los negativos indican descarga)
POWER | CV | Potencia calculada a partir del par motor y las RPM del motor
TORQUE | Nm | Par motor
IC AIR OUT | °C | Temperatura del aire de salida del intercooler
IC AIR IN | °C | Temperatura del aire de entrada del intercooler
BOOST ABS | BAR | Presión absoluta
BOOST | BAR | Presión del turbo, obtenida a partir de la presión absoluta
TURBO | V | Tensión del sensor del turbo
ODOMETER LAST | km | km desde el último reinicio del cuentakilómetros
OIL | L | Cantidad de aceite
OIL | BAR | Presión de aceite
OIL | °C | Temperatura del aceite
OIL QUALITY | % | Calidad del aceite
OIL UN. AIR | °C | Temperatura del aceite del módulo Multiair
GEARBOX | °C | Temperatura de la caja de cambios
BATTERY | % | Porcentaje de carga de la batería
BATTERY | A | Corriente de carga de la batería (los valores positivos indican carga, los negativos indican descarga)
BATTERY | V | Tensión de la batería
AIR COND. | BAR | Presión del aire acondicionado
CUR. GEAR | - | Marcha actual
T-ON | m | Tiempo desde el encendido del motor
OVER RPM | s | Tiempo en el que el motor estuvo en sobrerrégimen
EXAUST GAS | °C | Temperatura de los gases de escape
CATAL. | °C | Temperatura de la sonda del catalizador
WATER | °C | Temperatura del líquido refrigerante del motor
KNOCK | mV | Picado del motor (knock)
KEY IGN. | - | ID de la llave de contacto
OVER RPM | - | Número de veces que el motor ha superado el régimen máximo
SPARKL.1 | ° | Corrección del cilindro 1
SPARKL.2 | ° | Corrección del cilindro 2
SPARKL.3 | ° | Corrección del cilindro 3
SPARKL.4 | ° | Corrección del cilindro 4
R-DNA | - | Posición del selector R-DNA/DNA
SPEED | km/h | velocidad
Seat Belt Alarm | - | Indica si el aviso acústico del cinturón de seguridad está activado (ON) o no (OFF)
0-100km/h | Seg | Tiempo empleado en acelerar de 0 a 100 km/h. En cuanto el vehículo supera 0 km/h, el estado cambia a GO. Tras un tiempo de espera, si no se alcanza la velocidad requerida, se muestra MISS. Cuando el vehículo supera los 100 km/h, se muestra el tiempo transcurrido en segundos.
100-200km/h | Seg | Tiempo empleado en acelerar de 100 a 200 km/h. En cuanto el vehículo supera 100 km/h, el estado cambia a GO. Tras un tiempo de espera, si no se alcanza la velocidad requerida, se muestra MISS. Cuando el vehículo supera los 200 km/h, se muestra el tiempo transcurrido en segundos.
Best 0-100km/h | Seg | Mejor tiempo en segundos de 0 a 100 km/h, almacenado permanentemente en el baccable
Best 100-200km/h | Seg | Mejor tiempo en segundos de 100 a 200 km/h, almacenado permanentemente en el baccable

PARÁMETROS DIÉSEL
PARÁMETRO | Unidad | Descripción
PWR&TORQUE | CV y Nm | Potencia y par motor
Oil Press.%Water T | Bar y °C | Presión de aceite y temperatura del agua
Oil & Water Temp. | °C y °C | Temperatura del aceite y del agua
Bat SoC & Current | % y A | Estado de carga de la batería y corriente en amperios (los valores positivos indican carga, los negativos indican descarga)
POWER | CV | Potencia calculada a partir del par motor y las RPM del motor
TORQUE | Nm | Par motor
DPF | % | Porcentaje de obstrucción del DPF
DPF | °C | Temperatura del DPF
DPF REGEN. | % | Porcentaje del proceso de regeneración del DPF
LAST REGEN. | km | km desde la última regeneración
TOT REGEN. | - | Número total de regeneraciones
MEAN REGEN. | km | Distancia media entre regeneraciones
MEAN REGEN. | min | Tiempo medio de las regeneraciones
REGEN. | - | Tipo de regeneración en curso
BATT. | V | Tensión de la batería
BATT. | % | Porcentaje de recarga de la batería
BATT. | A | Corriente de carga de la batería (los valores positivos indican carga, los negativos indican descarga)
OIL QUALITY | % | Calidad del aceite
OIL | °C | Temperatura del aceite
OIL | BAR | Presión de aceite
OIL | mm | Nivel de aceite en el cárter en mm (de 50 a 70 mm)
ADBLUE | L | Nivel de ADBLUE en litros
ADBLUE | % | Nivel de ADBLUE en porcentaje
GEARBOX | °C | Temperatura de la caja de cambios
EXAUST GAS | °C | Temperatura de los gases de escape (entrada del turbo)
CUR. GEAR | - | Marcha actual
WATER | °C | Temperatura del agua
EGR CMD | % | Comando de la válvula EGR
EGR | % | Estado de la válvula EGR
TURBO REQ. | BAR | Presión de turbo solicitada
TURBO REQ. | % | Porcentaje de solicitud del turbo
TURBO | °C | Temperatura del turbo
TURBO | BAR | Presión del turbo
TURBO | % | Porcentaje del turbo
BOOST REQ. | BAR | Presión de sobrealimentación solicitada
BOOST | V | Tensión del sensor de sobrealimentación
RAIL | BAR | Presión de riel (rail)
DIESEL | °C | Temperatura del gasóleo
ODOM. LAST | km | km desde el último reinicio del cuentakilómetros
AIR COND. | BAR | Presión del aire acondicionado
FUEL CONS. | L./h | Consumo de gasóleo
DEBIMETER | °C | Temperatura del caudalímetro (debímetro)
SPEED | km/h | Velocidad
Seat Belt Alarm | - | Indica si el aviso acústico del cinturón de seguridad está activado (ON) o no (OFF)
0-100km/h | Seg | Tiempo empleado en acelerar de 0 a 100 km/h. En cuanto el vehículo supera 0 km/h, el estado cambia a GO. Tras un tiempo de espera, si no se alcanza la velocidad requerida, se muestra MISS. Cuando el vehículo supera los 100 km/h, se muestra el tiempo transcurrido en segundos.
100-200km/h | Seg | Tiempo empleado en acelerar de 100 a 200 km/h. En cuanto el vehículo supera 100 km/h, el estado cambia a GO. Tras un tiempo de espera, si no se alcanza la velocidad requerida, se muestra MISS. Cuando el vehículo supera los 200 km/h, se muestra el tiempo transcurrido en segundos.
Best 0-100km/h | Seg | Mejor tiempo en segundos de 0 a 100 km/h, almacenado permanentemente en el baccable
Best 100-200km/h | Seg | Mejor tiempo en segundos de 100 a 200 km/h, almacenado permanentemente en el baccable

Nota: Cada parámetro puede ocultarse o mostrarse desde el PARAMS SETUP MENU.

## 2.9 Route

Descripción breve: Redirige los mensajes internos del bus CAN a los periféricos OBD que solicitan un parámetro específico. Esto permite mostrar en un smartphone parámetros que normalmente no son accesibles usando solo el ELM327.

Nota: Esta es una función que puede activarse y desactivarse mediante el SETUP MENU descrito en el apartado 2.1

Puede redirigir mensajes nativos encapsulándolos en una respuesta de parámetro UDS, para hacerlos disponibles a las solicitudes de diagnóstico realizadas con OBD (puede obtener parámetros normalmente no disponibles en las apps OBD). Esta funcionalidad realiza lo siguiente: al recibir una solicitud UDS con ID de mensaje 0x18DABAF1 con datos de mensaje 0622xzyyyyyyyy, Baccable entenderá lo siguiente:

- 0x18DABAF1 identifica que el mensaje es una solicitud de Route (solicitud de redirigir un mensaje nativo al diagnóstico)
- La redirección se realiza una sola vez (un paquete) para evitar saturar el bus, y solo redirige 5 bytes del mensaje solicitado
- x (primer nibble del tercer byte del mensaje CAN) puede ser 0 (ID estándar) o 1 (ID extendido).
- z (segundo nibble del tercer byte del mensaje CAN) es el desplazamiento del mensaje a redirigir. El número de bytes redirigidos será solo 5. El desplazamiento define la parte del mensaje a redirigir
- yyyyyyyy es el ID de mensaje solicitado alineado a la derecha.

Ejemplo1:

El diagnóstico envía el msgID 0x18DABAF1 con datos 062201000004B2

BACCABLE responde con msgID 0x18DAF1BA con datos 076201AABBCCDDEE donde AA es el segundo byte del mensaje original 0x4b2

Ejemplo2:

El diagnóstico envía el msgID 0x18DABAF1 con datos 062210E10204B2

BACCABLE responde con msgID 0x18DAF1BA con datos 076210AABBCCDDEE donde AA es el primer byte del mensaje original 0xE10204B2

La siguiente imagen resume la funcionalidad de Route:


Secuencia de handshake de los mensajes Route

## 2.10 Selector ESC+TC

Descripción breve: Activa y desactiva, si el modo race se ha activado previamente mediante un procedimiento de alineación del proxy (véase el apartado 2.19), el ESC (Control Electrónico de Estabilidad) y el TC (Control de Tracción). Se activa pulsando el botón de la palanca izquierda (Lane) durante al menos 3 segundos. Al activarse, se mostrarán en el cuadro de instrumentos el indicador “ESC OFF” y el icono de desactivación de la prevención de colisiones, junto con las máscaras race estándar.

Alternativamente, esta función puede activarse o desactivarse desde el menú principal del BACCABLE recorriendo la lista y pulsando RES (o el botón DISTANCE) en el elemento “TOGGLE ESC/TC”, si se ha activado previamente en el SETUP MENU como se describe en el apartado 2.1.

Nota: Esta es una función que puede activarse o desactivarse desde el SETUP MENU, como se detalla en el apartado 2.1.

No se requieren más instrucciones.

## 2.11 DYNO

Descripción breve: Desactiva todos los controles (incluidos ABS, ESC, TC…). Funciona también en Giulia/Stelvio de serie.

Nota: Esta es una función que puede activarse o desactivarse desde el SETUP MENU, como se detalla en el apartado 2.1.

1. La función se activa y desactiva pulsando el botón PARK durante unos segundos.
2. Alternativamente, esta función puede activarse o desactivarse desde el menú principal del BACCABLE recorriendo la lista y pulsando RES (o el botón DISTANCE) en el elemento “TOGGLE DYNO”, si se ha activado previamente en el SETUP MENU como se describe en el apartado 2.1.
3. Una vez activada, se mostrará en el cuadro de instrumentos una secuencia de alertas que indican que la función está activa.
4. Al volver a pulsar el botón PARK, apagar el vehículo o seleccionar “TOGGLE DYNO” en el menú, la función se desactivará y las alertas desaparecerán del cuadro de instrumentos.

Advertencia: Esta función solo debe activarse o desactivarse con el vehículo detenido.

Problemas conocidos: En algunos modelos Giulia/Stelvio, puede ocurrir ocasionalmente que algunas averías permanezcan mostradas en el cuadro de instrumentos tras desactivar la función. En tal caso, realice un ciclo de encendido del vehículo, o seleccione la función CLEAR FAULT descrita en el apartado 2.13.

Nota: Puede recorrer rápidamente las alertas del cuadro de instrumentos pulsando el botón TRIP de la palanca derecha.

## 2.12 ACC Virtual Pad

Descripción breve: Detecta las pulsaciones del teclado del Control de Crucero, sustituyéndolas por las del teclado del Control de Crucero Adaptativo (ACC). Esto elimina la necesidad de comprar el teclado ACC del volante. Depende de realizar una alineación del proxy para activar el ACC y desactivar el CC

Nota: Esta es una función que puede activarse o desactivarse desde el SETUP MENU, como se describe en el apartado 2.1.

Pulsar el botón del Control de Crucero activará o desactivará el Control de Crucero Adaptativo.

Pulsar el botón RES mientras el Control de Crucero Adaptativo está activo cambiará la distancia respecto al vehículo que precede.

Advertencia: Primero debe realizarse una alineación del proxy para activar el Control de Crucero Adaptativo y desactivar el Control de Crucero estándar, de la misma manera que se requiere al sustituir el panel de botones del Control de Crucero estándar por la versión ACC. El vehículo debe, obviamente, estar correctamente equipado (presencia de un radar frontal con firmware ECU compatible y transmisión automática).

## 2.13 BORRAR AVERÍAS

Descripción breve: Borra todos los códigos de error, si están presentes, de todas las ECU del vehículo (en los 3 buses CAN).

Nota: Esta es una función que puede activarse o desactivarse desde el SETUP MENU, como se describe en el apartado 2.1.

Una vez activada esta función, aparecerá la opción CLEAR FAULTS en el menú principal del BACCABLE. Al pulsar y soltar inmediatamente el botón RES (o el botón DISTANCE) se mostrará el mensaje WAIT durante unos segundos. Tras ejecutarse el comando, reaparecerá el mensaje CLEAR FAULTS.

## 2.14 REGENERATION ALERT

Descripción breve: Activa una alerta visual y sonora cada vez que se produce una regeneración del DPF (vehículos DIÉSEL). Por defecto, solo se muestran al usuario ciertos tipos de regeneración. Esta función permite recibir una notificación cada vez, a partir de la fase de post-inyección, que forma parte del proceso de regeneración.

Nota: Esta es una función que puede activarse o desactivarse desde el SETUP MENU, como se describe en el apartado 2.1.

## 2.15 DESACTIVADOR 4WD

Descripción breve: Desactiva la tracción integral. Debe activarse solo en vehículos equipados con esta función.

Nota 1: Esta es una función que puede activarse o desactivarse desde el SETUP MENU, como se describe en el apartado 2.1.

Una vez activada la función a través del menú SETUP, aparecerá una nueva opción “4WD ENABLED” en el menú principal del BACCABLE, indicando la condición por defecto para vehículos AWD. Al pulsar y soltar inmediatamente el botón RES (o el botón DISTANCE) del volante, el menú cambiará para mostrar “4WD DISABLED”.

Nota 2: Esta función solo puede activarse con el vehículo detenido.

## 2.16 ANULACIÓN DE FRENOS

Descripción breve: Activa y desactiva los frenos delanteros mediante el botón RES (o el botón DISTANCE) del volante. Esta función implementa lo que comúnmente se conoce como “launch assist” y “burn out”.

Nota1: Esta es una función que puede activarse o desactivarse desde el SETUP MENU, como se describe en el apartado 2.1.

Una vez activada esta función a través del menú SETUP, aparecerá una opción adicional “Front Brake Normal” en el menú principal del BACCABLE, que indica la condición por defecto.

Nota2: antes de usar esta función, es necesario activar el DYNO para garantizar la máxima entrega de potencia a las ruedas.

## 2.16.1 Launch Assist

Yendo al menú principal del Baccable, en el elemento “Front Brake Normal”, con el motor en marcha, sin el freno de mano puesto y con el pedal de freno soltado, al pulsar y soltar inmediatamente el botón RES (o el botón DISTANCE) del volante, el menú cambiará para mostrar “Front Brake ASSIST” y el freno se activará. Solo se activarán los frenos delanteros.

En este modo, los frenos se soltarán automáticamente al superar el valor de par (en Nm) previamente configurado en el menú setup en el elemento LAUNCH TORQUE.

En cuanto la aceleración empieza a aplicar par a las ruedas, la pantalla mostrará el par actual y el par umbral en una cadena de texto (ejemplo: 15Nm/150Nm, donde 15Nm es el par actual y 150Nm es el par umbral configurado en el menú setup).

Una vez superado el umbral de par configurado, los frenos se sueltan automáticamente y el cuadro de instrumentos muestra el parámetro “Best Time 0-100km/h” (mejor tiempo en segundos para alcanzar 100km/h) en la sección SHOW PARAMS. Para más detalles sobre cómo funciona el parámetro “Best Time 0-100km/h”, consulte el apartado 2.8.

## 2.16.2 Burn Out

Yendo al menú principal del Baccable, en el elemento “Front Brake Normal”, con el motor en marcha, el coche sin el freno de mano puesto y con el pedal de freno soltado, al pulsar y soltar inmediatamente el botón RES (o el botón DISTANCE) del volante, el menú mostrará “Front Brake Assist” y se notará el accionamiento del freno. Solo se activarán las pinzas de las ruedas delanteras. Al pulsar de nuevo el botón RES, el cuadro de instrumentos mostrará el mensaje “Front Brake FORCED”.

En este modo, el freno solo se soltará al pulsar de nuevo el botón RES.

Al pulsar y soltar de nuevo inmediatamente el botón RES (o el botón DISTANCE), el freno se soltará y el menú volverá a mostrar “Front Brake Normal”.

Nota 3: Para un burnout correcto en vehículos 2WD, es obligatorio desactivar primero los controles de estabilidad activando la función DYNO. A continuación, active los frenos delanteros usando la función descrita en este apartado. Tras unos segundos de aceleración y en cuanto aparezca humo en los neumáticos traseros, pulse de nuevo el botón para soltar los frenos delanteros.

Nota 4: Esta función solo puede activarse con el vehículo detenido.

ADVERTENCIA: Se recomienda encarecidamente desactivar la función BRAKES OVERRIDE desde el menú SETUP cuando no se esté utilizando.

ADVERTENCIA: Esta función provoca un estrés considerable en todos los componentes mecánicos implicados, incluidos suspensión, semiejes, embrague y volante motor. Aplique el acelerador con decisión para superar rápidamente la fricción inicial de los neumáticos, que es el punto de mayor estrés mecánico.

## 2.17 REMOTE START

En desarrollo. No active esta función.

## 2.18 LECTURA DE AVERÍAS

Descripción breve: Permite leer los códigos de avería de las centralitas del vehículo (por ahora, solo desde el Body Computer)

La función LECTURA DE AVERÍAS debe activarse primero accediendo al MAIN SETUP MENU, seleccionando la función LECTURA DE AVERÍAS y, a continuación, seleccionando SAVE&EXIT para guardar permanentemente el ajuste. Aparecerá entonces una nueva opción, LECTURA DE AVERÍAS, en el menú principal. Al pulsar el botón RES o DISTANCE (en el volante) tras situarse en la opción LECTURA DE AVERÍAS del menú principal del BACCABLE, aparecerá la indicación WAIT, señalando que es necesario esperar mientras se leen las averías de la centralita del vehículo. Al finalizar la lectura, se accederá automáticamente a un submenú que mostrará las averías detectadas, identificadas por su código de error y el nombre de la centralita a la que pertenecen. Podrá entonces desplazarse por la lista con los botones arriba-abajo del teclado del Cruise Control. Para volver al menú principal, basta con pulsar de nuevo el botón RES o DISTANCE en el volante.

## 2.19 PARPADEO DEL CUENTAKILÓMETROS

2.19PARPADEO DEL CUENTAKILÓMETROS

Descripción breve: Oculta el parpadeo del cuentakilómetros en el cuadro de instrumentos.

Nota: Esta es una función que puede activarse y desactivarse desde el SETUP MENU descrito en el apartado 2.1.

Normalmente, el cuentakilómetros parpadea para indicar una alineación del proxy no completada. Una vez activada esta función, el parpadeo del cuentakilómetros se detendrá.

A continuación se resume una de las aplicaciones de esta función:

Premisa: La alineación del proxy es un procedimiento que se realiza con Multiecuscan, un ELM327 y los cables adecuados, que sincroniza las unidades de control electrónico (ECU) entre sí para que todos los módulos reconozcan la configuración actual del vehículo. Entre estas configuraciones está la activación del modo race, que permite usar la función ESC/TC del BACCABLE sin instalar el selector RDNA. La activación del modo race mediante el procedimiento de alineación se describe bien en el siguiente enlace: https://giuliatech.com/t/how-to-enable-race-mode-on-non-qv-giulia-2017-2024/21

El procedimiento anterior describe los pasos necesarios para la modificación de hardware del vehículo y los correspondientes a la alineación del proxy. La parte relevante para el uso con el Baccable es solo la sección de alineación del proxy.

Activar Race mediante la alineación del proxy provoca la pérdida de los mapas del pedal, es decir, todos los estilos de conducción DNA adoptan el mapa del modo N, que tiene una curva lineal, mientras que Dynamic debería tener una curva de tip-in muy sensible. Para resolver este problema, es posible desactivar Race mediante alineación del proxy solo en la ECU del motor. De esta forma, los mapas del pedal vuelven a su curva correcta y Race sigue disponible. Para lograr este resultado, tras completar con éxito el procedimiento de activación de Race según el enlace de la Premisa, basta con configurar, en la configuración del proxy, el tipo de selector 1 (es decir: desactivar Race), desconectar el ELM327 del vehículo e iniciar el procedimiento de alineación del proxy. La primera ECU que MES intentará escribir es la Body, y al no conseguirlo (ya que el ELM327 estará desconectado), notificará un error. En ese momento, debemos reconectar el ELM327 porque la segunda ECU a escribir será la ECU del motor. En cuanto se notifique la escritura correcta de la ECU del motor, debemos volver a retirar el ELM327, o desconectar el cable USB si se usa un ELM327 USB, para evitar que Multiecuscan escriba las demás ECU. En este punto, al apagar y volver a encender el vehículo, tras un rato el cuentakilómetros empezará a parpadear para indicar una alineación del proxy incompleta, los mapas del pedal funcionarán como estaba previsto originalmente, y la función ESC/TC del BACCABLE funcionará con normalidad. Para eliminar el molesto parpadeo del cuentakilómetros, seleccionaremos la función ODOMETER BLINK en el menú setup del BACCABLE.

## 2.20 ALARMA DE CINTURÓN

Descripción breve: Desactiva el aviso acústico que indica que los cinturones de seguridad no están abrochados.

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

Al deseleccionar esta función en el menú setup, se desactiva el aviso acústico que indica que los cinturones de seguridad no están abrochados. El ajuste es permanente incluso tras retirar el BACCABLE y puede requerir un reinicio para surtir efecto

## 2.21 PEDAL BOOSTER

En desarrollo. No active esta función.

Descripción breve: Pedal booster con mapas personalizados según el estilo de conducción seleccionado.

Premisa: Un pedal booster es un dispositivo electrónico que se conecta entre el pedal del acelerador y la Body (ECU del vehículo) para mejorar la respuesta del vehículo. No aumenta la potencia del motor, pero hace la aceleración más pronta y suave.

Nota: Para usar esta función, se requiere un cable de conexión específico entre el Baccable y el Pedal Booster, disponible por separado.

En el menú setup, la función puede configurarse de la siguiente manera (menú rotativo activado pulsando los botones RES y DISTANCE):

1) Pedal Booster Deselected: la función no controla las señales analógicas del pedal hacia la Body.
2) Pedal Booster Auto: la función asigna diferentes mapas de pedal según el estilo de conducción, amplificando y atenuando adecuadamente las señales analógicas del pedal del acelerador.
3) Pedal Booster Bypass: la función no altera las señales analógicas del pedal del acelerador, simplemente las repite.
4) Pedal Booster A Map: la función fuerza el uso del mapa de pedal asociado al estilo de conducción A (All weather), amplificando y atenuando adecuadamente las señales analógicas del pedal del acelerador.
5) Pedal Booster N Map: la función fuerza el uso del mapa de pedal asociado al estilo de conducción N (Natural), amplificando y atenuando adecuadamente las señales analógicas del pedal del acelerador.
6) Pedal Booster D Map: la función fuerza el uso del mapa de pedal asociado al estilo de conducción D (Dynamic), amplificando y atenuando adecuadamente las señales analógicas del pedal del acelerador.
7) Pedal Booster R Map: la función fuerza el uso del mapa de pedal asociado al estilo de conducción R (Race), amplificando y atenuando adecuadamente las señales analógicas del pedal del acelerador.

## 2.22 MENÚ DE CONFIGURACIÓN PRINCIPAL

Es accesible desde el menú principal y permite activar y desactivar cada función individual del baccable. Véase el apartado 2.1

## 2.23 MENÚ DE CONFIGURACIÓN DE PARÁMETROS

Es accesible desde el menú principal y permite ocultar o mostrar cada parámetro individual del menú SHOW PARAMS. Véase el apartado 2.8

## 2.24 MOSTRAR MÁSCARA RACE

Descripción breve: muestra las pantallas race en el cuadro de instrumentos y en el sistema de infoentretenimiento cuando la función ESC/TC está activa. Véase el apartado 2.10.

ADVERTENCIA: Si se produce parpadeo de las máscaras de la pantalla race en el cuadro de instrumentos o en el sistema de infoentretenimiento de su vehículo, se recomienda desactivar y evitar el uso de la función SHOW RACE MASK.

## 2.25 PARK MIRROR

Descripción breve: Mueve los espejos laterales para mostrar las ruedas traseras cuando se activan la marcha atrás y el intermitente izquierdo o derecho, con el fin de ayudar a aparcar cerca de bordillos.

Nota: Esta función solo funciona en vehículos equipados con encoders en los espejos. Para comprobar la compatibilidad con su vehículo, simplemente pruebe la función.

Procedimiento de uso:

1) Coloque ambos espejos laterales de forma que la zona de la rueda trasera sea claramente visible.
2) Acceda al MAIN SETUP MENU y active la función PARK MIRROR. Si ya está seleccionada, desactívela y vuelva a seleccionarla. En este momento se guardarán las posiciones actuales de los espejos.
3) Seleccione SAVE & EXIT para guardar permanentemente los ajustes y salir del MAIN SETUP MENU. No será necesario repetir estos pasos.
4) Vuelva a colocar los espejos laterales en su posición normal de uso.
5) A partir de ahora, cada vez que se activen la marcha atrás y el intermitente izquierdo, el espejo izquierdo se moverá automáticamente a la posición guardada previamente durante la activación de la función. Al desactivar la marcha atrás, el espejo volverá a su posición normal. La misma lógica se aplica al espejo derecho cuando se activan el intermitente derecho y la marcha atrás.

## 2.26 ACC AUTOSTART

Descripción breve: En vehículos equipados con ACC, cuando el vehículo con ACC activado se detiene detrás del vehículo que lo precede, esta función permite que el ACC permanezca activado, mientras que normalmente el ACC se desactivaría automáticamente unos 5 segundos después de detenerse.

Esta función puede configurarse, en el SETUP MENU, como “ACC AUTOSTART R” o “ACC AUTOSTART +”, según si el vehículo utilizado permite reiniciar pulsando el botón RES o el botón de aumento de velocidad del Control de Crucero. Una vez activada la función, el Baccable garantizará el reinicio automático del vehículo tras una parada ocurrida con el ACC activado.

## 2.27 CERRAR VENTANILLAS

Descripción breve: Permite la activación de los elevalunas eléctricos al cerrar el vehículo, con varias opciones de configuración.

La función CLOSE WINDOWS admite varias opciones, que pueden seleccionarse con el botón RES o DISTANCE tras acceder al elemento CLOSE WINDOWS en el MAIN SETUP MENU:

OPCIÓN | DESCRIPCIÓN
O CLOSE WINDOWS 1 | Close windows desactivado, el vehículo se comportará con normalidad
Ø CLOSE WINDOWS 1 | Close windows 1 seleccionado. Con una sola activación del cierre del vehículo por mando a distancia, se bloquean las puertas del vehículo y se cierran las ventanillas. Con dos activaciones consecutivas del cierre del vehículo por mando a distancia, las ventanillas primero se cierran y luego se vuelven a abrir ligeramente para permitir la circulación del aire.
Ø CLOSE WINDOWS 2 | Close windows 2 seleccionado. Con dos activaciones consecutivas del cierre del vehículo por mando a distancia, se cierran las ventanillas. Con tres activaciones consecutivas del cierre del vehículo por mando a distancia, las ventanillas se cierran y luego se vuelven a abrir ligeramente para permitir la circulación del aire.

## 2.28 ABRIR VENTANILLAS

Descripción breve: Permite la activación de los elevalunas eléctricos al abrir el vehículo, con varias opciones de configuración.

La función OPEN WINDOWS admite varias opciones, que pueden seleccionarse con el botón RES o DISTANCE tras acceder al elemento OPEN WINDOWS en el MAIN SETUP MENU:

OPCIÓN | DESCRIPCIÓN
O OPEN WINDOWS 1 | OPEN windows desactivado, el vehículo se comportará con normalidad
Ø OPEN WINDOWS 1 | OPEN windows 1 seleccionado. Con una sola activación de la apertura del vehículo por mando a distancia, además de desbloquear las puertas del vehículo, las ventanillas se abren por completo.
Ø OPEN WINDOWS 2 | OPEN windows 2 seleccionado. Con una doble activación de la apertura del vehículo por mando a distancia, además de desbloquear las puertas del vehículo, las ventanillas se abren por completo.

## 2.29 HAS VIRTUAL PAD

Descripción breve: Simula la pulsación del botón HAS (Highway Assist System).

La función HAS VIRTUAL PAD permite simular la pulsación del botón HAS haciendo doble clic en el botón LANE (situado en la palanca a la izquierda del volante). Esto elimina la necesidad de comprar el teclado dedicado.

Nota: La función HAS requiere activación mediante alineación del proxy (Byte 166, bit 2, es decir, formato binario xxxxx1xx para activarlo), junto con los siguientes requisitos previos. El vehículo debe ser MY20 o posterior, equipado con una cámara con firmware compatible, volante con sensores táctiles o un bypass para dichos sensores, volante motorizado con firmware A420 compatible, sistema de navegación activado mediante proxy y disponible, Control de Crucero Adaptativo (ACC).

## 2.30 VÁLVULA DE ESCAPE QV

Descripción breve: Esta función abre la válvula de escape de la Giulia Quadrifoglio, pulsando dos veces el botón RELEASE situado en la palanca de cambios (o seleccionando TOGGLE QV VALVE en el menú principal).

## 2.31 SILENCIO APARCAMIENTO FRONTAL

Descripción breve: Silencia temporalmente el aviso acústico si se detecta un obstáculo frontal y el vehículo está detenido (FRONT PARK MUTE).

## 2.32 ELM327

Descripción breve: Convierte el baccable en un ELM327 capaz de conectarse automáticamente a los 3 BUS del vehículo, sin necesidad de cables especiales y sin mover el conector USB del puerto C1.

Para usar la función ELM327 es necesario:

1) conectar un cable USB entre el baccable y el PC, o a un smartphone Android, usando el conector derecho del baccable (C1)
2) acceder al MAIN SETUP MENU del BACCABLE, con el vehículo encendido, y seleccionar la función ELM327
3) seleccionar SAVE&EXIT para guardar el ajuste

Desde ese momento, el baccable se convertirá en un ELM327.

En el smartphone o el PC deberá instalarse la aplicación deseada (por ejemplo, Multiecuscan, alfaobd, etc.)

Nota1: transcurridos 10 segundos desde la desconexión del cable USB, el baccable volverá a ser solo un baccable. Si desea volver a usarlo como ELM327, deberá desconectar el baccable del OBD y luego volver a conectar el cable USB y, a continuación, el conector OBD.

Nota2: si no está utilizando la función ELM327, recuerde desactivarla entrando en el main setup menu, para reducir el efecto de posibles interferencias entre la función ELM327 y la función inmovilizador durante los primeros segundos de funcionamiento.

BACCABLE OBD V.4.6 MANUAL Date: 27/08/2026

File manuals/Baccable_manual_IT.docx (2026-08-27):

OBD BACCABLE

MANUALE

AVVERTENZE: BACCABLE è un progetto sviluppato esclusivamente a scopo didattico e di studio. È severamente vietato utilizzare questo strumento su veicoli in circolazione su strade pubbliche o in qualsiasi contesto che possa causare danni a persone, cose o violare normative vigenti.

L'autore del progetto non si assume alcuna responsabilità per eventuali danni, malfunzionamenti o conseguenze derivanti dall'uso di BACCABLE. L'utilizzo di questo strumento è interamente a rischio dell'utente finale, che si assume ogni responsabilità civile, penale e legale.

Si raccomanda di non impiegare questo progetto in applicazioni reali su veicoli.

L’installazione, se non eseguita attraverso la porta OBD di serie, richiede competenze tecniche specifiche elettriche ed elettroniche nell’ambito automotive per non incorrere in errori che possono determinare rischi per la sicurezza (safety) o danni.

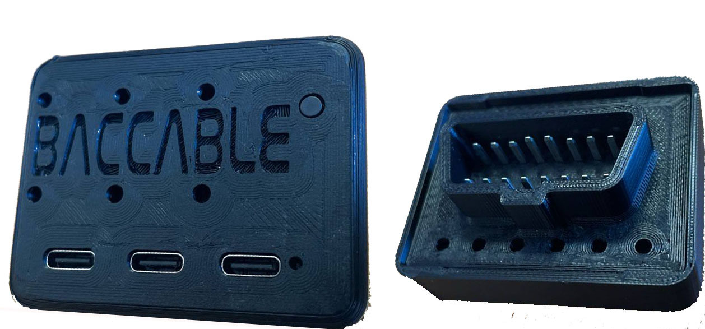
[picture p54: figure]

INDICE

# 1. INSTALLAZIONE

## 1.1 Composizione


Composizione

Il cavo e i “rubacorrente” (innesti rapidi o IDC) mostrati nella foto precedente sono a corredo solo se precedentemente concordato. Il Baccable può essere impiegato connettendolo direttamente alla OBD, se il veicolo non è dotato di SGW o se è dotato di SGW bypass (SGW=Secure Gateway). Non è quindi obbligatorio impiegare cavo e innesti rapidi a corredo.

## 1.2 Pinout

Il Baccable OBD V.3 è dotato di connettore OBD avente il seguente pinout:


Pinout del BACCABLE e pinout del cavo OBD

Il pin 16, corrisponde alla 12Volt della porta OBD del veicolo, ma può, all’occorrenza, essere connesso anche ad una 5Volt, in quanto il BACCABLE supporta una ampia gamma di tensioni in ingresso.

## 1.3 Istruzioni Di Installazione su porta OBD

1) Durante l’inserimento del BACCABLE nella porta OBD del veicolo, fare attenzione a non premere il pulsante di PROGRAMMAZIONE. Se questo accade, sfilate il BACCABLE e reinseritelo.


PROGRAMMAZIONE

Pulsante di PROGRAMMAZIONE

2) Durante il disinserimento del BACCABLE dalla porta OBD del veicolo, non tirate sul contenitore ma piuttosto spingete inserendo la punta delle dita dal lato del connettore OBD verso di voi, per evitare di sollecitare l’incastro che tiene insieme il case (con la scritta BACCABLE) e il lato ove risiede il connettore OBD.

Qualora involontariamente dovesse avvenire il disingaggio dell’incastro, procedete completando la rimozione delle parti (PCB e case) dal connettore OBD, reinserite il pcb nel contenitore con la scritta BACCABLE fino a far corrispondere le parti come mostrato nella foto sopra, poi inserite il lato dotato di connettore OBD fino a toccare il contenitore

ATTENZIONE: il connettore OBD deve avere i due pin piú lunghi in corrispondenza del lato lungo. In caso di errore sfilate il lato dotato di connettore OBD, giratelo e reinseritelo.

Una volta che il lato dotato di connettore OBD è a contatto con il contenitore, tenendo in mano il BACCABLE, premete energicamente alle 4 estremitá assicurandovi che il coperchio entri gradualmente da tutti i lati fino al completo incastro.

## 1.4 Istruzioni di Installazione del Cavo OBD (opzionale)

1) Oltre al cavo, a corredo sono forniti degli IDC (anche chiamati “rubacorrente”). Si tratta di innesti rapidi per spillare il segnale desiderato senza interrompere il filo del cablaggio del veicolo. Gli innesti rapidi doppi sono pensati per i pin H e L, mentre i singoli per l’alimentazione.
2) L’innesto rapido è capace di crimpare una vasta gamma di sezioni di filo, tuttavia questa versatilità rende l’innesto “doppio” più complicato da impiegare. Per fissare i fili dell’innesto “singolo” su can bus, è sufficiente serrarlo con forza con delle pinze, e poi richiudere la linguetta di protezione. Qualora siano stati forniti gli innesti rapidi “doppi”, mediante un piccolo cacciavite a taglio spingere il filo all’interno della ghigliottina, facendolo compenetrare in essa, e solo successivamente procedere alla chiusura del coperchio incernierato. Se questa operazione preliminare è stata eseguita correttamente, chiudendo lo sportellino dell’innesto “doppio” con forza, questo dovrà aggrappare le mollette di chiusura e risultare perfettamente serrato, senza spazi tra sportellino trasparente e base nera. L’innesto rapido “singolo” colore rosso invece, può essere serrato con una pinza, pertanto non dovrebbe richiedere operazioni preliminari. Al termine del serraggio verificare sempre la solidità della connessione.

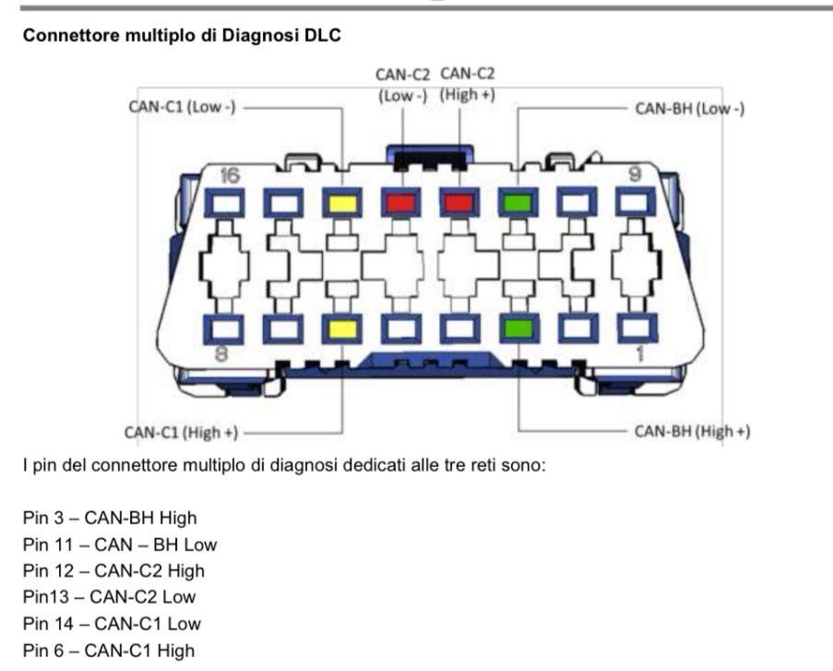
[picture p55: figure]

La immagine seguente mostra il nome del segnale presente sui pin del connettore diagnostico OBD (il connettore in figura è visto lato pin esterni e non lato filo). I pin 4 e 5 sono la massa (GND) e il pin 16 è la 12 Volt.

## 1.5 Prima Accensione (con cablaggio aggiuntivo)

Alla prima accensione eseguire le seguenti verifiche preliminari:

1) Verificare che le connessioni siano realizzate in accordo allo schema e ai requisiti definiti nel presente documento.
2) Verificare, con quadro acceso che sia presente illuminazione (led verde) all’interno del contenitore del BACCABLE, a conferma della corretta ricezione della tensione di alimentazione.
3) Se il quadro non si accende o se compaiono errori randomici su cruscotto, verificare che non siano stati invertiti i pin H e L, o che uno dei due sia stato connesso per errore a un altro filo.
4) Verificare che il led blu interno lampeggi due volte all’avvio, a indicare la corretta attivazione della funzione Immobilizer attiva di default (senza perfetto allineamento tra occhio e led non è possibile vederlo, quindi possono essere richieste più accensioni per questa verifica)
5) Appena viene inserito il BACACBLE, se il quadro del veicolo è già acceso, il cruscotto deve lampeggiare una volta a indicare che l’immobilizer è attivo (di default abilitato). Se questo non avviene, verificare le connessioni verso il can bus.

## 1.6 Prima Accensione (inserimento su porta OBD di serie)

Al primo utilizzo è necessario definire le funzioni che si desidera impiegare sul proprio veicolo, accedendo al menu SETUP

Le istruzioni per accedere al menu SETUP, scorrere la lista delle funzioni disponibili, abilitare/disabilitare le funzioni e salvare permanentemente le impostazioni, sono riportate su para. 2.1.

## 1.7 Note Sulle connessioni verso la 5 Volt (opzionale)

Se si opta per la alimentazione del baccable dalla 5 Volt, è possibile collegarsi ad esempio all’USB HUB posto nel vano porta oggetti della plancia centrale, accanto al freno a mano. Tale tensione ha la caratteristica di essere attivata appena si entra in auto ma anche quando ci si connette all’RF HUB come un ladro. Per raggiungere tale tensione potete seguire le seguenti indicazioni:

1) estrarre e disconnettere l’HUB USB dal veicolo,
2) allargare le 4 linguette sul coperchio posteriore impiegando più cacciaviti piccoli e pinzette ed estrarre il circuito stampato.
3) Praticare un foro nella plastica posteriore nello spazio non occupato dai connettori, per permettere il passaggio del filo indicato in figura (cercate di fare un foro preciso per non farlo scorrere troppo lasco; se necessario, al termine applicate una goccia di silicone internamente per dare resistenza in caso di strattonamento del filo)
4) Saldare il filo su circuito stampato dell’USB HUB, in corrispondenza del pin +5V del connettore USB. Potete aiutarvi con le seguenti immagini di riferimento, per individuare il pin corretto da impiegare.


## 1.8 Note Sulle connessioni verso il can bus

Se il veicolo è dotato di SGW (secure gateway), i pin su porta OBD non potranno essere impiegati per collegare il BACCABLE e sarà invece necessario dotarsi di un cablaggio SGW bypass acquistabile online, che renda disponibile una OBD su cui intestarsi col BACCABLE, oppure intercettare i fili del CAN bus desiderato in altri punti del veicolo, a monte del SGW.

## 1.9 ESEMPI DI CONNESSIONE

Esempio1 di punto a monte del SGW dove rilevare il bus C1:

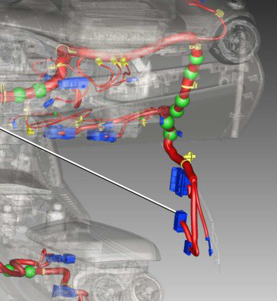
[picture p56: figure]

Esempio2 di punto a monte del SGW dove rilevare il bus C1:


Esempio3 di punto a monte del SGW:

Nel caso in cui si disponga di cambio automatico, è possibile impiegare il seguente estratto del manuale, col pinout del connettore del cambio:


Esempio4 di punto a monte del SGW:

Sul body, posizionato ai piedi del posto passeggero, ci sono tutti i bus e l’alimentazione.


Can Bus e alimentazione sul Body Computer

La seguente immagina mostra il layout dei principali connettori del Body:


Connettore C4 del Body Connettore C8 del Body

## 1.10 CARATTERISTICHE TECNICHE

Dimensione: 57,5mm (larghezza) x 44,5mm (altezza) x 22mm (profonditá)

Peso: inferiore ai 50grammi

Tensione di alimentazione: 4,5V -:- 35V (tensione continua)

Consumo di corrente@12V: circa 15mAh a veicolo spento in sleep. Meno di 30mA durante l’uso con veicolo acceso.

## 1.11 AGGIORNAMENTO FIRMWARE

Il BACCABLE viene consegnato programmato con l’ultima release firmware disponibile, tuttavia è possibile usufruire di successivi aggiornamenti firmware mediante procedura di aggiornamento Firmware

Per iniziare, accedere, dal PC o da smartphone android, al sito https://github.com/gaucho1978/BACCAble/releases/ e scaricare l’ultima versione STABLE disponibile per il BACCABLE.

Tasto di programmazione

Connettore USB Bus C1

Connettore USB Bus C2

Connettore USB Bus BH

Connettori e pulsante impiegati durante la programmazione

I files da impiegare sono:

- baccableBH_stable.elf (da caricare connessi al connettore USB BH)
- baccableC1diesel_stable.elf (da caricare connessi al connettore USB C1)
- baccableC2_stable.elf (da caricare connessi al connettore USB C2)

Eseguire, su tutti e 3 i connettori usb, la seguente procedura per il caricamento firmware, caricando su ogni porta usb il firmware previsto (baccableC1diesel_stable.elf su usb C1, baccableC2_stable.elf su usb C2, baccableBH_stable.elf su usb BH).

Sono di seguito descritte 2 procedure, una per il caricamento del firmware attraverso un PC windows, e l’altra per il caricamento del firmware attraverso uno smartphone android.

## 1.11.1 Procedura per il caricamento firmware da PC

Per eseguire questa procedura occorre:

- un pc con sistema operativo microsoft windows e porta USB
- Il software STM Cube Programmer per PC windows, che può essere scaricato dal sito ST, previa registrazione gratuita, impiegando il seguente link: https://www.st.com/en/development-tools/stm32cubeprog.html
- un cavetto usb per la connessione del pc al baccable
1) Premere e tenere premuto il pulsante di programmazione sulla scheda
2) Collegare la USB (C1, C2, BH) al PC - La scheda verrà rilevata dal PC come dispositivo seriale con il nome "STM32 Bootloader".
3) Solo quando il LED verde è acceso, è possibile rilasciare il tasto di programmazione.

Nota1: se il led verde del BACCABLE emette una luce tremula e debole, impiegare un cavo USB più corto, o sostituire il cavo USB

Nota2: in caso di mancato rilevamento sul PC, verificare di aver premuto correttamente il tasto di programmazione prima di aver collegato il cavo USB, e mantenere la pressione fino a completo inserimento del connettore USB ambo i lati. Se il problema persiste ruotare di 180 gradi il connettore USB-C lato baccable e riprovare.

4) Aprire il software STM32CubeProgrammer, selezionare USB dal menu a tendina (sul lato destro della finestra), poi premere il tasto CONNECT.


5) Se sul campo PORT viene mostrato NO DFU come nella figura seguente, significa che il dispositivo non è stato rilevato, ed è necessario ricominciare la presente procedura, o premere il tasto AGGIORNA mostrato nella seguente figura.


Dispositivo Non rilevato Dispositivo correttamente rilevato

6) Se alla pressione del tasto CONNECT viene mostrato l’errore “device is under read out protection”, come mostrato nella figura seguente, è probabile vi sia una incompatibilità tra il chipset della porta USB del PC e il chip impiegato nel Baccable. Per superare questo errore è possibile ripetere la procedura con le altre porte usb del pc, oppure impiegare un altro PC, oppure impiegare un Hub USB (possibilmente lento, non di ultima generazione) tra Baccable e PC. Quest’ultimo metodo è l’ideale sui PC di nuova generazione.


7) Se la connessione ha avuto successo, spostarsi nella sezione "Erasing and Programming", poi premere il tasto BROWSE.


8) Selezionare il file .elf che si desidera caricare, in base al connettore al quale si è connessi (come da indicazioni su para. 1.11).
9) Selezionare l’opzione "Verify Programming" e premere il tasto START PROGRAMMING.


10) Al termine della programmazione premere il tasto OK sui due popup di conferma inerente la corretta programmazione, poi premi DISCONNECT.


## 1.11.2 Procedura per il caricamento firmware da smartphone

Per eseguire questa procedura occorre:

- Uno smartphone android
- L’applicazione stmdfuusb scaricabile dal seguente link o del play store: https://play.google.com/store/apps/details?id=com.yatrim.stmdfuusb&pcampaignid=web_share o equivalente (raggiunto il limite di 25 scritture sarà sufficiente cancellare i dati APP per continuare ad impiegarlo)
- un cavo USB tra smartphone e baccable
1) Premere e tenere premuto il pulsante di programmazione sulla scheda.
2) Collegare il cavo USB OTG allo smartphone, quindi collegare la USB (C1, C2 o BH) del BACCABLE al cavo OTG.
3) Solo quando il LED verde sul Baccable è acceso, è possibile rilasciare il tasto di programmazione.
4) Aprire l’app sullo smartphone: al primo collegamento Android richiederà il permesso di accesso al dispositivo USB, che deve essere concesso per proseguire.
5) Selezionare, all’interno dell’app, il file .elf che si desidera caricare, in base alla porta USB alla quale si è connessi (come da indicazioni su para. 1.11).
6) Avviare la scrittura del firmware dall’app.
7) Attendere il messaggio di conferma del completamento della scrittura, quindi scollegare il cavo USB OTG.

Nota1: la procedura è mostrata anche nel seguente video: https://www.youtube.com/watch?v=NHiYqMTKCWE

Nota2: appena connesso il baccable allo smartphone, sulla app sarà visibile una indicazione CONNECTED verde per indicare che il baccable è stato rilevato in modalità di programmazione. Se questo non avviene, scollegare il cavo e ricominciare la procedura.

# 2. USO

## 2.1 Prima Accensione

Al primo utilizzo del BACCABLE è necessario impostare le funzioni che si desidera utilizzare sul proprio veicolo, tra quelle rese disponibili, seguendo le seguenti istruzioni:

1. Inserire il BACCABLE nel connettore OBD
2. Accendere il motore
3. Col cruise control disabilitato, premere tasto RES (o tasto DISTANCE) su volante per circa 2 secondi. Sulla stringa ove tipicamente è mostrato il nome della stazione radio, sará visualizzata la scritta BACCABLE e l’identificativo della versione installata.
4. Muoversi sul menu a scorrimento circolare impiegando i tasti su e giú, fino a raggiungere la voce SETUP MENU.
5. Premere il tasto RES (o tasto DISTANCE) e rilasciarlo immediatamente per accedere al menu SETUP. Sarà visualizzata la scritta SAVE & EXIT.
6. Muoversi sul menu a scorrimento circolare impiegando i tasti su e giù, lungo la lista delle funzioni disponibili. Il simbolo a sinistra O indica che la funzione è deselezionata, mentre il simbolo a sinistra Ø indica che la funzione è selezionata. Le funzioni sono descritte nel presente capitolo e suoi sottocapitoli.

Nota1: Fa eccezione la soglia di giri motore della funzione shift, per la quale si rimanda al para.2.6, e la selezione DIESEL/GASOLINE per il quale si rimanda al para.2.7.

7. Premere e rilasciare immediatamente il tasto RES (o tasto DISTANCE) per selezionare e deselezionare la funzione visualizzata.
8. Dopo aver scorso tutta la lista delle funzioni, e abilitato tutte le funzioni desiderate, ci si ritroverà nuovamente sulla voce SAVE&EXIT. Premere e rilasciare immediatamente il tasto RES (o tasto DISTANCE) sul volante, per salvare permanentemente le impostazioni eseguite e ritornare al menu principale.

Nota2: le voci visualizzate sul menu principale dipendono dalle impostazioni eseguite all’interno del SETUP MENU, al quale si potrà accedere ogni volta che lo si desidera.

9. Dopo circa 40 secondi dallo spegnimento del motore, il menu verrà automaticamente disabilitato e per visualizzarlo nuovamente occorrerà premere il tasto RES (o tasto DISTANCE) per circa 2 secondi.
10. In caso di riaccensione veicolo, il menu sarà nuovamente visualizzato sull’ultima pagina visualizzata prima dello spegnimento del veicolo.

ATTENZIONE: sul SETUP menu sono presenti due funzioni in fase di sviluppo che si raccomanda di non abilitare: REMOTE START, READ FAULTS e PEDAL BOOSTER.

## 2.2 Sniffer

Breve Descrizione: Agisce come uno sniffer, connesso a un Personal Computer o uno smartphone android, ovvero permette di registrare i messaggi can bus.

E’ possibile usare il baccable per sniffare in due diversi modi:

- con un firmware dedicato che permetterà di usarlo con savvycan sul pc windows
- abilitando la funzione SNIFFER da MAIN SETUP MENU del Baccable, per sniffare con una app BACCABLE LOGGER da smartphone (o da pc windows), con tasto rapido per la condivisione online della sniffata (in questo caso il baccable torna a fare il suo lavoro scollegando la usb)

## 2.2.1 Sniffer con Firmware dedicato SLCAN

Breve Descrizione: Agisce come uno sniffer, connesso a un Personal Computer, ovvero permette di registrare i messaggi can bus.

Nota: L’impiego di questa funzione richiede la riprogrammazione del BACCABLE. Non si tratta di una funzione abilitabile e disabilitabile da SETUP MENU.

1. Ogni USB corrisponde a un bus CAN specifico. Leggendo il nome Baccable sul contenitore, da sinistra a destra hai i bus BH, C2 e C1.
2. Collega il cavo USB dal bus desiderato al PC (con sistema operativo Windows).
3. Apri SavvyCan (il link al progetto open-source SavvyCan è disponibile nel repository Baccable su GitHub).
4. Dal menu superiore "Connection", seleziona "Open Connection Window".
5. Nella finestra "Connection Settings", premi il pulsante "Add new Device Connection".
6. Nella finestra "New Connection", seleziona l'opzione "LAWICEL/SLCAN".
7. Nella finestra "New Connection", seleziona dal menu a tendina la COM port a cui è stato associato il Baccable (puoi controllare su “Gestione dispositivi” di windows per vedere quale porta COM virtuale è associata al Baccable, rilevato come dispositivo ST).
8. Nella finestra "New Connection", lascia la velocità della porta seriale al valore predefinito (115000bps).
9. Nella finestra "New Connection", imposta la velocità del bus CAN in base al bus desiderato (500000bps per C1 e C2, oppure 125000bps per il bus BH).
10. Nella finestra "New Connection", premi il pulsante "Create new connection".
11. Chiudi la finestra "Connection Settings".
12. Se le ECU del veicolo stanno comunicando, vedrai i relativi messaggi nella finestra principale di SavvyCan.
13. Sul lato destro della finestra è possibile fermare e cancellare la cattura, mentre nella parte inferiore destra è possibile filtrare i messaggi visualizzati.
14. Dal menu superiore "File", puoi selezionare "Save Log File" o "Load Log File" per salvare la registrazione corrente o aprire messaggi registrati in precedenza.
15. Nella parte inferiore centrale della finestra principale puoi inviare messaggi al bus CAN (istruzioni dettagliate nel repository SavvyCan).
16. Dal menu "RE TOOLS" puoi selezionare "Sniffer" per accedere a una finestra in cui analizzare le variazioni dei byte in base a eventi specifici.

## 2.2.2 Sniffer con Firmware originale e app proprietaria

Breve Descrizione: Agisce come uno sniffer, connesso a un Personal Computer o uno smartphone android, ovvero è possibile registrare i messaggi presenti sui can bus

Per sniffare è necessario:

1) collegare cavetto usb tra baccable e PC oppure a uno smartphone android (andrà scelto il connettore usb al quale connettersi, sulla base del bus dal quale si desidera sniffare (C1 connettore a destra, C2 connettore centrale, BH connettore di sinistra).
2) accedere al MAIN SETUP MENU del BACCABLE, con veicolo acceso, e selezionare la funzione SNIFFER
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

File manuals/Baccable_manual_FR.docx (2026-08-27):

OBD BACCABLE

MANUEL

AVERTISSEMENT : BACCABLE est un projet développé exclusivement à des fins éducatives et de recherche. L'utilisation de cet outil sur les véhicules circulant sur les routes publiques ou dans tout contexte pouvant causer des dommages aux personnes, aux biens ou enfreindre les réglementations applicables est strictement interdite.

L'auteur de ce projet n'assume aucune responsabilité pour les dommages, dysfonctionnements ou conséquences résultant de l'utilisation de BACCABLE. L'utilisateur final porte l'entière responsabilité civile, pénale et légale de son utilisation.

Il est fortement recommandé de ne pas utiliser ce projet dans des applications réelles de véhicules.

L'installation dans un lieu caché nécessite des compétences techniques spécifiques en systèmes électriques et électroniques automobiles afin d'éviter des erreurs susceptibles de présenter des risques pour la sécurité.


INDEX

# 1. INSTALLATION
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

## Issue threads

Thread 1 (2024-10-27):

Immobiliser - chec for the dat

tombartosz, 2024-10-27:
Hi, I found out this project and also found out your message:
https://www.giuliaforums.com/threads/how-to-anti-theft-can-bus-device.63034/

“…Basically any diagnostic session with the RFHUB or other control module starts with the 10 03 command sent to the address of the module, the RFHUB has the address 0xC7. So the command looks like 18 DA C7 F1 02 10 03 . Your tool can monitor the bus for the command and start sending 18 DA C7 F1 02 11 01 – the reset module command. The expected reply from the RFH would be 18 DA F1 C7 01 51 , so your tool can monitor the bus for the reply and immediately send another reset command. This most probably will result in AlfaOBD not able to proceed.”

I can not find in code, where you check that 10 03 command.
I found only this line (main.c:197) :
if ((rx_msg_header.ExtId==0x18DAC7F1) ||( (rx_msg_header.ExtId==0x18DAF1C7) && (floodTheBusStartTime==0)) ){

I belive, you start panic alarm if received message to RFHub (0x18DAC7F1) or from RFHub (0x18DAF1C7) .
Is it not making false alarms when other modules communicates to and from RFHub ?

gaucho1978, 2024-10-28:
Hi. Thank you for the question. I found that no one connects to rfhub, therefore the solution works fine. I'm using it since 3 months. Everything starts from the fact that i decided to power BACCABLE by usb, in order to avoid to drain battery. The usb is on when you enter the car and when the thief connects to rfhub. This means that I will miss the first thief message, but I'm for sure able to intercept the reply from the rfhub.

tombartosz, 2024-10-28:
Can you share me your email?

Closed 2024-10-29.

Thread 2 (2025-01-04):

More information

temuccio, 2025-01-04:
Hi,
I came across your project and find it very interesting! I would like to try it on a Stelvio My2020. The immobilizer functionality caught my attention—could it be used as an anti-theft system?

Additionally, I’m curious if it’s possible to retrieve data about the DPF regeneration process.

I’m a contributor to Home Assistant, and I think it would be great to integrate this system with a CAN-interfacing board to display data on Android Auto. It could be a very interesting application for the community!

Looking forward to your thoughts.

Best regards,
@temuccio

gaucho1978, 2025-01-04:
Yes, it can be used as anti theft system. I'm testing the ability to print text on the dashboard. Next step will be the ability to print additional parameters on dashboard. If possible, dpf occlusion will be one of them

Closed 2025-02-09.

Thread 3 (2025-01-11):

info

AlessioM89, 2025-01-11:
Ciao, ho visto tutti i video presenti sul tuo canale yt....che dire complimenti....ti scrivo quì per chiederti alcune info prima di replicare il tuo fantastico progetto:

1) è compatibile anche con le versioni di giulia 2,2 diesel con cambio automatico?

2) io per poter disabilitare i controlli ho installato il manettino race della giulia quadrifoglio, con la conseguente e nota perdita delle mappe pedale, cosa che mi è dispiaciuta molto inquanto credo che siano il vero carattere distintivo della dinamica della vettura, (specialmente in D era davvero divertente grazie alla risposta immediata del pedale) ; se affronterò il tuo progetto tale manettino diventerebbe inutile e rimonterei il manettino classico come il tuo in modo da riavere le mappe pedale funzionanti...scusa il dilungamento, ma fondamentalmente la domanda è : tramite il tuo sistema si perdono le mappe pedale nelle varie modalità di guida?

Ti ringrazio davvero tanto per il lavoro e lo studio che hai svolto e per averlo reso disponibile a tutti.

gaucho1978, 2025-01-12:
1. Si
2. Si, perché devi comunque attivare la modalità race su proxy affinché funzioni la disabilitazione di ESC.

Closed 2025-02-09.

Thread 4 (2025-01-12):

Suggestions for dashboard menu

ClaudeMarais, 2025-01-12:
Hi,

Thanks for this fantastic project. I have a few suggestions of what text you can show in the dashboard menus.

1) Show current turbo boost psi, just like a boost gauge

float turboBoostPsi = _max(0.0f, float(g_BoostPressure - g_AtmosphericPressure)) * 0.0145038f;

2) Show maximum boost pressure during the trip, together with at what engine rpm and gear that happened

"23psi at 5555rpm in D2"

3) 0-60 mph speed. Ford Mustangs have this menu and it seems like something easy to do.
    - In this mode, try to read the car speed as frequently as possible
    - Detect when car starts moving after a complete stand still
    - Detect when car reaches 60mph (or slows down before that)
    - It's most likely that the reading won't be exactly at 0mph and exactly at 60mph, so you can easily interpolate between the reading right before 60mph and right after 60mph to get to exactly when 60mph happened

4) Show engine oil temp together with if a Squadra Tune is fully active. From documentation it looks like a Sqaudra Tune is only fully active when the engine oil reaches 70 Celsius, and without this you never really know if the tune is fully active

gaucho1978, 2025-01-13:
Interesting but I can print just a string, not a gauge. What I'm doing now is to print around 40 additional parameters. Your suggested functions are interesting but I don't know how many users are interested in this.

FizzGiGG, 2025-03-06:
Coolant and oil temps would be a win. The other stuff? Eh, that's fine.

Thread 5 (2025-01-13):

MY 2023

tomsa64, 2025-01-13:
Hi, very good Job. But wondering od it works on all Giulias, Even the MY 2023 and newer?

Has anyone testet?

regards Tomsa

gaucho1978, 2025-01-13:
I don't know. If you want i can sell one to you to test it, and in case of problems I can give you back the money

mikecitt, 2025-02-06:
@gaucho1978 How much is it? I have MY2020 and would like to have ESC disabler on stalk.

gaucho1978, 2025-02-09:
Contact me on telegram @gaucholivido

gaucho1978, 2025-02-09:
One user is using on my23

Closed 2025-02-09.

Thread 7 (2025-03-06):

Gearbox blocking

apawlos, 2025-03-06:
Hi,

Thank you for publishing your repository! It looks great, but I suggest splitting the code into multiple files, as it seems a bit difficult to read. :)

I'm also working on my own project for my Giulia and have taken some information from your repository.

If you need any reverse engineering data, feel free to ask me - maybe I can help.

Here’s some code to set the parking gear on our AT. I use it with a PIN code (a specific button sequence). It’s possible to change gears, but if no PIN code is detected, immediately sets the parking gear.

```void AR_Giulia_Set_Parking_Gear(uint8_t ThirdByte)
{
	uint8_t i;
	uint8_t Data[8];
	Data[0] = 0x42;
	Data[1] = 0x00;
	Data[2] = 0x00;
	Data[3] = ThirdByte + 0x01; // actual counter from last received 0x192 frame
	for (i = 5; i < 8; i++)
	{
		Data[i] = 0x00;
	}
	Data[4] = 0x25; // calculate_crc8(Data); // should be CRC but alfa does not care :)
	if (KernelCan_GetCarSpeed() < 1) // additional safety check
		CAN2_TransmitACK(0, 0x192, Data, 5, 50); // sending only 5 first bytes - last 3 are not nessesary
}

```

I use it with some restrictions:
`	if (!(blocking_needed) || parking_engadged || (KernelCan_GetCarSpeed() > 1))
	{
		return;
	}`

Greetings

Gianfranco1090rr, 2025-03-06:
👍

gaucho1978, 2025-03-06:
yes it's becoming too long and complicated to read the main.c.

Your idea seems to be good.

Do You do it in addition to rfhub protection?  or as the unique protection?

I use buttons on cruise control for a lot of other functions, so i should study it, if I want to allow both current functions and a unlock buttons sequence.

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

apawlos, 2025-03-07:
I use it as separate protection. It works even if someone steals your key fob.
You can use it with other buttons then steering wheel. Gear knob button, a lot of HVAC buttons (if u are connected to low speed CAN as well), accelerator pedal kick down button, or even brake force value.

danardi78, 2025-03-07:
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

That's how Mosquito works! Look great

gaucho1978, 2025-03-18:
Do you have American key? I'm tring to switch on the car or at least the dashboard. If you have success feel free to share it

apawlos, 2025-04-08:
I have only frame to start the engine without brake pressed, but only if ignition is on:
ID: 0x1EF byte 0: 0x82, other bytes: 0x00
and frame to turn off a ignition (but probably not when the engine is on):
ID: 0x1EF byte 0: 0x80, other bytes: 0x00

say hello, but only if ignition is on:
ID: 0x1EF byte 0: 0x02, other bytes: 0x00

as you can see, 0x1EF on that CAN seems pretty interesting

apawlos, 2025-04-08:
that frame you can use for panic alarm maybe:
ID: 0x1EF bytes: 0x42 0x06 0x16 0x00 0x00 0x00 0x00 0x68 (last 0x68 can be probably 0 as well)
quick horn and hazard lights

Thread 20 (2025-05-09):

Parking sensors blocking

netzmark, 2025-05-09:
Hi,

Great idea and great job, congrats!

Have you ever considered, in addition to disabling S/S, adding the functionality of blocking the front parking sensors when the car is not moving? Similiar job just other switch on the same module.

For me at least, it is annoying that this alarm sometimes goes on for a moment for no reason after a few seconds of standing behind someone at the crossroad, despite maintaining a really reasonable distance. Not immediately, but after a few seconds. And again...

Another feature that I think would be cool is longer muting the speakers when reversing. Original turning down is too short and when you are listening the music pretty loud it gives terrible effect when the volume changes dynamically from min to max.

regards!

gaucho1978, 2025-05-10:
My car don't have that functions. Can you share a video of these problems by Telegram?

netzmark, 2025-05-12:
What fuction do you mean? Don't you have front parking sensors or your audio doesn't decrease the music volume when the back sensors detect some obstacle?
When the front radar detects some car before you - the display goes black and you get a message there "check surroundings". It disapears after several secunds. And after next several secunds you get it again, and so so. Problem gets off when you move back half metre. And I don't mean situation that my car stands 2cm after the next one. AFAIK it is also not the problem of the radar tuning. So, disabling front park sensors when the speed is 0 would solve the problem (with side effect that the car will not detect someone reversing straight onto you).
While the reversing, when the park sensors will detect an obstacle, my audio system (so called MID type system, not the base) decreases the music to the level around 2-3. To you could reasonably hear their beeping. But when you are in the reverse moving the sensors sometimes detects something and "undetect" then detect again. When "undetect" the music at once goes back to the level you set before, let it be i.e. 20. So while the reversing action it happens that speakers break you ears when "jumps" from 2 to 20 and back several times... Mute-on-reverse would eliminate it.

gaucho1978, 2025-08-17:
I don't have front parking sensors

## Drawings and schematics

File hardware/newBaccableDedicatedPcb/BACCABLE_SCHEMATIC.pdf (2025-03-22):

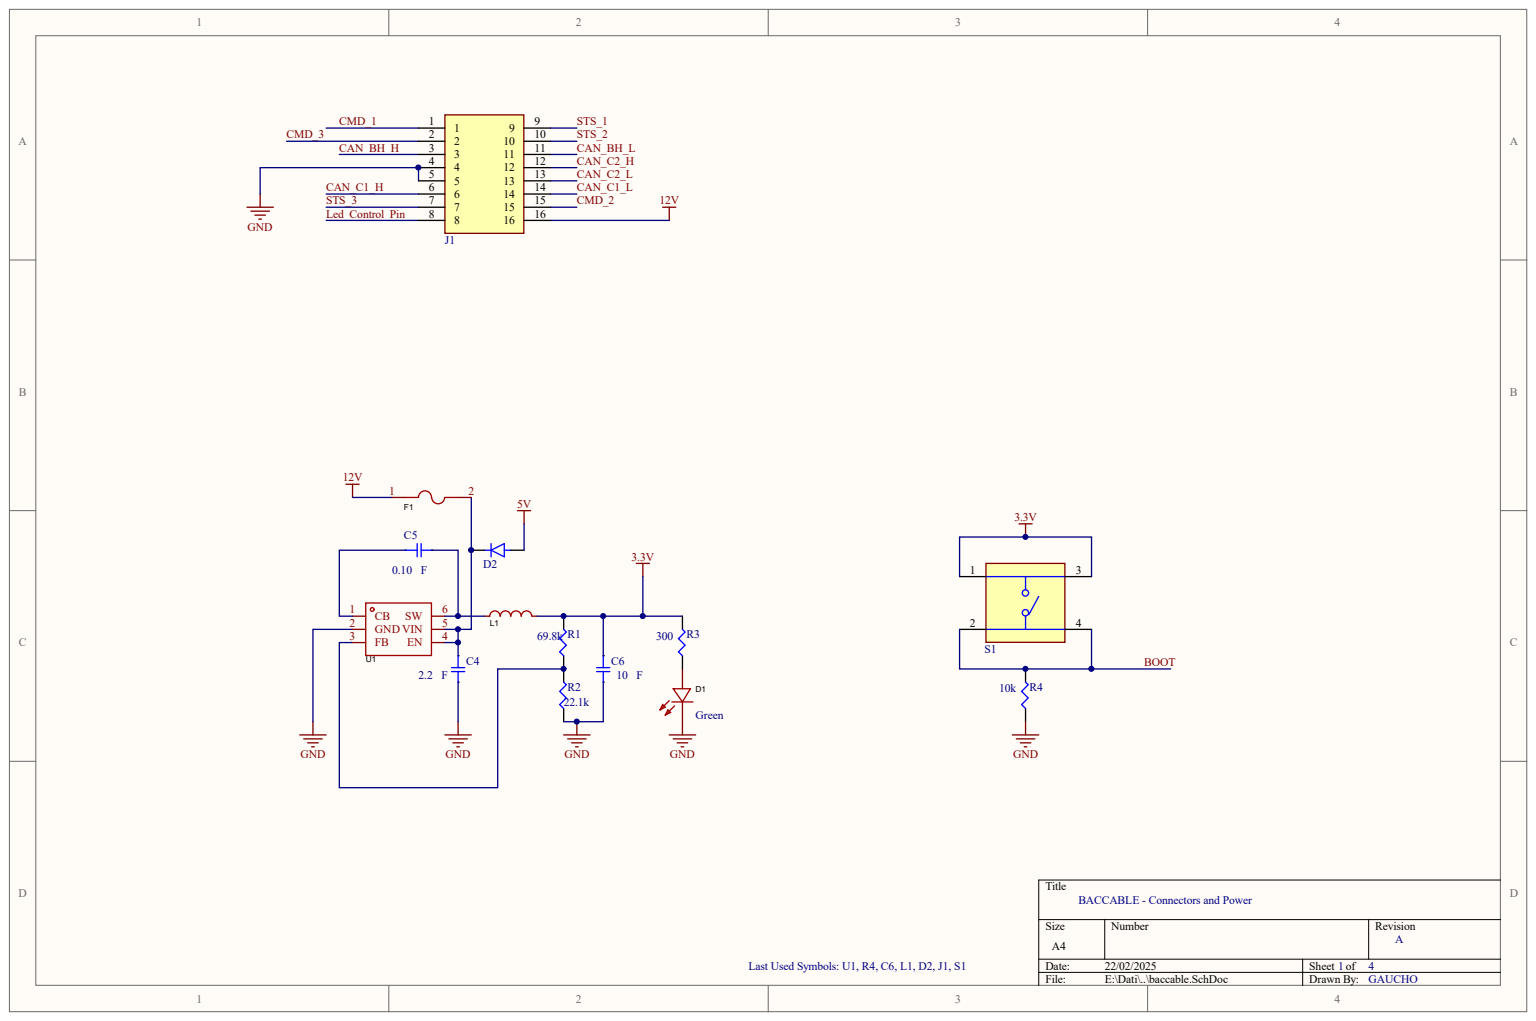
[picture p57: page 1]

Title
BACCABLE - Connectors and Power

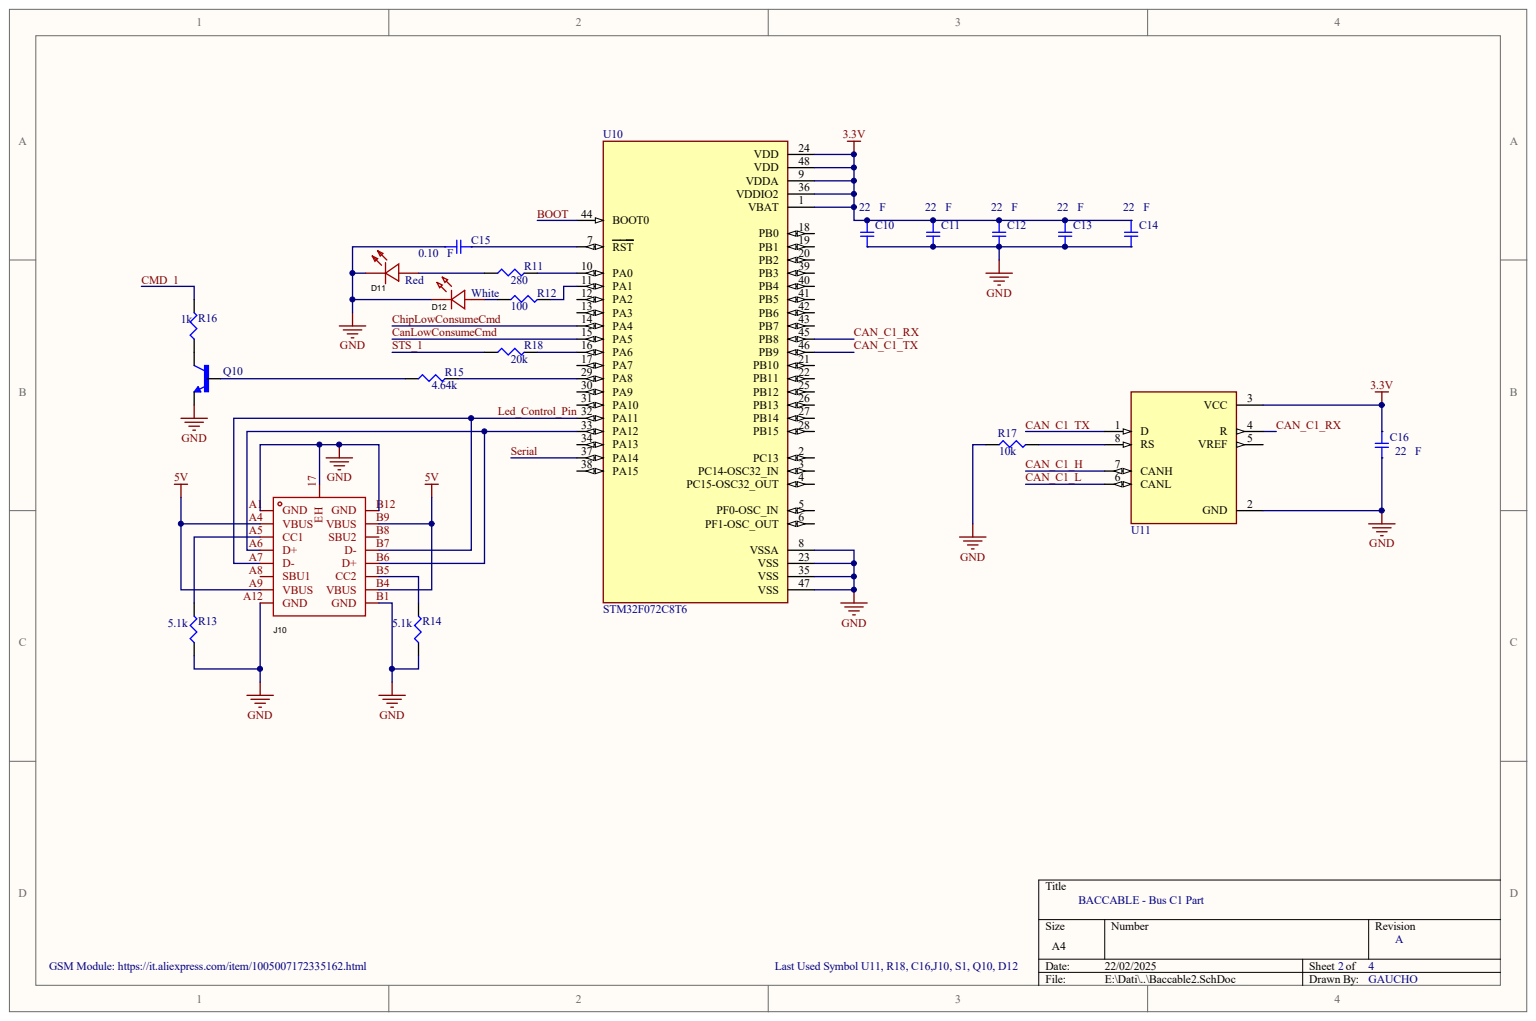
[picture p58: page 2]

4 8
3 6
1 | 2 2 F 2 2 F 2 2 F 2 2 F 2 | 2

2 3
3 5
4 7

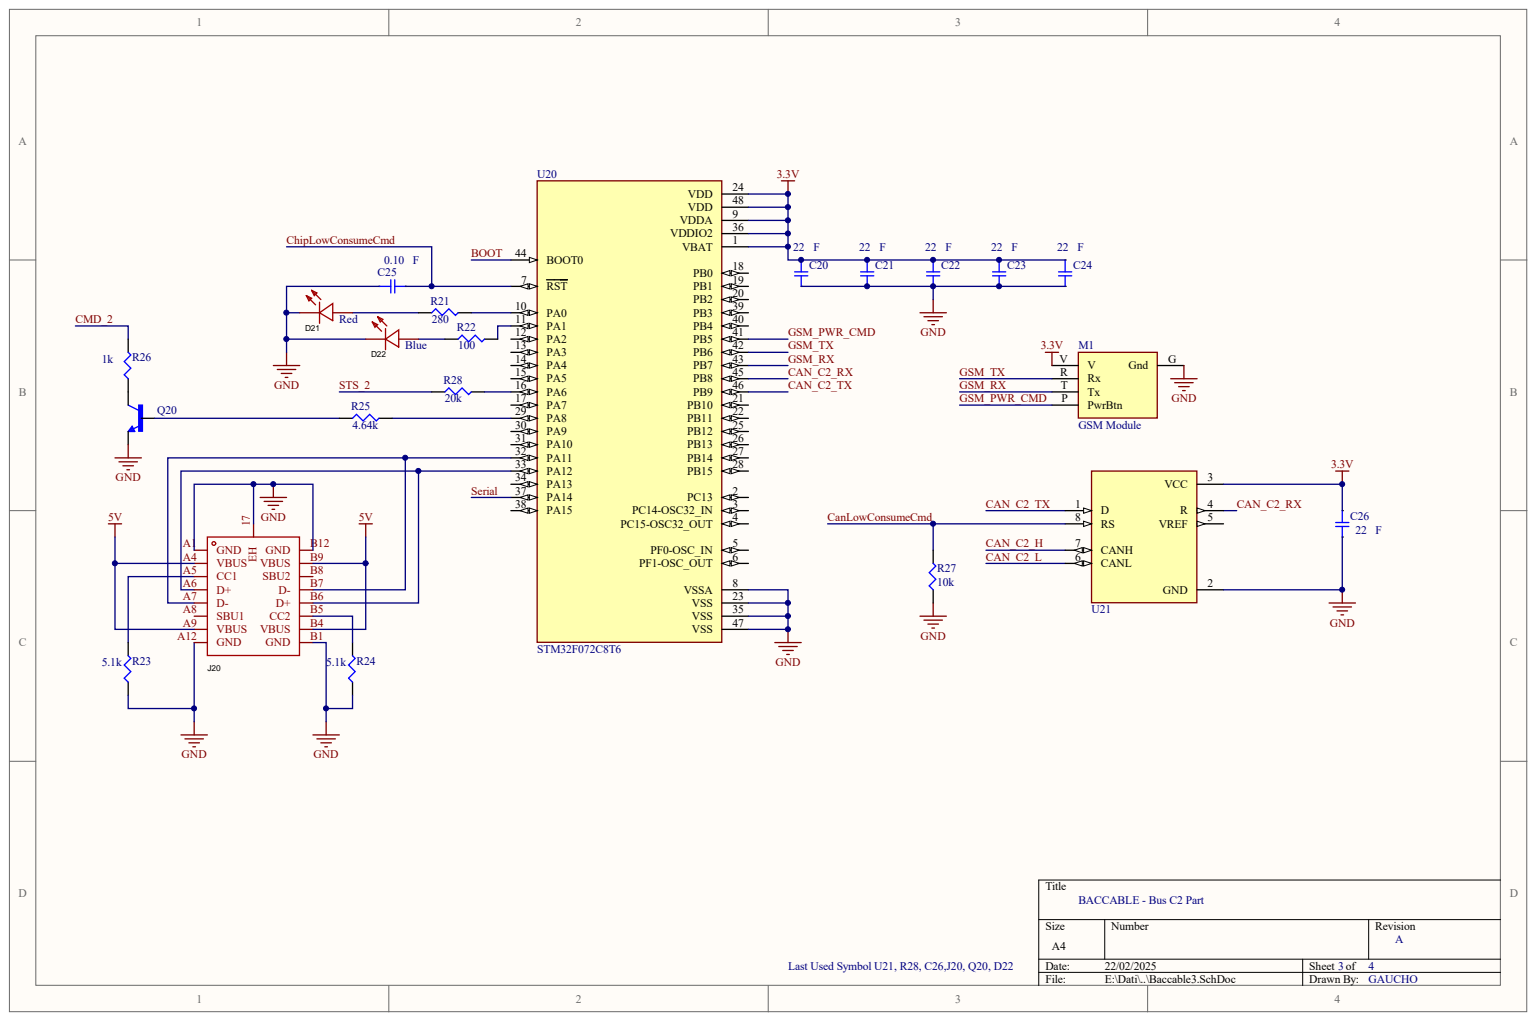
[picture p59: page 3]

4 8
3 6
1 | 2 2 F 2 2 F 2 2 F 2 2 F 2 | 2

2 3
3 5
4 7

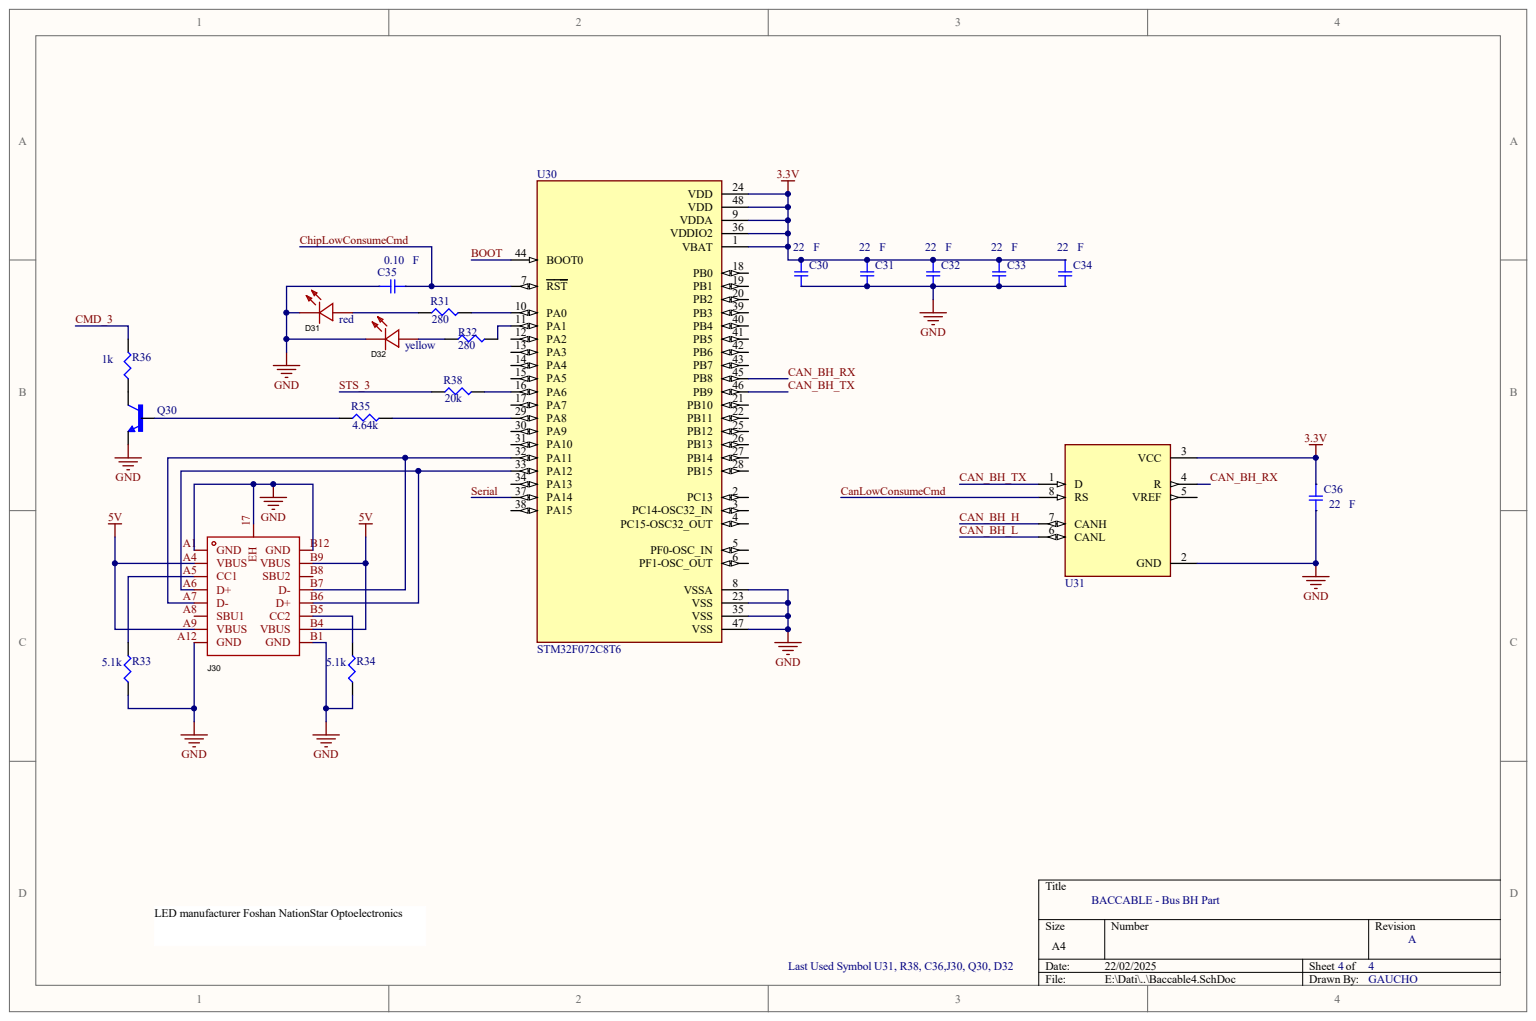
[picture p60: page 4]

4 8
3 6
1 | 2 2 F 2 2 F 2 2 F 2 2 F 2 | 2

2 3
3 5
4 7

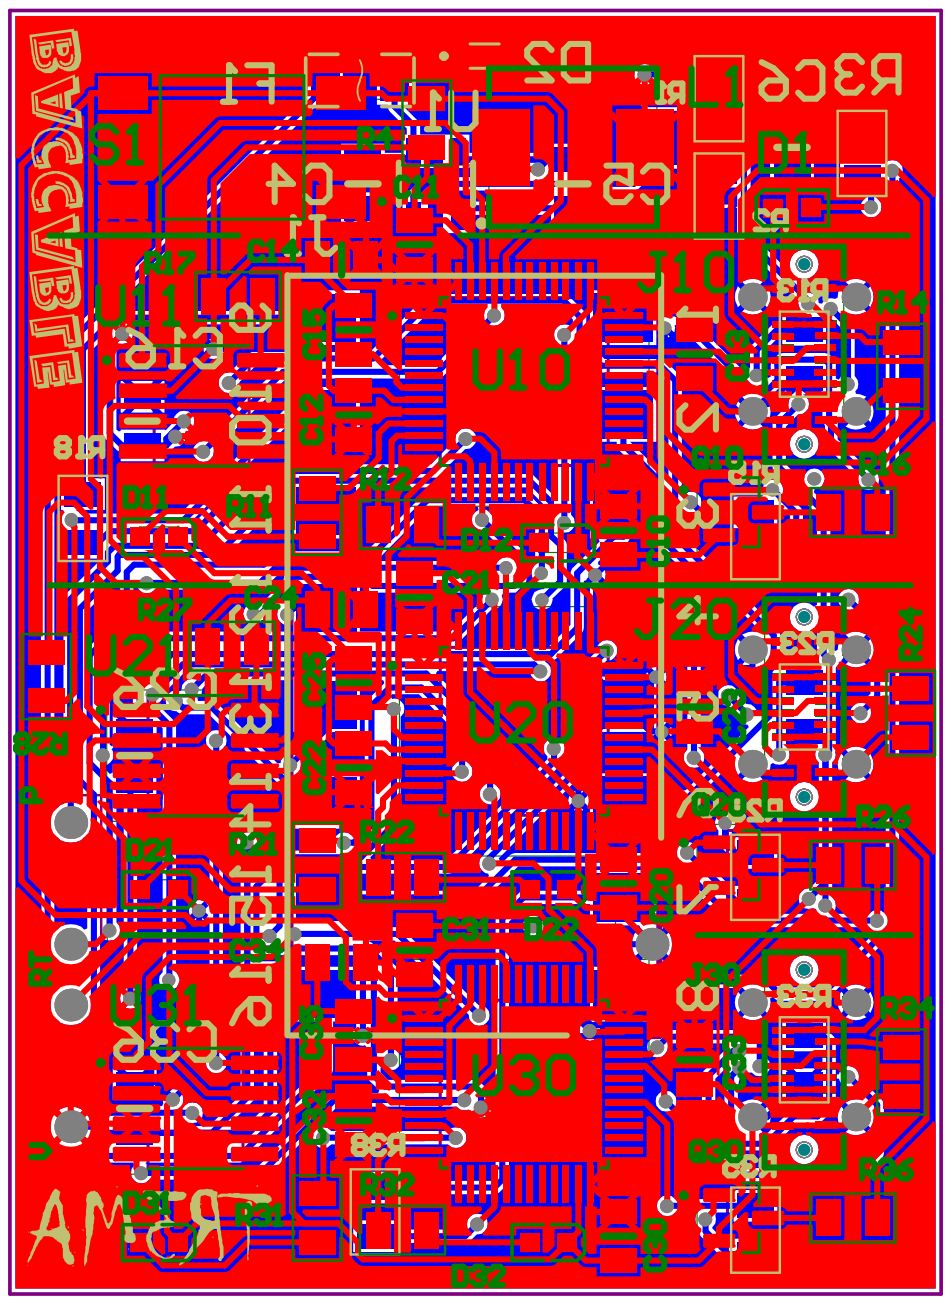
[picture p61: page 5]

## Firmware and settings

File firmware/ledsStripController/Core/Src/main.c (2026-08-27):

// the definition of ACT_AS_CANABLE shall be placed in main.h
#include "main.h"
#include "stm32f0xx_it.h"

int main(void){
	SystemClock_Config(); //set system clocks
	onboardLed_init(); //initialize onboard leds for debug purposes
	can_init(); //initialize can interface
	//onboardLed_red_on(); This line doesn't work cause hardware is still initiating
	#if defined(C1baccable)
		C1baccableInitCheck();
	#endif

	uart_init();


	#if (defined(BHbaccable) || defined(C2baccable))
		storage_init();
	#endif

	#if defined(ACT_AS_CANABLE) || defined(DEBUG_MODE) || defined(ENABLE_USB_MASS_STORAGE) || defined(ACT_AS_SCHIZZAFORTE_SERIAL_CONTROLLER)
		//because of condensation usb could fail and chip remain stuck. the following line,
		// ensures USB init only if we are coming from first powering and not from a reset.
		if(RCC->CSR & RCC_CSR_PORRSTF){
			//onboardLed_red_blink(2);
			MX_USB_DEVICE_Init(); //if first poweron, init usb port.
		}
		RCC->CSR |= RCC_CSR_RMVF; //delete reset flags


	#endif

	#if (defined(C1baccable) || defined(C2baccable) )  //if required, let's automatically open the can bus
		//let's open the can bus because we may need data
		can_set_bitrate(CAN_BITRATE_500K);//set can speed to 500kpbs
		can_enable(); //enable can port
	#endif

	#if (defined(BHbaccable) )
		BHbaccableInitCheck();
	#endif
		//HAL_Delay (100);

	while (1){

		currentTimeMainLoopDebug=currentTime;
		onboardLed_process();
		can_process();

		//elm327 function 26/08/2026 - while a host is really talking to the interpreter the inter chip serial
		//line belongs entirely to the diagnostic bridge: a message from the normal queue would collide with it
		//and put the link out of sync. Only skipped once a host is actually there, never while merely waiting.
		#if defined(C1baccable)
			if(!elm327_is_enabled())
		#endif
		processUART();

		#if defined(C1baccable) //elm327 function 26/08/2026
			elm327UsbStartIfRequested();		//usb bring up is done here, never from an interrupt
			elm327CheckActivationTimeout();		//switches the interpreter on once a host shows up, gives up if none does
			elm327_process();					//interprets one command per loop; does nothing while the mode is off
		#endif
		#if defined(C1baccable) || defined(C2baccable) || defined(BHbaccable) //elm327 function 26/08/2026 - does nothing until C1 arms the bridge
			elmlink_process();
		#endif

		#if defined(C1baccable)
			#ifdef DEBUG_START_SNIFFER //sniffer function 24/08/2026 - bench test with no vehicle connected: can bus is silent+loopback (see can.c), so this injected message follows the very same rx/interception path as real traffic, just below in this loop
				if(debugSnifferAutoStarted==0 && currentTime>=20000){
					debugSnifferAutoStarted=1;
					if(snifferFunctionEnabled==0){
						snifferFunctionEnabled=1;
						elm327FunctionEnabled=0;
					snifferStart(); //same entry point used by the SNIFFER menu toggle
					//notify to C2 and BH the sniffer function status
					uint8_t tmpArrSniffer[2]={C2_Bh_BusID,C2_Bh_cmdSnifferEnabled};
					addToUARTSendQueue(tmpArrSniffer, 2);
					saveOnflash();
				}
				}

			#endif

			#ifdef DEBUG_START_ELM327
				if(debugElm327AutoStarted==0 && currentTime>=20000){
					debugElm327AutoStarted=1;
					if(elm327FunctionEnabled==0){
						elm327FunctionEnabled=1;
						snifferFunctionEnabled=0;
						elm327Start();
						saveOnflash();
					}
				}
			#endif
		#endif

		#if defined(C1baccable) || defined(C2baccable) || defined(BHbaccable)
			snifferUsbStartIfRequested(); //sniffer function 24/08/2026 - usb re-enumeration is done here, never from an interrupt
			snifferUsbShutdownIfRequested(); //sniffer function 24/08/2026 - usb power down is done here too, for the same reason
			snifferCheckActivationTimeout(); //sniffer function 24/08/2026 - reverts to a plain baccable if the host never configures us within SNIFFER_ACTIVATION_TIMEOUT_MS

			#ifdef DEBUG_CAN_RX_SIMULATION //sniffer function 24/08/2026 - bench test with no vehicle connected: can bus is silent+loopback (see can.c), so this injected message follows the very same rx/interception path as real traffic, just below in this loop
				if(currentTime-debugSimulatedMsgLastInjectTime>=100){
					debugSimulatedMsgLastInjectTime=currentTime;
					CAN_TxHeaderTypeDef debugSimulatedMsgTxHeader;
					debugSimulatedMsgTxHeader.IDE=CAN_ID_STD;
					debugSimulatedMsgTxHeader.RTR=CAN_RTR_DATA;
					debugSimulatedMsgTxHeader.StdId=0x1EF;
					debugSimulatedMsgTxHeader.DLC=8;
					uint8_t debugSimulatedMsgTxData[8]={0,0,0,0,0,0,0,debugSimulatedMsgByteCounter};
					debugSimulatedMsgByteCounter++;
					can_tx(&debugSimulatedMsgTxHeader, debugSimulatedMsgTxData); //queued here, transmitted by can_process() on the next loop, looped back into the rx fifo
				}
			#endif
		#endif


		#if (defined(BHbaccable) || defined(C2baccable))
			//sniffer function 24/08/2026 - BEGIN
			//this used to pause huart2 (towards C1) while acting as usb pen drive, to avoid interfering with the file
			//transfer. disabled: STORAGE_Write_FS() always returns USBD_FAIL (writes are not implemented) and
			//STORAGE_Read_FS() only memcpy()s from flash, both trivially safe to interrupt on cortex-m0, so there is
			//no real interference to avoid with the current storage implementation. keeping huart2 paused here was
			//also a deadlock for the sniffer: pauseUart() disables the RX interrupt, so C2_Bh_cmdSnifferEnabled sent
			//by C1 while usbConnectedToSlave was already set could never be received to un-pause it.
			//if(currentTime>TIMING__C2_BH_USB_CONNECT_TO_C1_NOTIFICATION_DELAY_MS+300 && usbConnectedToSlave && snifferInUse==0){  //if we are using it as usb pen drive, stop serial line to avoid interferences
			//	pauseUart(&huart2); //stop serial line between chips
			//}
			//sniffer function 24/08/2026 - END
		#endif

		//elm327 function 26/08/2026 - feeds the interpreter with the bytes arrived from usb. Only while a host is
		//really there: with the mode off (or merely waiting) there is nothing on that port to read.
		#if defined(C1baccable)
			if(elm327_is_enabled()) cdc_process();
		#endif

		#if defined(ACT_AS_CANABLE) || defined(ACT_AS_SCHIZZAFORTE_SERIAL_CONTROLLER)
			cdc_process(); //processa dati usb
			//#if defined(ACT_AS_SCHIZZAFORTE_SERIAL_CONTROLLER)
			//	processUART1(); //process schizzaForte serial messages
			//#endif
			//just for test
			//char *data = "Hello World from USB CDC\n";
			//CDC_Transmit_FS((uint8_t*)data, strlen(data));
			//HAL_Delay (1000);

			//just for test, we can periodically send a packet to can bus
			//we can set the can bus in loopback mode, to receive back each sent message.
			// To set loopback mode, in function can_enable (can.c) we shall set can_handle.Init.Mode = CAN_MODE_LOOPBACK
			// This way we will receive whatever we send
			// Before to send can messages, speed shall be set and can port shall be enabled,
			//can_set_bitrate(CAN_BITRATE_500K);//set can speed to 500kpbs
			//can_enable(); //enable can port
			//Then we can prepare and send the following test packet
			//CAN_TxHeaderTypeDef testMsgHeader;
			//testMsgHeader.IDE= CAN_ID_STD;
			//testMsgHeader.RTR = CAN_RTR_DATA;
			//testMsgHeader.StdId=0x0412;
			//testMsgHeader.DLC=5;
			//uint8_t testMsgData[8] = {0};
			//testMsgData[0]=0x01;
			//testMsgData[1]=0x01;
			//testMsgData[2]=0x01;
			//testMsgData[3]=0x01;
			//testMsgData[4]=0xE6; //pedal position
			//can_tx(&testMsgHeader, testMsgData);
		#endif

		#if defined(C1baccable)
			//elm327 function 26/08/2026 - with a host actually talking to the interpreter the baccable steps
			//aside completely: no UDS requests of its own on the bus, no traffic towards the other two chips
			//(the serial line serves the bridge), no dashboard refresh. elm327Stop() puts everything back.
			if(!elm327_is_enabled()){
			processUART1();
			C1baccablePeriodicCheck();
			} //elm327 function 26/08/2026

			//wake up each 14 seconds for 3,5sec+ tmpCounter , just for testing
/*
			if ((currentTime - lastTrigger) >= 14000) {
				lastTrigger = currentTime; // new window begin
				tmpCounter++;
			}

			if ((currentTime - lastTrigger) < tmpCounter) lastReceivedCanMsgTime = currentTime;

*/
			//lastReceivedCanMsgTime = currentTime; //always awake, just for test

			//just for test
			//currentDNAmode=0;
			//currentRpmSpeed= 1000;
			//if(currentDNAmode==0 && (currentRpmSpeed> 400) && neverSaved && currentTime>10000){ //engine on and drive style Natural
			//	neverSaved=0;
			//	playMotorJingle=255;
			//}

			/*
			lastReceivedCanMsgTime = currentTime; //always awake, just for test
			currentRpmSpeed=1000;
			if ((currentTime - lastTrigger) >= 10000) {
				lastTrigger = currentTime; // new window begin
				QV_exhaust_flap_function_enabled=1;
				if (chineseValveIsOpened==0){ //if valves are closed,
					ChineseExhaustValveRequest='O'; //open request
				}else{
					ChineseExhaustValveRequest='C'; //close request
				}
			}
			*/

		#endif

		#if defined(C2baccable)
			C2PeriodicCheck();
			//ESCandTCinversion=1;
		#endif

		//if(ESCandTCinversion==1) onboardLed_red_on(); //just for test

		#if defined(BHbaccable) //this is the baccable slave
			BHperiodicCheck();
		#endif

		#if (defined(C1baccable) || defined(C2baccable) || defined(BHbaccable))
			if(clearFaultsRequest>0){
				//clear faults if requested
				if(currentTime-last_sent_clear_faults_msg>25){
					last_sent_clear_faults_msg= currentTime;

					#if defined(C1baccable)
						if(clearFaultsRequest==255){
							//ask to Baccable on C2 and bH bus, to reset faults //to be done
							uint8_t tmpArr[1]={AllResetFaults};
							addToUARTSendQueue(tmpArr, 1);
						}
					#endif
					//send a reset request
					clearFaults_msg_header.ExtId= 0x18DA00F1 | ((uint32_t)clearFaultsRequest<<8);
					can_tx(&clearFaults_msg_header, clearFaults_msg_data); //transmit the request

					clearFaultsRequest--;
				}
			}
		#endif

		// If CAN message receive is pending, process the message
		#if defined(C1baccable) || defined(C2baccable) || defined(BHbaccable)
			uint8_t snifferCanFramesRead=0; //sniffer function 24/08/2026 - counts the frames drained in this iteration
		#endif
		//elm327 function 27/08/2026 - with the interpreter running the frames are read inside elm327_process()
		//while it waits for the answer to a command: draining the fifo here would throw those answers away
		//before it ever sees them. The bridge slave does the same inside elmlink_process(). On C1
		//elm327_is_enabled() and elmlink_is_enabled() are always the same value (set together inside
		//elm327_set_enabled()), so the one flag covers the master and both slaves.
		#if defined(C1baccable) || defined(C2baccable) || defined(BHbaccable)
			if(elmlink_is_enabled()) goto skipCanRxProcessing;
		#endif
		while( is_can_msg_pending(CAN_RX_FIFO0)){ //sniffer function 24/08/2026 - was an if: with the sniffer on we empty the whole rx fifo
			// If message received from bus, parse the frame
			if (can_rx(&rx_msg_header, rx_msg_data) == HAL_OK){

				#if defined(ACT_AS_CANABLE)
					uint16_t msg_len = slcan_parse_frame((uint8_t *)&msg_buf, &rx_msg_header, rx_msg_data);
					onboardLed_blue_on();
					if(msg_len){
						CDC_Transmit_FS(msg_buf, msg_len); //transmit data via usb
					}
				#endif

				#if defined(C1baccable) || defined(C2baccable) || defined(BHbaccable)
					if(snifferInUse) snifferPushFrame(&rx_msg_header, rx_msg_data); //sniffer function 24/08/2026 - raw copy to usb, normal decoding below is untouched
				#endif

				#if defined(C1baccable)
					lastReceivedCanMsgTime=currentTime;
				#endif

				if (rx_msg_header.RTR == CAN_RTR_DATA){
					switch(rx_msg_header.IDE){
						case CAN_ID_EXT:
							processingExtendedMessage();
							break;
						case CAN_ID_STD: //if standard ID
							processingStandardMessage();
							break;
						default:
					}
				}
			}
			#if defined(C1baccable) || defined(C2baccable) || defined(BHbaccable)
				snifferCanFramesRead++; //sniffer function 24/08/2026
				if(snifferInUse==0) break; //sniffer function 24/08/2026 - unchanged behaviour when the function is off: one frame per iteration
				if(snifferCanFramesRead>=SNIFFER_CAN_FRAMES_PER_LOOP) break; //sniffer function 24/08/2026 - bounded by the rx fifo depth, keeps the loop short
			#else
				break; //unchanged behaviour on ACT_AS_CANABLE: one frame per main loop iteration
			#endif
		}

		#if defined(C1baccable) || defined(C2baccable) || defined(BHbaccable)
			skipCanRxProcessing: ; //elm327 function 26/08/2026 - the interpreter/bridge reads the fifo itself
		#endif

		#if defined(C1baccable) || defined(C2baccable) || defined(BHbaccable)
			if(snifferInUse) snifferFlush(); //sniffer function 24/08/2026 - non blocking, sends at most 64 bytes per iteration
		#endif

		//for debug, measure the loop duration
		if (currentTime-currentTimeMainLoopDebug>2){
			onboardLed_red_on();


		}
	}
}

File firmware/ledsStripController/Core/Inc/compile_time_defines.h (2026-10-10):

#ifndef INC_COMPILE_TIME_DEFINES_H_
#define INC_COMPILE_TIME_DEFINES_H_

	#ifdef INCLUDE_USER_CONFIG_H
		// In user_config.h file the user can set preferred defines for its own custom builds;
 		// Inside user_config.h.sample file you will find instructions about how to use it.
		#include <user_config.h>
	#endif

	//this is used to store FW version, also shown on usb when used as slcan
	#ifndef BUILD_VERSION //optional compile time define with -D, default: undefined
		#define BUILD_VERSION "V.3.7.17"  //versioning rule: first digit major change, second digit minor change (like new feature), third digit bug fix or cosmetics
	#endif
	#define _FW_VERSION "BACCABLE " BUILD_VERSION


	// force print
	#pragma message ("FW_VERSION: " _FW_VERSION)

	//WARNING: ACT_AS_CANABLE takes a lot of time to buffer and send packets to usb, therefore the main
	//         loop time duration increases. If you have C1baccable or C2baccable or BHbaccable, therefore can messages will
	//         start to be lost and some functions will not properly work. Then, if you use
	//         C1baccable, C2baccable or BHbaccable, it is recommended to comment ACT_AS_CANABLE.
	// 		   If the main loop duration increases too much, the device will not work properly and the
	//		   red led will start to continuously blink (you can find in the main loop, the loop duration check)


	//---------------------------------------------------------------------------------------------------------------------------
	// RELEASE_FLAVOR  is defined if compiling with gcc or STM32CubeIde, default is ACT_AS_CANABLE
	#ifndef RELEASE_FLAVOR

		//If user's building with "Release" or "Debug" build configuration or on command line wth just "make"
		//then it will get this configuration; other defines are here just for reference (C1, C2 and BH)
		#define ACT_AS_CANABLE
		//#define C1baccable
		//#define C2baccable
		//#define BHbaccable
	#else
		#if RELEASE_FLAVOR == CAN_FLAVOR
			#define ACT_AS_CANABLE
		#elif RELEASE_FLAVOR == C1_FLAVOR
			#define C1baccable
		#elif RELEASE_FLAVOR == C2_FLAVOR
			#define C2baccable
		#elif RELEASE_FLAVOR == BH_FLAVOR
			#define BHbaccable
		#endif
	#endif

	//display size
	#ifndef LARGE_DISPLAY//optional compile time define with -D, default: undefined
		#define DASHBOARD_MESSAGE_MAX_LENGTH 18
	#else
		#define DASHBOARD_MESSAGE_MAX_LENGTH 24
	#endif

	//This section sets ACT_AS_CANABLE if no option was selected
	#if !defined(ACT_AS_CANABLE) && !defined(C1baccable) && !defined(C2baccable) && !defined(BHbaccable)
		#define ACT_AS_CANABLE
	#endif


	#ifdef ACT_AS_CANABLE
		#pragma message("Building CANable") //adds a message in the compilation log
	#endif

	//elm327 function 26/08/2026 - BEGIN
	//The ELM327 interpreter and the diagnostic bridge towards the other two chips are always compiled into the
	//normal firmware and stay completely off (they touch neither usb, nor the can bus, nor the inter chip serial
	//line) until the ELM327 entry of the setup menu turns them on - exactly the same lifecycle as the sniffer.
	//There are deliberately no dedicated ELM327 build flavors and no per-bitrate build configurations here: the
	//can bus is the one the baccable already has open at the right speed for its own network, and the runtime
	//guards inside elm327.c/elmlink.c leave it alone.
	//elm327 function 27/08/2026 - ELM327_RUNTIME_SELECTABLE, ELMLINK_MASTER, ELMLINK_SLAVE and
	//ELMLINK_RUNTIME_SELECTABLE used to live here: each of them was just another name for a chip we already
	//identify, so elm327.c/elmlink.c now test C1baccable / C2baccable / BHbaccable directly (C1 is the gateway,
	//C2 and BH are the two slaves, and all three take the mode from the menu, never at power on).
	#if defined(C1baccable)
		#define ACT_AS_ELM327				//compiles elm327.c
		#define ELM327_TRACE_DISABLE		//the ATLOG dialog recorder is a development aid and costs 2kB of ram we do not have
		#define ELM327_BITRATE_STR	"500"	//only used in the ATDP answer: the C1 network runs at 500 kbit/s (see main.c)
	#endif

	//which of the two networks this slave serves: the only elmlink setting that really carries a value, so
	//unlike the ones listed above it cannot be replaced by the chip name alone. //elm327 function 27/08/2026
	#if defined(C2baccable)
		#define ELMLINK_SLAVE_ID	ELMLINK_TO_C2
	#elif defined(BHbaccable)
		#define ELMLINK_SLAVE_ID	ELMLINK_TO_BH
	#endif
	//elm327 function 26/08/2026 - END

	#ifndef DISABLE_UCAN_BOARD_LED_INVERSION //optional compile time define with -D, default: undefined
		#define UCAN_BOARD_LED_INVERSION //ucan fysect board (and  new BACCAble board) requires UCAN_BOARD_LED_INVERSION, since the led onboard are physically connected differently (status is inverted)
	#else
		#pragma message("Canable Board is used")
	#endif

	//optional compile time defines for C1
	#ifdef C1baccable //this works only on C1 can bus (OBD port pins 6 and 14)
		#pragma message("Building C1 BACCAble") //adds a message in the compilation log
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

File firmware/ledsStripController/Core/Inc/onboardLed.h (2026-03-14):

#ifndef _LED_H
	#define _LED_H

	#include "globalVariables.h"

	#define LED_BLUE_Pin GPIO_PIN_1
	#define LED_BLUE_Port GPIOA
	#define LED_BLUE LED_BLUE_Port , LED_BLUE_Pin

	#define LED_RED_Pin GPIO_PIN_0
	#define LED_RED_Port GPIOA
	#define LED_RED LED_RED_Port , LED_RED_Pin

	//used only for start&stop car disabler functionality
	#define START_STOP_DISABLER_Pin GPIO_PIN_14
	#define START_STOP_DISABLER_Port GPIOA
	#define START_STOP_DISABLER START_STOP_DISABLER_Port , START_STOP_DISABLER_Pin

	#define Q10mosfet_Pin GPIO_PIN_8 //PA8
	#define Q10mosfet_Port GPIOA
	#define Q10mosfet Q10mosfet_Port , Q10mosfet_Pin

	#define Q11mosfet_Pin GPIO_PIN_7 //PA7
	#define Q11mosfet_Port GPIOA
	#define Q11mosfet Q11mosfet_Port , Q11mosfet_Pin

	#define LED_DURATION 25

	void onboardLed_init();
	void onboardLed_blue_blink(uint8_t numblinks);
	void onboardLed_red_blink(uint8_t numblinks);
	void onboardLed_red_on(void);
	void onboardLed_red_off(void);
	void onboardLed_blue_on(void);
	void onboardLed_blue_off(void);
	void onboardLed_process(void);

#endif

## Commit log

2024-06-23 restyled to better implement immobilizer
    [GVRET_Log.csv, GenericID_Log.csv]
2024-07-01 update drawing for vertical representation
    [SCHEMA_DI_INTERCONNESSIONE.dwg]
2024-07-22 buttons sequence - immobilizer
    added buttons sequence detection (to start/stop panic alarm with wheel buttons sequence)
2024-08-03 updated immobilizer function and added messages filtering to improove processing time
2024-08-14 final corrections on immobilizer function
    [main.c]
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2024-12-29 added comments. corrected gear field
    added comments with new parameters decoding, in order to be ready to add more decodings in code
    [main.c]
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2025-01-05 corrected ESP&TC disabler functionality - started testing with text printing on dashboard
    [main.c]
2025-01-29 immo, start&stop dashvoard (see details in the full description of the change and in the readme)
    corrected bug that avoids the immobilizer to properly work (inserted for error during latest tests)
    changed function to show parameters on dashboard both for slave and master baccable
    added function to disable start&stop with only message on C1 can bus
    changed function immobilizer in order to allow the disabling and enabling of the function with button press.
    added a lot of messages decoding in the readme and inside code.
    [Assembly1.iam, Open CASCADE STEP translator 7.5 1.0001.ipt, Open CASCADE STEP translator 7.5 1.ipt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]
2025-01-29 minor bug fix on immo disabling function
    nn
    [main.c]
2025-01-30 minor bug fix on start&stop. cosmetics changes
    [main.c]
2025-02-03 params on dashboard function
    some bug solving and new params on dashboard function. I added dyno mode too but still doesn't work
    [can.c, main.c, uart.c]
2025-02-05 bug correction in ROUTE_MSG functionality
    [main.c]
2025-02-05 bug solved in ROUTE_MSG function
    [main.c]
2025-02-05 bug solved in ROUTE_MSG functionality
    [main.c]
2025-02-09 improved smart Start&stop and parametrsOnDashboard
    smart start & stop now operates each time the motor is restarted without the need of power cycle of baccable
    parameters on dashboard now disables commands when ACC is enabled). ACC users reproted that menu commands were enabled with acc enabled. bug solved!
    [baccable.ioc, main.c]
2025-02-22 bug solved in showParamsOnMasterBaccable - new functtion VirtualACCPAd
    bug solved in showParamsOnMasterBaccable (it avoids to change parameters if you have ACC enabled
    new functtion VirtualACCPAd: allows to enable ACC with CC button and change distance with RES button
    [main.c]
2025-02-22 bug solved in virtual_ACC_Pad function
    [main.c]
2025-02-27 bug correction in shift functionality for IPC my23
    [main.c]
2025-03-01 bug correction on shift function for IPC my23
    [main.c]
2025-03-01 bug correction in Virtual_ACC_pad functionality. now it works
    [main.c]
2025-03-01 change in baccable slave to show our string also if radio prints a radio name
2025-03-01 bug correction in shift for my23. added DIESEL include and declaration of parameters array for gasoline engine
    [main.c]
2025-03-01 bug correction in VIRTUAL_ACC_PAD
    [main.c]
2025-03-02 bug solved in baccable slave (radio prints was always hidden)
    [main.c, uart.c]
2025-03-02 small bug correction in slave baccable
    [uart.c]
2025-03-02 test to improve slave baccable. possible bug solving on master
    [uart.c]
2025-03-03 finally solved the problem on radio messages overwriting baccable slave strings
    [main.c]
2025-03-07 bug correction (highlighted when enabling only accVirtualPad or SmartStart&Stop functionalities
    [lowConsume.c, lowConsume.h, main.c]
2025-03-09 added LOW_CONSUME function, to be used only with new BACCABLE board
2025-03-17 experimental not working remote start and some bug fix
    [main.c, uart.c]
2025-03-22 introduced new case
    [FullCaseWithBaccable.iam, cover.ipt, cover.stl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]
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2025-04-12 new management of params in a setup menu. many changes
    [FullCaseWithBaccable.0012.iam, FullCaseWithBaccable.iam, cover.0030.ipt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]
2025-04-13 corrected gear display
2025-04-14 bug fix - some compilation options were not managed and retunred errors during compilation
    [main.c]
2025-04-14 safety bug corrected. dyno, front brake and 4wd can now be activated only if speed is zero.
    [main.c]
2025-04-15 reduced shift threshold increase in setup menu. now the step is 250 rpm
2025-04-20 bug solved on clear faults and management of uart frame error
    [main.c, onboardLed.c, uart.c]
2025-04-23 bug solved in Start&stop function
    [main.c]
2025-04-26 bug solved on function 4wd .
    bug solved on function 4wd . with previous version, if you enable 4wd and switch off the car forgetting to restore its condition, the battery could get discharged,
    [main.c]
2025-04-26 corrected parameter RAIL for diesel engine (value in bar now shows 2 decimal digits)
    [main.c]
2025-04-27 updated rail parameter for diesel, by replacing its ID.
2025-05-03 divided main in more files and DPFregen. function update
    divided main in more files. now defines are in globalVariables.h.
    DPF regen function now uses different message as trigger
    now you can use RES button and DISTANCE button with the same effect, to enter menu, and to select functions.
2025-05-12 moving compile time #define's to dedicated header (#19)
    * moving compile time #define's to dedicated header
    * led inversion example
    * optional user config and additional examples
    * pragma messages
    * addressing review
    * addressing required changes
    * addressing comments
    * CFLAGS on continuous builds
    * fixing compile messages
    [compile_time_defines.h, globalVariables.h, processingStandardMessage.c]
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2025-05-24 updated user_config.h.sample template . corrected bug that was disabling the regeneration alert
    [compile_time_defines.h, globalVariables.c, globalVariables.h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]
2025-05-24 corrected unwanted .sample in the uer_config include
    [compile_time_defines.h]
2025-05-31 bug correction on Immo
    [compile_time_defines.h, functions_C1baccable.c]
2025-06-02 bug solved in immo enhancement and new functionality Launch assist Added
    [compile_time_defines.h, functions_C1baccable.c, globalVariables.c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]
2025-06-03 bug correction to launch assist function
    [compile_time_defines.h, functions_C1baccable.c]
2025-06-04 bug solved to show "stop the car" for one second
    [functions_C1baccable.c, globalVariables.c, globalVariables.h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]
2025-06-10 Hinting to make a copy of user_config.h.sample (#24)
2025-06-11 bug solved on Best Statistic Param
    [compile_time_defines.h, functions_C1baccable.c]
2025-06-14 added PERMANENTLY_DISABLE_IMMO in user_config.h . improovement under test for front brake function.
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2025-06-14 safety bug corrected affecting front brake functionalities
    [functions_C1baccable.c, functions_C2baccable.c, globalVariables.c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]
2025-06-14 inversion in status of dyno (for front brake enabling) corrected
    [processingMessage0x000002FA.c]
2025-06-15 bug solved. dyno status now is notified from slave to master
    [globalVariables.c, globalVariables.h, lowConsume.c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]
2025-06-20 added function to disable/enable seatbelt alarm and parameters corrections
    parametrers:
    added param seaatbelt alarm status
    corrected param rail, for diesel
    added exaust gas for diesel
    corrected exaust gas for gasoline
    corrected catal for gasoline
    corrected unAir for gasoline
    [compile_time_defines.h, functions_C1baccable.c, globalVariables.c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]
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2025-06-21 bug correction. the solved bug could discharge battery
    [compile_time_defines.h, functions_C1baccable.c]
2025-06-25 minor change on comments. added pedal booster cable wiring diagram
2025-07-22 bug solved in odometer blink function acting when BH chip returns from sleep forgetting the required setting
    [compile_time_defines.h, functions_C1baccable.c, globalVariables.c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]
2025-08-03 improved function ESC/TC and DPF REGEN ALERT
    ESC/TC function: now race screen is enabled
    REGEN ALERT: added time integration to avoid the alert to appear and disappear during regeneration
    [compile_time_defines.h, globalVariables.c, globalVariables.h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]
2025-08-06 added function show race mask
    show race mask let's choose if the ESC/TC functionality includes the visibility of RACE mask or no. It is a test version.
2025-08-08 bug solved in ESC/TC function (with SHOW RACE MASK enabled)
    [compile_time_defines.h, uart.c]
2025-08-10 bug correction in show race mask function
    [compile_time_defines.h, processingStandardMessage.c]
2025-08-12 bug solving in Park Mirror function
    [functions_BHbaccable.c, globalVariables.c, globalVariables.h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]
2025-08-12 bug correction in park mirror function
    [functions_BHbaccable.c, globalVariables.c, globalVariables.h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]
2025-08-12 bug correction in Park Mirror functionality
    [compile_time_defines.h, uart.c]
2025-08-12 bug solving PARK MIRROR functionality
    [processingStandardMessage.c]
2025-08-12 bug solved in function PARK MIRROR functionality
    [compile_time_defines.h, functions_BHbaccable.c, globalVariables.c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]
2025-08-14 bug correction on Show Race Mask function
    [compile_time_defines.h, processingStandardMessage.c]
2025-08-18 bug correction in ACC Autostart function
    [processingMessage0x000002FA.c]
2025-08-21 added param GEARBOX for DIESEL (oil temperature of the gearbox)
2025-08-22 bug solved in PARK MIRROR function.
    Increased time to return to operative position. Interrupted if final position was reached.
    [compile_time_defines.h, functions_BHbaccable.c, functions_C1baccable.c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]
2025-08-24 bug solved in function WINDOWS CLOSE
    [processingStandardMessage.c]
2025-08-25 Updated setup menu: close windows and open windows
    Close Windows disattivato: non altera il comportamento del veicolo
    Close Windows 1 attivato:
    Azione: singola attuazione della chiusura veicolo con chiave -> Reazione: si chiudono le portiere e i finestrini
    Azione: doppia attuazione della chiusura veicolo con chiave (meno di 3 secondi tra due attuazioni) -> Reazione: si chiudono le portiere e i finestrini, poi i finestrini si riaprono per 3 centimetri.
    Close Windows 2 attivato:
    Azione: singola attuazione della chiusura veicolo con chiave -> Reazione: si chiudono le portiere
    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
2025-08-25 bug solved in park mirror and close window
    [processingStandardMessage.c]
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2025-08-26 small bug in param couples
    [compile_time_defines.h, globalVariables.c]
2025-08-27 bug correction on param couples and added one couple
    [compile_time_defines.h, functions_C1baccable.c, globalVariables.c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]
2025-08-31 bug solved in park mirror
    increased time to return to operative position in park mirror function.
    [compile_time_defines.h, functions_BHbaccable.c, globalVariables.c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]
2025-09-04 added HAS function on LANE button press. It works only on some Giulias where HAS btn flows on C2 bus
2025-09-06 added Lane button double tap identification
    added Lane button double tap identification for newer giulias too. updated function HAS (enable and disable with LANE double TAP).
    updated ESC/TC function (toggle with lane long tap, for newer giulias too).
    Now esc/tc function is no more available (with LANE button long press) if function ESC/TC is disabled in setup menu
2025-09-07 bug solving test for HAS function and ESC/TC
    [globalVariables.c, processingMessage0x000002FA.c, uart.c]
2025-09-09 bug correction on function Lane. Has temporary disabled.
    [compile_time_defines.h, globalVariables.c, processingStandardMessage.c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]
2025-09-13 Corrected bug on LANE button press. HAS and ESC/TC now works corerectly. bug correction on SETUP page for params (hide show). last param was not shown. now it works.
    [functions_C1baccable.c, globalVariables.c, globalVariables.h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]
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2025-09-24 corrected adblue percentage param
    [compile_time_defines.h, globalVariables.c]
2025-09-28 added function to save log on file (test) and added function to force open QV exhaust valve
    -added new function and menu to write Log to File (just for test it saves test file). Now BH and C2 shows file when connected to usb, as it was a usb pen drive
    - added function to force QV exhaust valve open with double tap on Release button (button on gear shift lever)
2025-10-03 acc autostart works now with RES or with speed+ button
    correction on acc autostart function
    some improovement to ensure function stopping upon engine off
    [compile_time_defines.h, functions_C1baccable.c, globalVariables.c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]
2025-10-04 batttery param for gasoline change. low consumption logic change.
    1)changed the log of low consume, in order to avoid dcdc to work in PFM. this increases little bit the consumption, but avoids intereferences with rfid 125khz of the keyless entry system
    2)updated battery percentage param (single value) for gasoline.
    [compile_time_defines.h, globalVariables.c, lowConsume.c]
2025-10-04 battery SOC correction
2025-10-05 added reset statistics on main menu
    [functions_C1baccable.c, globalVariables.c, processingMessage0x000002FA.c]
2025-10-05 bug correction in open valves function
    [compile_time_defines.h, functions_C1baccable.c]
2025-10-06 bug solved in quadrifoglio valve opening function
    [compile_time_defines.h, functions_C1baccable.c, globalVariables.c]
2025-10-09 bug correction in function ACC autostart
    acc autostart message is sent one time each 2 seconds instead of each 320msec. avoids speed to increase when car is started but speed is still 0km/h
    [compile_time_defines.h, globalVariables.c, globalVariables.h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]
2025-10-12 bug correction in Acc Autostart function. restored BatteryStateOfCharge param as it was before
    [compile_time_defines.h, globalVariables.c, globalVariables.h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]
2025-10-12 bug correction in function acc autostart
    [compile_time_defines.h, processingMessage0x000002FA.c]
2025-10-23 bug correction on HAS function. Now brakes status too is used
    [compile_time_defines.h, globalVariables.c, globalVariables.h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]
2025-10-25 Bug blocked functions when menu hidden.
    Found a bug that inhibited serial communication between C1-C2-BH when the baccable menu was disabled (hidden). It prevented the activation of certain functions such as HAS when the menu was not displayed
    [compile_time_defines.h, functions_C1baccable.c, globalVariables.c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]
2025-11-08 improoved UART message sending better managing frame error condition and concurrent race
    [compile_time_defines.h, functions_Common.c, globalVariables.c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]
2025-12-07 structural change. see detailed description for details
    1)structural change to allow free selection of param coupes. now params are defined in uds_parameters file.
    2)removed params customization from user_config, previously added by Alessandro. This was dome since it is not required. Params are defined in uds_parameters file.
    3)removed the unuseful compilation options: debug, release, gasoline.
    4)this version does not set to low consume the transceivers, in order to allow boards with poor filtering to generate interferences
    5)this version disables the usb pen drive function, causing some instability, currently under investigation
    [compile_time_defines.h, functions_C1baccable.c, functions_Common.c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]
2025-12-30 debug changes
    [0510210200.ipt, 0510210200.stp, FullCaseWithBaccable.0012.iam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]
2026-01-08 debug version. added automatic C1 board reset in case of hard fault
    [compile_time_defines.h, functions_C1baccable.c, functions_Common.c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]
2026-01-29 bug solving on C1, related to low Consume logic
    [compile_time_defines.h, functions_C1baccable.c, functions_Common.c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]
2026-02-11 c1 bug apparently gone
    [compile_time_defines.h, functions_Common.c, globalVariables.c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]
2026-02-17 improovement solving crash with condensation on pcb
    condensation on pcb is causing usb pin protection and chip block. solved by appling usb init only on first boot and not on subsequent resets. So that now problem never occurs, even when coming out from the fridge
    [compile_time_defines.h, functions_Common.c, main.c]
2026-02-27 regression (bug) solving on esc/tc function. introduction of pedal booster function (still not complete)
    [compile_time_defines.h, functions_C1baccable.c, functions_Common.c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]
2026-02-28 optimization of pause and restart uart functions and uart error callback
    [compile_time_defines.h, lowConsume.c, main.c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]
2026-03-14 added schizzaforte serial Interface and transistors control (chinese valves radiocontrol commands)
    completed and tested SchizzaForte serial interface.
    added control of transistors Q10 and Q11 on C1. they are controlled together with exhaustValves function. QV can bus messages are sent on C1, and simultaneously radiocontrol buttons of chinese valves radiocontrol are pressed by means of baccable transistors control (they replace manual buttons of the radiocontrol)
    [cover_withoutBaccableText.ipt, cover_withoutBaccableText.stl]
2026-03-22 bug solved in pedal booster
    bug solved in pedal booster
    Solved bugs:
    - pedal power was not applied (to appy it you were forced to change map)
    -after a car sleep event the schizzaForte forgets set map and baccable was not repeating the map set request. now the engine speed is used to trigger a new map set
    [compile_time_defines.h, functions_C1baccable.c, processingMessage0x000002FA.c]
2026-03-23 test for light animation (still not working)
    [globalVariables.c, globalVariables.h, processingStandardMessage.c]
2026-06-02 updated pedal booster kids Limiter option
    updated pedal booster kids Limiter option:
    a)accelerator set to zero if:
    1) rpm overcomes 3000rpm (diesel) or 4000(gasoline)
    2) speed overcomes 100km/h
    b) pedal map forced to A with pedal power -10
2026-07-25 corrected param.battery SOC
2026-08-12 added spanish manual. improoved park mirror. added read faults and pump force
    added spanish manual.
    improoved park mirror to pause between left and right arrow
    improved park mirror to remain in position for 10 seconds after reverse gear is removed.
    added test to pump force function (not working)
    added test for read faults function
    [compile_time_defines.h, functions_BHbaccable.c, functions_C1baccable.c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]
2026-08-18 dded function to disable front parking sound, improved some other functions
    - added function to disable front parking sound if car is steady and rear gear is not engaged
    - increased times for open and close windows function (ensires they closes and increases a little bit the opening.
    - reduced time to disable immobilizer from 40seconds to around 20.
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2026-08-26 improved sniffer function (activated once enabled in main setup menu, remains active after power cycle too. becomes inative when usb get unplugged)
2026-08-27 Added Elm327 Function in main setup menu. now it acts as a VLINKER (usb on C1, and communicates with all the bus C1,C2,BH from a single usb connector). tested on a bench, will be tested on veichle by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
2026-08-27 Aggiunte sui manuali le nuove funzioni di caricamento firmware da smartphone, sniffer, park Mute, elm327. aggiunta traduzione in russo e polacco
2026-08-28 bug solved in elm327 function
    [compile_time_defines.h, uart.c]
2026-08-28 bug corrected on park mirror. improvement on park mute function
    [compile_time_defines.h, functions_BHbaccable.c, processingStandardMessage.c]
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2026-09-13 bugs solved
    dyno: after engine shutdown now it sets dyno disabled
    park mute: after rear gear is set, now, if sensors are disabled (led on), it simulates park sensors button press in order to reenable them.
    [compile_time_defines.h, processingStandardMessage.c]
2026-09-20 park mute test (test using different message to get brake pedal position, to be compatible with all veichles versions
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2026-10-04 added debug print in sniffer function, to debug dyno and 4wd functions
2026-10-05 added param couple EGR command & status. added debug print (to sniffer) for function read faults
2026-10-05 bug correction in function READ FAULTS
    [compile_time_defines.h, functions_C1baccable.c, globalVariables.c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]
2026-10-10 bug corrections. improved functions read faults and park mute
    nuova beta online. sintesi delle modifiche 1)aggiornata funzione ParkMute per renderla compatibile con tutte le annate dei veicoli (legge pressione freno su C1 e lo inoltra a C2). 3)Aggiunto parametro singolo con percentuale di pressione del pedale del freno. 4)aggiunta su read Faults la lettura dei guasti su ECM(Motore o Engine) e ABS. Aggiornata applicazione windows e android per corregger un baco che corrompeva i primi messaggi sniffati.
    [compile_time_defines.h, functions_C1baccable.c, functions_C2baccable.c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]
2026-10-13 new function Exhaust Flap DR . Bug correction in immo function
    Nuova funzione Exhaust Flap DR: con la prima opzione (attuale exhaust flap) vengono aperte le valvole di scarico cinesi (o della quadrifoglio) col doppio click sulla leva del cambio o col toggle dal menu mentre la seconda opzione (exhaust flap DR) apre le valvole nello stile di guida D e R. Inoltre viene ricordata l’impostazione al riavvio del veicolo
    Corretto baco nella funzione Immobilizer: ora è possibile attivare e disattivare l'immobilizer anche quando la spia motore è accesa. questa spia precludeva le azioni dell'utente, era un baco.
2026-10-13 bug fix in park mute (to avoid unwanted sensors disabling when R is engaged
2026-10-18 added DNA Memory Function (restores latest selected drive style after power cycle)
